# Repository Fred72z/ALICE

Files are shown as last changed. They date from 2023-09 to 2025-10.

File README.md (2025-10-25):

# EXTENSION MULTIPORTS ALICE #

Cette extension permet d'étendre les possibilités des ordinateurs MATRA ALICE (4K, 32 et 90).
Elle ajoute :
 - 2 Ports joystick DB9
 - 16K de RAM
 - 2 ports d'extension à l'arrière identiques à celui de l'ALICE
 - un port cartouche sur le dessus.

Elle est aussi compatible avec le MATRA MC10 (identique à l'ALICE 4K).

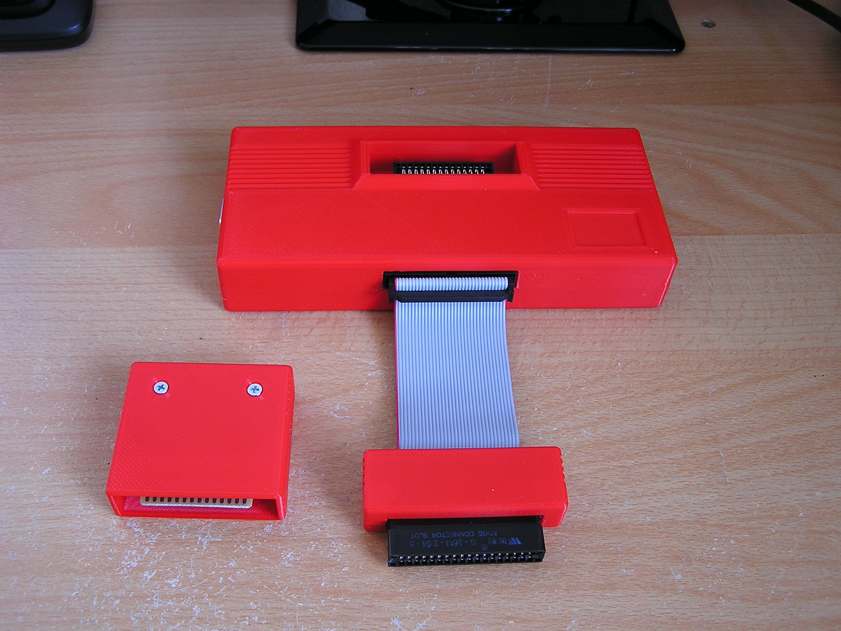
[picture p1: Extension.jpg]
Extension multiports Optional Title


Ce projet a été réalisé conjointement avec 6502man pour la partie software.

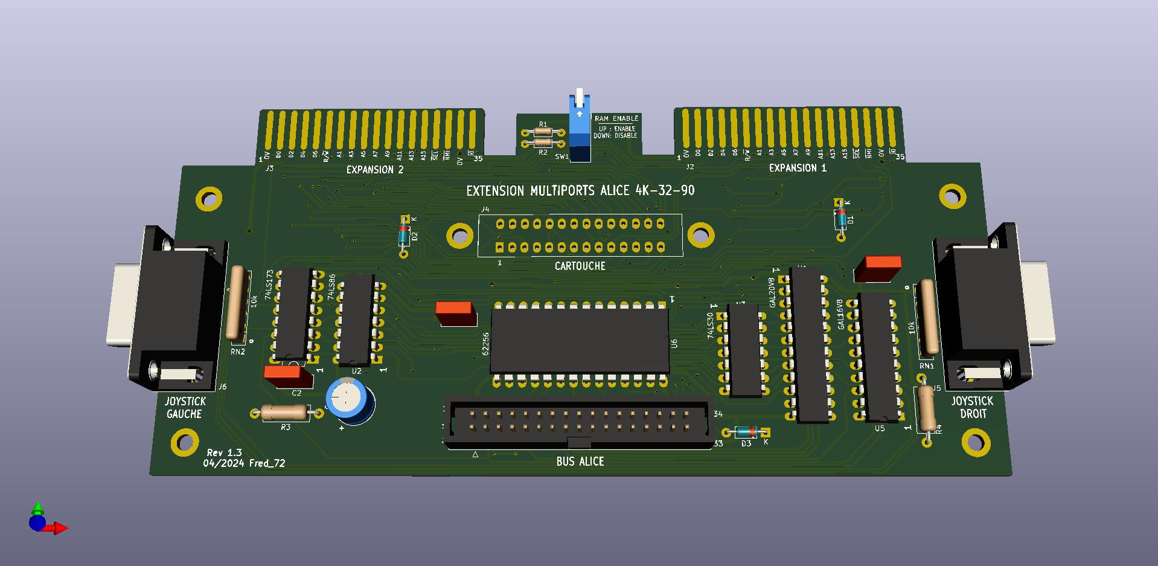
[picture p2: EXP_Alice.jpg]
Platine principale Optional Title


 Ports joystick :\
 Les ports joystick sont compatibles avec l'extension joystick commercialisée à l'époque.
 Ils occupent les adresses $BF30 (48944) pour le joystick droit et $BF34 (48948) pour le joystick gauche.
 
 RAM :\
 La RAM de 16Ko occupe les adresses [$5000-8FFF]. Elle peut être désactivée par un micro interrupteur accessible à l'arriére du boîtier. Une version modifiée du programme du PLD permet d'étendre cette RAM à 24K [$5000-AFFF] permettant de transformer un ALICE 32 en ALICE 90. Toutefois cette modification rend l'extension incompatible avec le 4K.
 
 Ports d'extension :\
 Le boîtier dispose de 2 ports d'extension à l'arrière permettant de régler le gros problème de l'ALICE qui ne permet de connecteur qu'une seule extension à la fois.
 Les 2 ports sont identiques à celui de l'ALICE. Les signaux SEL sont connectés via des diodes afin de permettre l'utilisation de plusieurs extensions simultanément.
 
 Port cartouche :\
 Un port cartouche est placé sur le dessus du boîtier. Il permet d'ajouter des cartouches de jeux ou de langage.
 Ces cartouches disposent d'une mémoire de 64Ko répartie en 8x8Ko ou 4x16Ko selon l'utilisation.

 Mode cartouche :\
 Dans ce mode, la cartouche est vue dans la zone [$1000-2FFF] soit 8Ko. Il est possible de choisir la mémoire parmi 8 blocs (8x8Ko). Le choix du bloc se fait par une écriture dans la zone [$1000-1FFF].
 Le bloc '0' est automatiquement sélectionné à la mise sous tension.
 
 Mode ROM :\
 Dans ce mode, la cartouche est vue dans la zone [$C000-FFFF] soit 16Ko. Il est possible de choisir la mémoire parmi 4 blocs (4x16Ko). Le choix du bloc se fait par une écriture dans la zone [$C000-CFFF].
 Le bloc '0' est automatiquement sélectionné à la mise sous tension.

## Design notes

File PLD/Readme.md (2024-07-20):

Le GAL 16V8 se charge des joysticks. Le programme est identique sur toutes les versions.

Le GAL 20V8 se charge du décodage des adresses. Il est disponible en 3 version:

- 20V8_16K : Limite la mémoire RAM additionelle à 16K pour l'Alice 4K et le Tandy MC10.

- 20V8_24K : Autorise le maximum de RAM additionelle (24K) pour l'Alice 32.

- 20V8_20K : Version spéciale pour l'Alice 4K et le Tandy MC10 ayant une extension RAM interne de 8K. Dans ce cas la RAM additionnelle commence à $6000.

 Remarque: En pratique, il est possible d'utiliser la version 24K sur l'Alice 4K sans problème.

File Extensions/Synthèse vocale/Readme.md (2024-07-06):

# EXTENSION SYNTHESE VOCALE ALICE

Cette extension permet de donner la parole aux ordinateurs MATRA ALICE (32 et 90).
L'extension est compatible 4K, mais pas son logiciel.
L'extension est accompagnée d'une cartouche qui contient un programme de démonstration et du vocabulaire.
La sortie son se fait uniquement sur un jack 3.5mm.

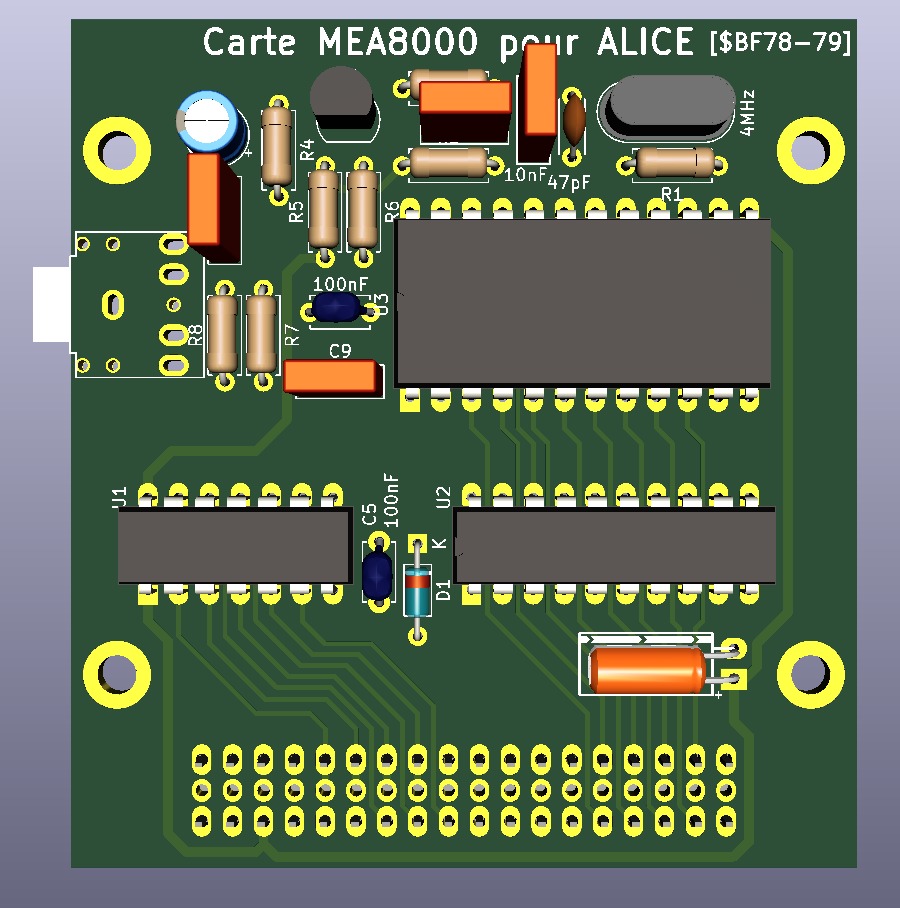
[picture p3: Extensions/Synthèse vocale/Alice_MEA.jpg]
Platine Vocale Optional Title


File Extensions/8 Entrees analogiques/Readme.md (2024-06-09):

# EXTENSION 8 ENTREES ANALOGIQUES

Cette extension permet d'ajouter 8 entrées analogiques [0-5V] aux ordinateurs MATRA ALICE (4K, 32 et 90).

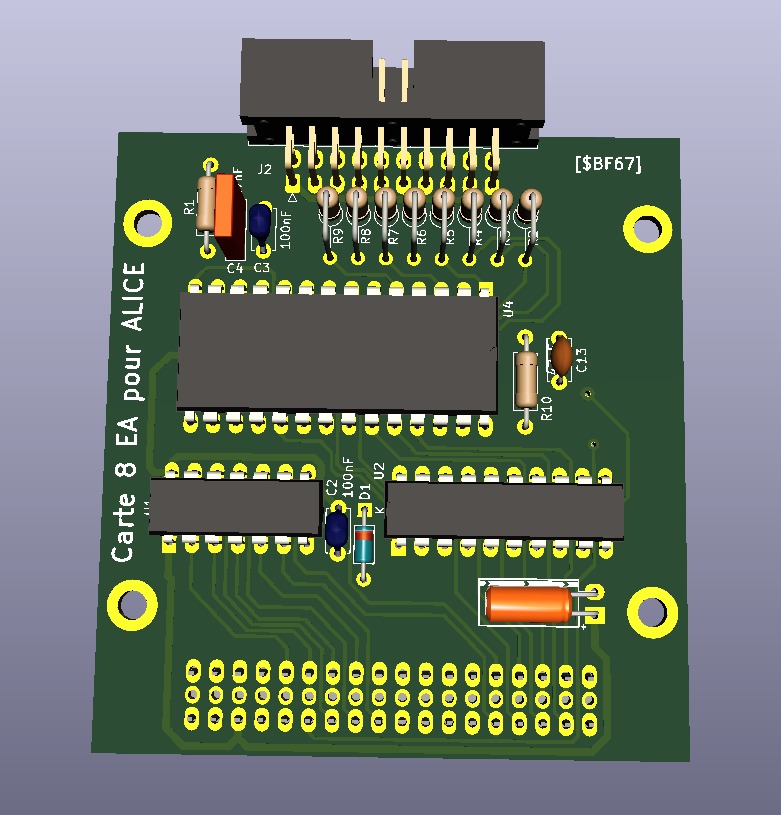
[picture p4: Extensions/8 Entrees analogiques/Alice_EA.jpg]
Platine d'EA Optional Title


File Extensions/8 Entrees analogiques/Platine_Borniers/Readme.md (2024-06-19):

# PLATINE BORNIERS

Cette platine permet de raccorder facilement la carte 8 Entrées analogiques au monde extérieur.
Le bornier d'alimentation permet de récupérer la masse à raccorder à la masse du ou des générateurs.
La sortie +5V est en série avec une résistance de 47 ohms afin d'éviter d'endommager l'ordinateur hôte en cas de court-circuit.
Un cavalier (JP1) permet de shunter cete résistance mais attention à ne pas faire de court-circuit.
La sortie peut fournir au maximum 100mA.

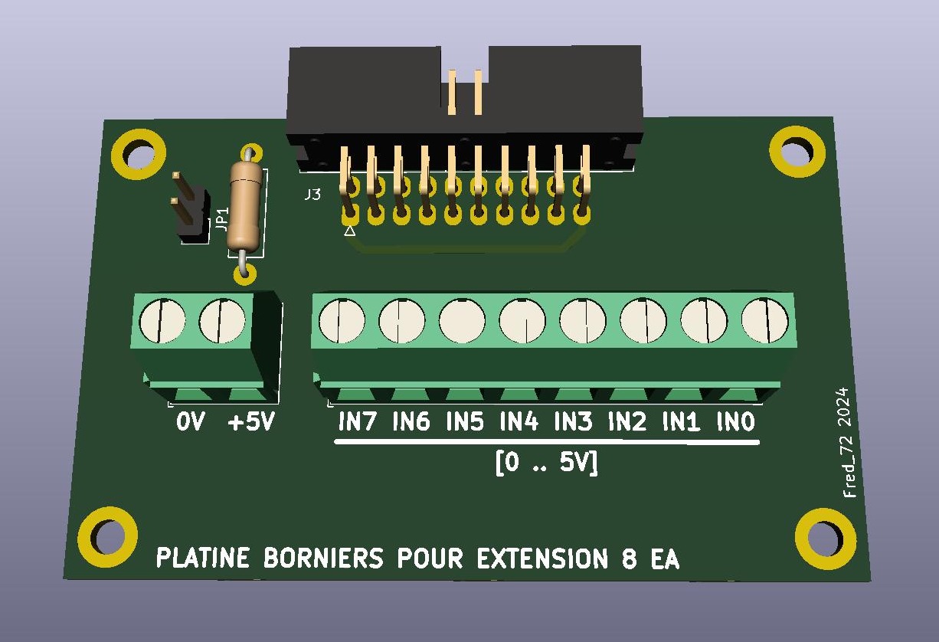
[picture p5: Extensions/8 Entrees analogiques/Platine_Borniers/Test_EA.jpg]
Platine borniers Optional Title


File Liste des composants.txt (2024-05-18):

Liste des composants pour l'extension multiports Alice

* Platine principale *

R1,R2	: Résistance 4.7k 1/8W
R3,R4	: Résistance 47R 1/2W
C1	: Condensateur 470µF/16V
RN1,RN2	: Réseau RR5 10k (5 résistances avec un point commun)
C2,C3,C4	: Condensateur 100nF
D1,D2,D3	: BAT85 (diode schottky)
U1	: GAL 16V8
U2	: 74LS02
U3	: 74LS30
U4	: 74LS173
U5	: GAL 20V8
U6	: 62256 ou équivalent (SRAM 32Kx8)
Supports de CI (2x14br, 1x16br, 1x20br, 1x24br étroit, 1x28br large

J1	: Connecteur IDC 2x17 mâle 90°
J4	: Connecteur bord de carte 2x14br droit (ex:https://fr.aliexpress.com/item/4000490392119.html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)
J5,J6	: Connecteur DR9 mâle 90° (ex: https://fr.aliexpress.com/item/32972036701.html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) Attention à la longeur!
SW1	: Dip switch "piano" 1 contact
4 vis M3x6mm pour les DR9
4 vis tôle 2.9x6mm à tête bombée
4 vis agglo 3x20mm

* Adaptateur *

J1	: Connecteur IDC mâle 34 broche pour câble (ex:https://fr.aliexpress.com/item/4001213959287.html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 )
J2	: Connecteur bord de carte 2x18 br droit (ex: https://fr.aliexpress.com/item/4000490392119.html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)
10cm câble nappe 34 conducteurs
2 vis Agglo 3x13mm

* Cartouche *

U1	: EPROM 27C512 ou EEPROM W27C512
C1	: Condensateur 220nF pas 5mm
Support de CI 28br large
2 vis Agglo 3x13mm

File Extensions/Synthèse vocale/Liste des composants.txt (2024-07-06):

Reference, Quantity, Value, Footprint, Datasheet
C1 : 1x 10nF pas 5mm
C2 : 1x 47pF, pas 5mm
C3,C9 : 2x 22nF pas 5mm
C4,C7 : 2x 47µF/16V radial
C5,C6,C8 : 3x 100nF pas 5mm
D1 : 1x BAT85

J1 : 1x connecteur bord de carte 2x18 broches pas 2.54mm ou barette 2x18 broches mâle 90° pcb
J2 : 1x Connecteur jack 3.5mm PJ-307
Q1 : 1x P2N2907 (TO92)
R1 : 1x 1 Mohms 1/4W
R2 : 1x 22 kohms
R3,R6 : 2x 470 ohms
R4 : 1x 1.5 kohms
R5 : 1x 47 ohms
R7,R8 : 2x 10 kohms
U1 : 1x 74LS30
U2 : 1x,GAL16V8
U3 : 1x,MEA8000
Y1 : 1x Quartz 4MHz

1x Support CI 14 boches
1x Support CI 20 boches
1x Support CI 24 boches large

1x Boîtier 3D
4x vis tôle 2.9x6.5mm

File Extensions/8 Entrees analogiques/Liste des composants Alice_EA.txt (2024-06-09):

C1 : 1 x 47µF/16V Radial pas 2.54mm
C2 C3 : 2x 100nF pas 5mm
C4 : 1x 47pF  pas 5mm
C5 : 1x 47nF  pas 5mm 
C6 à C13 : 8x 1nF CMS 0805
C13 : 1x47pF
D1 : 1x BAT85
J1 : 1x Connecteur bord de carte 2x18 broches pas 2.54mm pour PCB ou barette double rangée 2x18 broches pas 2.54mm 90°
J2 : 1x Connecteur IDC 2x10 broches pas 2.54mm Horizontal
R1 : 5.6kohms 1/4W
R2 : 10 ohms 1/4W
R3 à R10 : 8x 1kohms 1/4W
U1 : 1x 74LS30
U2 : 1x GAL16V8B
U3 : 1x ADC0808 ou ADC0809 (le ADC0808 est un peu plus précis que le ADC0809)
1x Support CI 14 broches
1x Support CI 20 broches
1x Support CI 28 broches
4 vis agglo 3x20mm

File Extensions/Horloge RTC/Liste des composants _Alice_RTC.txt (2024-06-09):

C1 : 1 x 47µF/16V Radial pas 2.54mm
C2 C3 : 2x 100nF pas 5mm
D1 : 1x BAT85
J1 : 1x Connecteur bord de carte 2x18 broches pas 2.54mm pour PCB ou barette double rangée 2x18 broches pas 2.54mm 90°
U1 : 1x 74LS30
U2 : 1x GAL16V8B
U3 : 1x DS12C887(+)
1x Support CI 14 broches
1x Support CI 20 broches
1x Support CI 24 broches
4 vis agglo 3x19mm

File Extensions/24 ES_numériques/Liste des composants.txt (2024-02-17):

Liste des composants Carte E/S pour Alice

U1 : 74LS30
U2 : GAL 16V8
U3 : 82C55 ou 8255
C1 : 47µF /16V radial
C2,C3 : 100nF pas 5mm
J1 : Connecteur bord de carte 2x18 broches pas 2.54mm
J2 : Connecteur IDC mâle 30 broches 90°

1x Support CI 40 broches/15.24mm
1x Support CI 20 broches/7.62mm
1x Support CI 14 broches/7.62mm

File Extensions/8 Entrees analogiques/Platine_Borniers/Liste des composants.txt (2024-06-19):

J1 : 1x Bornier 2 broches pas 5mm
J2 : 1x Bornier 8 broches (ou 4x2 broches) pas 5mm
J3 : 1x Connecteur IDC 2x10 broches pcb à 90°
R1 : 47 ohms 1/2W
4 vis tôle 2.9x6.5mm

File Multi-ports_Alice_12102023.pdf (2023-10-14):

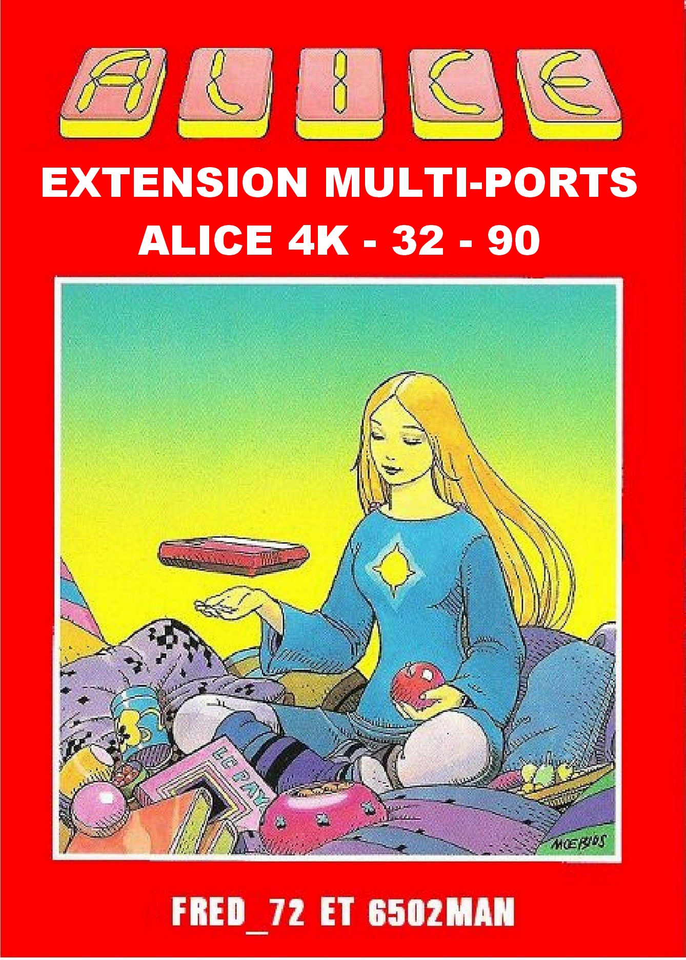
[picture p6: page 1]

Fred_72 | Version du 12/10/2023

# Extension Multi-Ports Alice

L’extension multi-ports permet d’étendre les capacités de votre ordinateur ALICE et de découvrir un nouveau monde de possibilités en ajoutant tous les périphériques indispensables à votre ordinateur à l’aide d’un seul boîtier. Le raccordement à votre ordinateur est assuré par un petit câble en nappe muni d’un connecteur spécifique à chaque extrémité.

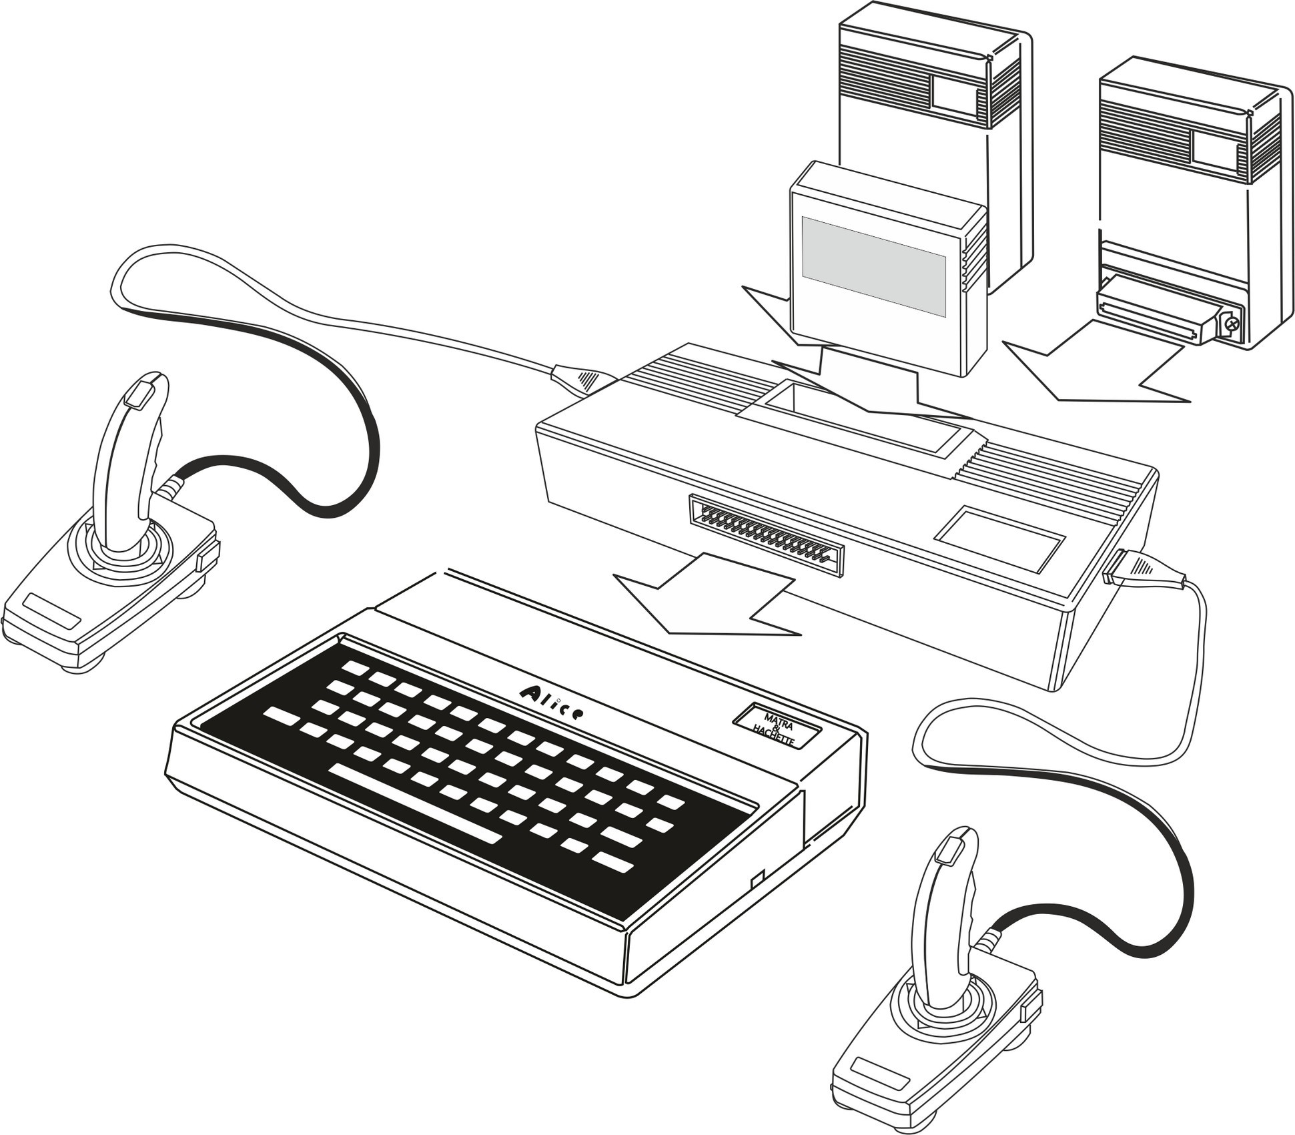
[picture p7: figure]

Vous disposez ainsi de :
- 2 ports joystick
- 2 ports d’extension additionnels
- 1 port cartouche
- 16Ko de RAM supplémentaires

Tous ces éléments sont automatiquement détectés à la mise sous tension, Il suffit de brancher le boîtier d’extension multi-ports derrière votre ordinateur ALICE et c’est tout.

Attention : Pour éviter tout dommage à votre ordinateur ALICE, il faut impérativement débrancher l’alimentation avant de brancher l’extension.

### Vue arrière

L’arrière du boîtier présente 2 ports d’extension et un petit interrupteur de configuration.

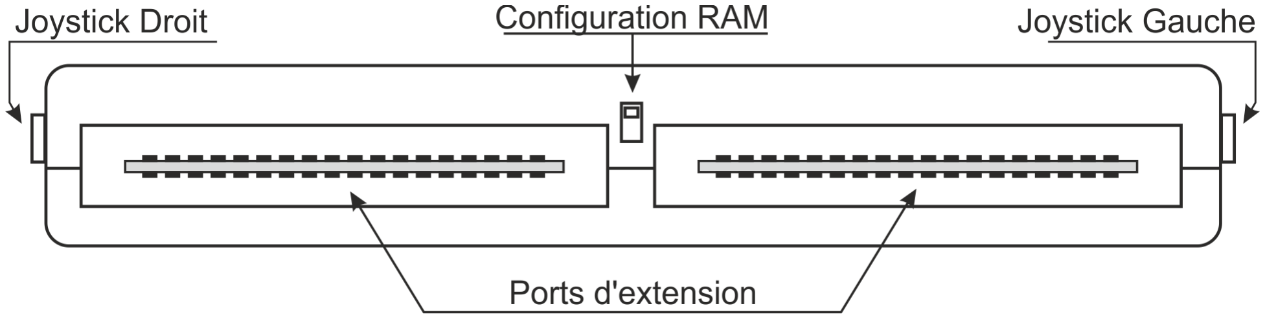
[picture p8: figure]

### Ports d’extension

Le boîtier dispose de 2 ports d’extension identiques à celui de votre ordinateur ALICE, Cela permet de connecter 2 périphériques supplémentaires comme par exemple une carte son, une carte d’E/S ou tout autre périphérique à venir.
Le brochage est identique à celui de votre ordinateur sauf la broche 35 qui reçoit un signal de sélection IO (sortie) actif à l’état bas lorsque les adresses sont dans la plage [$BF50-BFEF]. Il permet de simplifier le décodage d’adresse des futurs périphériques.
1 | GND
3 | D0
5 | D2
7 | D4
9 | D6
11 | R/W
13 | A1
15 | A3
17 | A5
19 | A7
21 | A9
23 | A11
25 | A13
27 | A15
29 | SEL
31 | NMI
33 | GND
35 | IO
2 | GND
4 | D1
6 | D3
8 | D5
10 | D7
12 | A0
14 | A2
16 | A4
18 | A6
20 | A8
22 | A10
24 | A12
26 | A14
28 | E
30 | RST
32 | +5V (300mA)
34 | GND
36 | SON

### Port Joystick

Le boîtier possède 2 ports joystick compatibles ATARI identiques à ceux proposés par l’extension joystick. Ils sont disposés de chaque côté du boîtier d’extension. Leur brochage est rappelé ci-dessous :

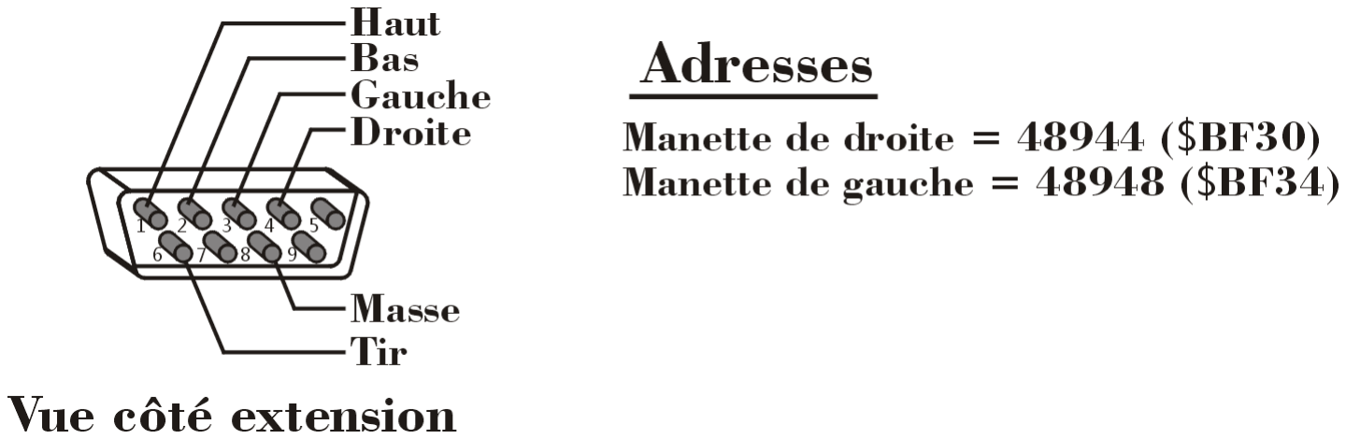
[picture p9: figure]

### Configuration RAM

L’extension permet d’ajouter 16Ko de mémoire RAM à votre ordinateur ALICE. Cette mémoire se place dans la plage [$5000-8FFF]. Toutefois, elle n’est pas utile pour les ordinateurs ALICE 90. Elle peut donc être désactivée en baissant le petit levier de l’interrupteur de configuration à l’aide d’une pointe de crayon ou d’un petit tournevis.

Mémoire RAM activée

mémoire RAM désactivée

Remarque : Il est possible, moyennant la reprogrammation du PLD 20V8, d’augmenter la mémoire additionnelle à 24Ko. Cela permet de transformer votre ALICE 32 en ALICE 90. Mais avec cette modification, l’extension multi-ports n’est plus compatible avec l’ALICE 4K.

### Cartouches

Les cartouches permettent de stocker des logiciels accessibles instantanément sans avoir à les charger au préalable depuis le magnétophone. Elles se présentent comme un petit boîtier renfermant un circuit imprimé à 28 contacts. La cartouche ne peut être insérée que dans un seul sens (étiquette vers soi) ce qui évite toute erreur de branchement.
Les cartouches peuvent être ouvertes pour accéder au circuit imprimé. Il suffit de dévisser 2 vis situées derrière l’étiquette.

ATTENTION : Vous devez couper l’alimentation de l’ordinateur avant de mettre ou d’enlever une cartouche.

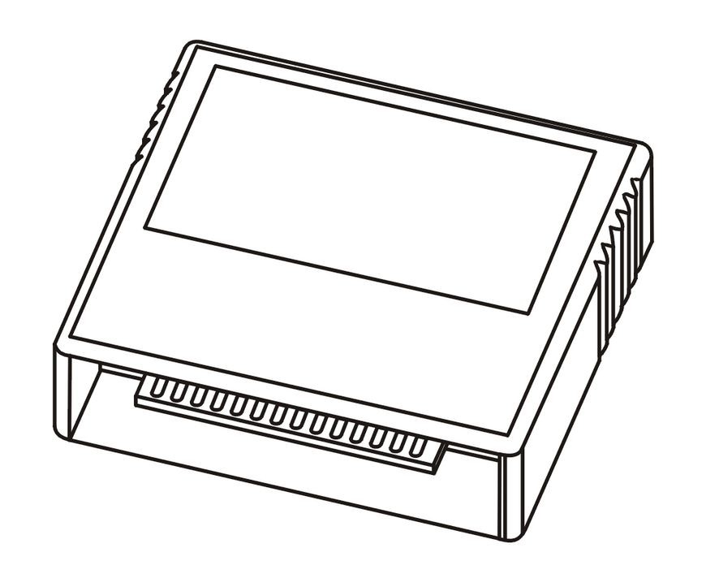
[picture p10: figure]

Elles sont utilisables selon 2 modes :

* Mode CARTOUCHE *
Ce mode permet de disposer de programmes directement dans la mémoire de l’ordinateur tout en gardant un fonctionnement normal de l’ordinateur.
La cartouche est placée dans la zone [$1000-2FFF] soit 8Ko. Il est possible de définir jusqu’à 8 blocs mémoire différents (un seul accessible à la fois) pour un total de 8x8Ko=64Ko.
La sélection du bloc mémoire se fait par l’écriture dans la zone [$1000-1FFF] (4096 à 8191) du numéro du bloc (de 0 à 7).
Exemple : POKE 4096,3 | Sélectionne le bloc N°3
Valeur | N° Bloc | Plage mémoire EEPROM
0 | 0 | 0000-1FFF
1 | 1 | 2000-3FFF
2 | 2 | 4000-5FFF
3 | 3 | 6000-7FFF
4 | 4 | 8000-9FFF
5 | 5 | A000-BFFF
6 | 6 | C000-DFFF
7 | 7 | E000-FFFF

* Mode ROM *
Ce mode permet de remplacer la ROM de l’ALICE par une version différente, un nouveau langage, etc.
La cartouche est placée dans la zone [$C000-FFFF] soit 16Ko à la place de la ROM interne de l’ALICE. Il est possible de définir jusqu’à 4 blocs mémoire différents (un seul accessible à la fois) pour un total de 4x16Ko=64Ko.
La sélection du bloc mémoire se fait par l’écriture dans la zone [$C000-CFFF] (49152 à 53247) du numéro du bloc (de 0 à 7).
Valeur | N° Bloc | Plage mémoire EEPROM
0 | 0 | 0000-3FFF
1
2
1 | 4000-7FFF
3
4
2 | 8000-BFFF
5
6
3 | C000-FFFF
7

La ROM avec le système BASIC (bloc 0) faisant fonctionner l’ordinateur, le changement de bloc ne peut se faire qu’avec un programme écrit en langage machine en ayant pris soin d’interdire les interruptions. Toute autre méthode entraîne un plantage immédiat de l’ordinateur.

Remarque : A la mise sous tension, le bloc 0 est automatiquement sélectionné quelque soit le mode.

Le mode de fonctionnement de la cartouche est déterminé par le cavalier JP1. Un circuit ouvert (par défaut) correspond au mode CARTOUCHE tandis qu’un circuit fermé (pont de soudure) correspond au mode ROM.

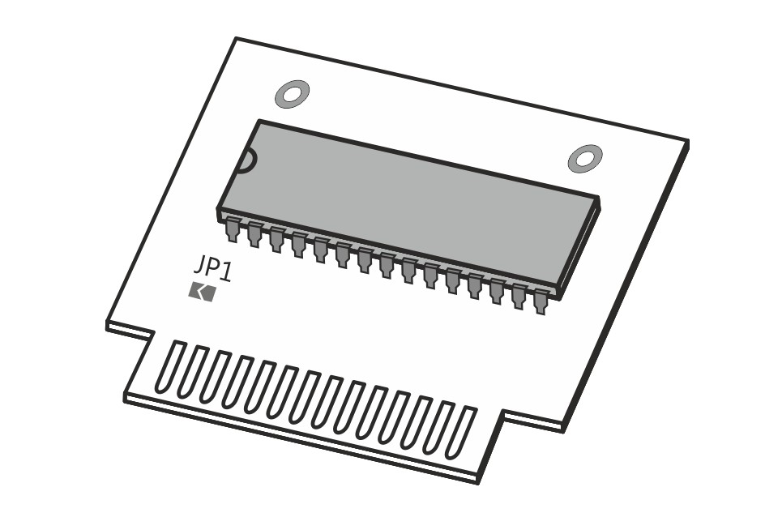
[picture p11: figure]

Le circuit imprimé de la cartouche peut être inséré seul dans le connecteur cartouche de l’extension multi-ports. Cette disposition est notamment plus pratique lors de la mise au point d’un programme. Il doit être inséré avec le côté pistes vers vous.

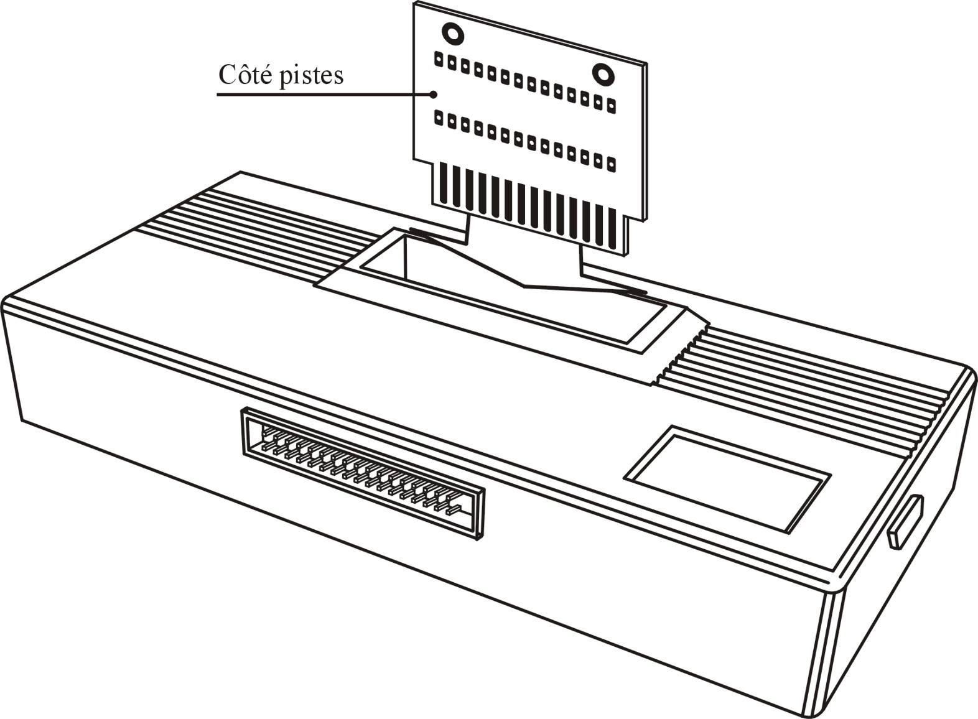
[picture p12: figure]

Remarque : L’insertion du circuit imprimé dans le mauvais sens dans le port cartouche peut endommager gravement votre ordinateur ALICE. Il faut alors couper l’alimentation très rapidement avant de retirer le circuit imprimé du port cartouche.

### Cartouches de jeux

Les cartouches de jeux sont disponibles auprès de 6502man via le réseau de distribution habituel. Les titres disponibles actuellement sont :
Alice 4K
FlagonBird
Lost World Pinball
Pac-Man

Alice 32 et 90
Al’Berthe
Chenille
Crocky
Dessine-moi
Fringale (*)
Galaxion
Kangourou
Pillage cosmique
Tank
(*) Alice 90 uniquement

### Schéma du matériel

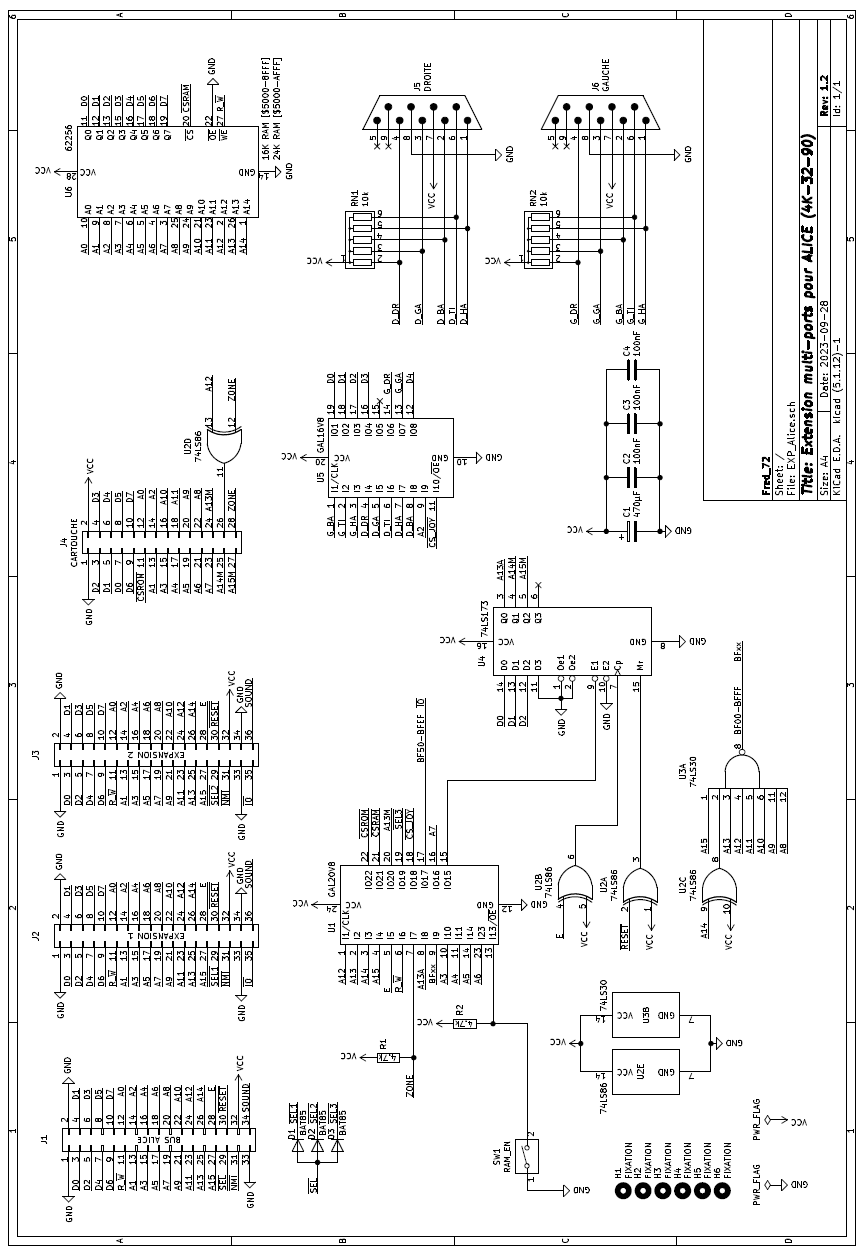
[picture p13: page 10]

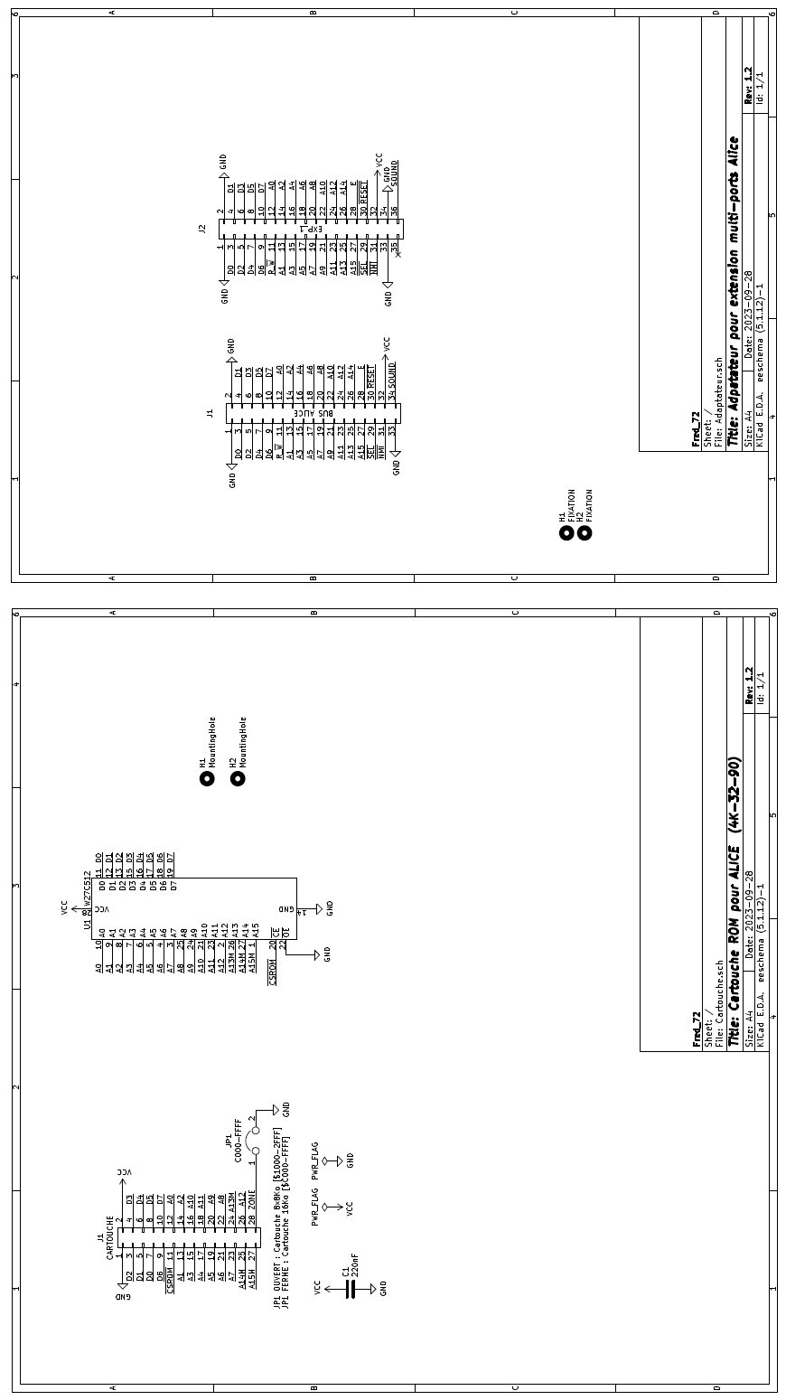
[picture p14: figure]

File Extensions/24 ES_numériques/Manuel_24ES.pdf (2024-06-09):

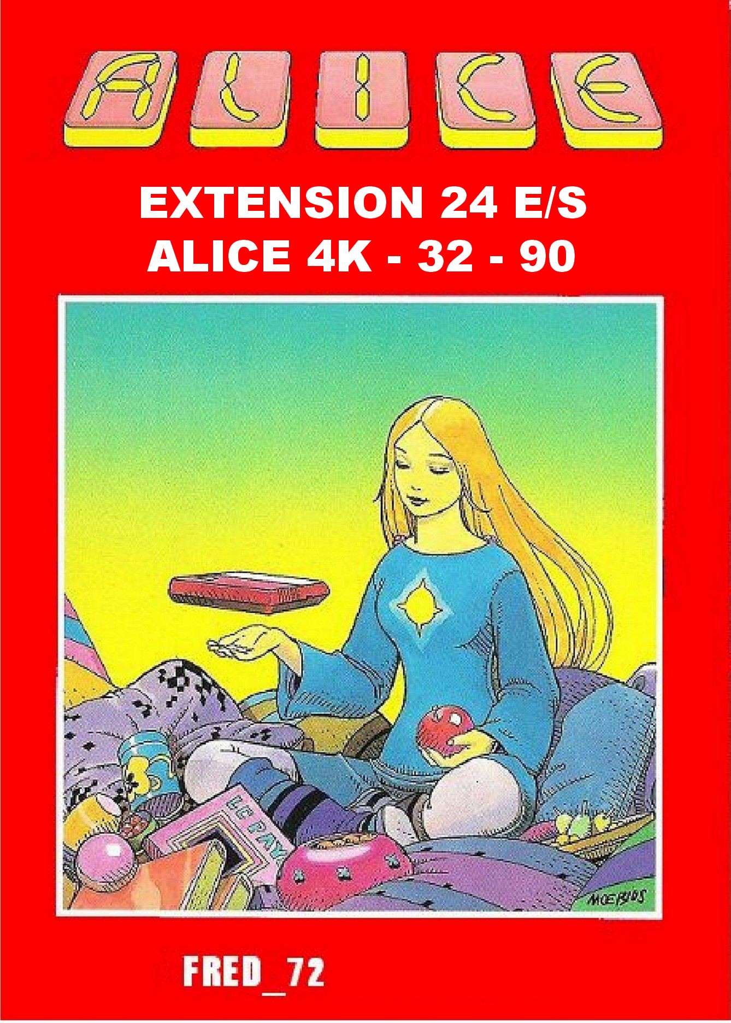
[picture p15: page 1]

Fred_72 | Version du 09/06/2024

# Extension 24 Entrées/Sorties pour Alice

L’extension 24 Entrées/Sorties permet d’ajouter 24 entrées ou sorties numériques [0V ou 5V] à votre ordinateur ALICE. L’extension est enfermée dans un boîtier qu’il suffit de brancher directement sur le bus d’extension situé à l’arrière de votre ordinateur.

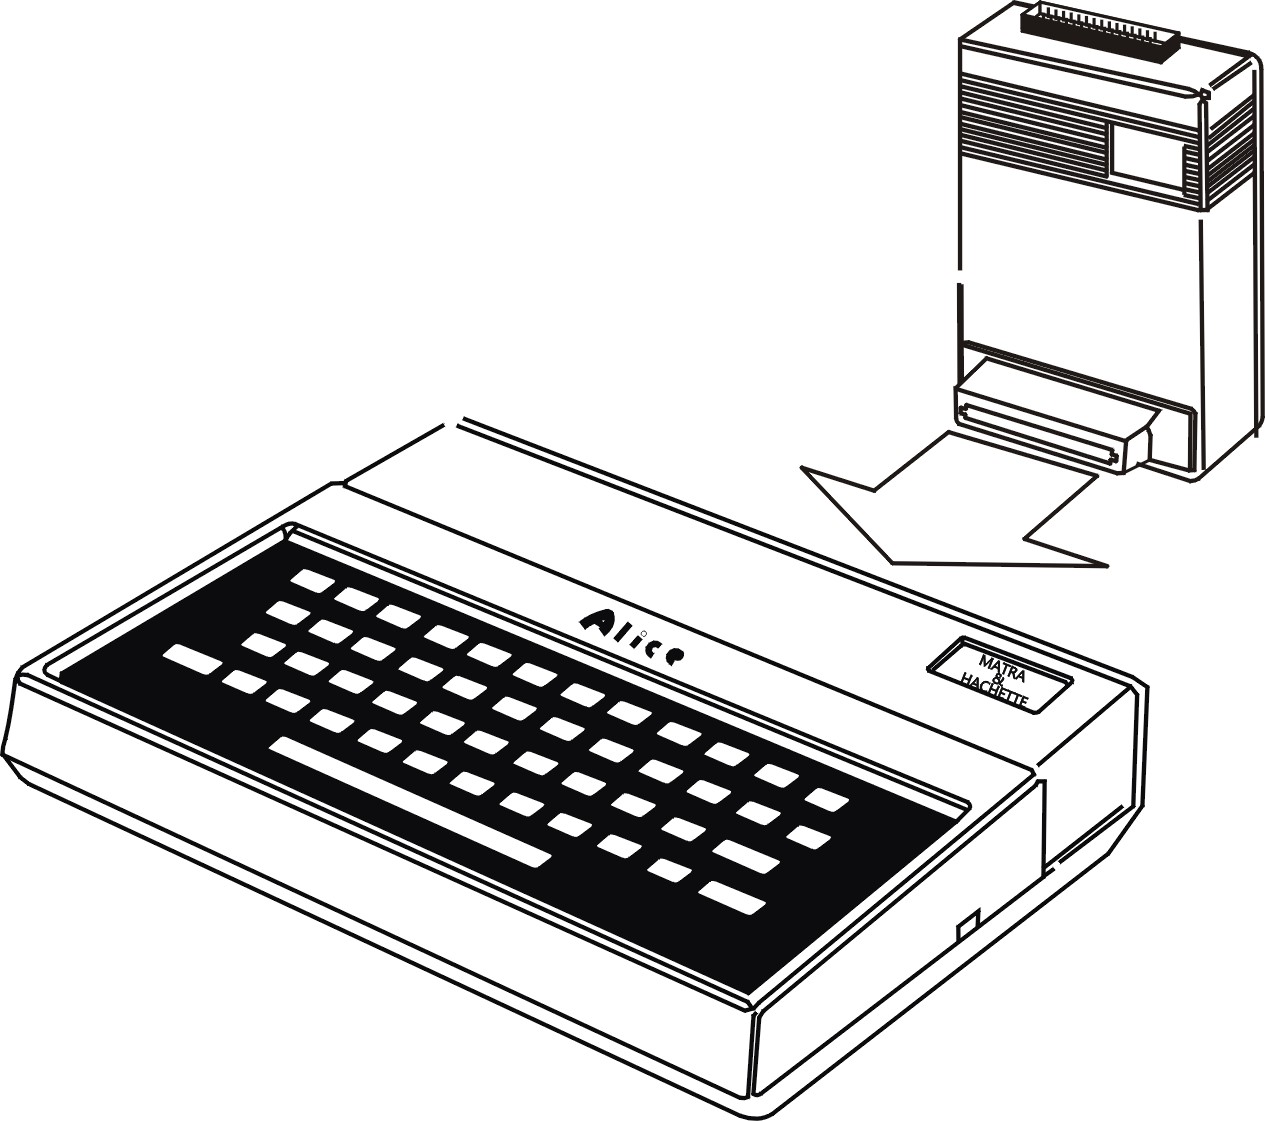
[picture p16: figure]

Les entrées sorties sont regroupées sur un petit connecteur IDC à 30 contacts situé sur le dessus du boîtier. Vous disposez de 24 entrées ou sorties découpées en 3 ports de 8 bits. Chaque port peut être configuré en entrée ou en sortie.
L’extension est accessible aux adresses 48992 à 48995 ($BF60 à $BF63).

Attention : Pour éviter tout dommage à votre ordinateur ALICE, il faut impérativement débrancher l’alimentation avant de brancher l’extension.

### Brochage du connecteur E/S

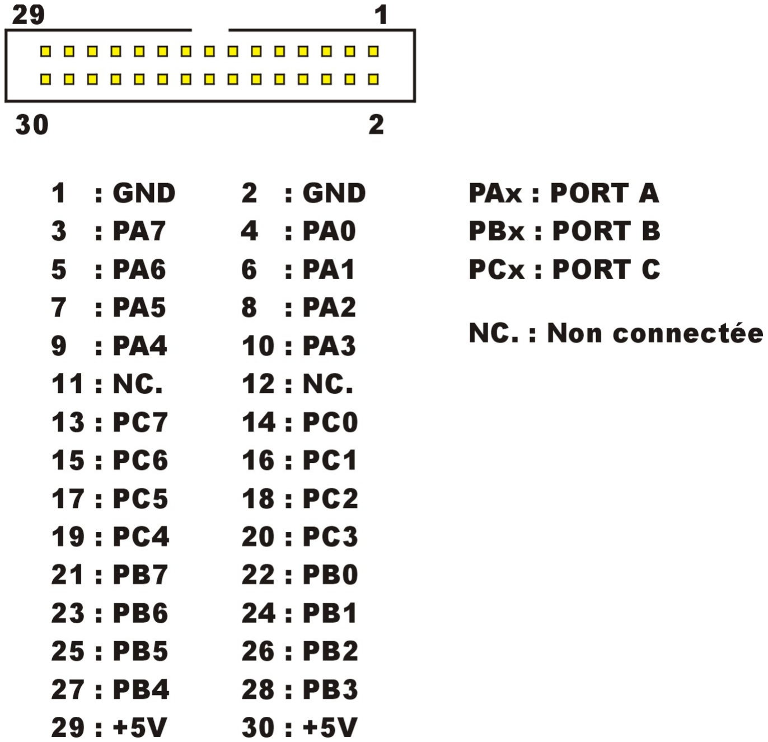
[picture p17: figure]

### Programmation

La programmation se fait à l’aide des commandes POKE et PEEK du BASIC ou bien en langage machine. Le 8255 dispose de 4 registres accessibles aux adresses suivantes :

Adresse (décimal) | Adresse (Hexadécimal) | Registre
48992 | BF60 | PORT A
48993 | BF61 | PORT B
48994 | BF62 | PORT C
48995 | BF63 | CONTROL

### Registre de contrôle [48995 -$BF63]

Le registre de contrôle permet de définir le sens de fonctionnement des ports (entrée ou sortie). Il doit être défini avant toute action sur les registres des ports.
Remarque : Le 8255 peut fonctionner selon 3 modes. Toutefois,seul le mode 0 (E/S indépendantes) sera abordé dans ce document.

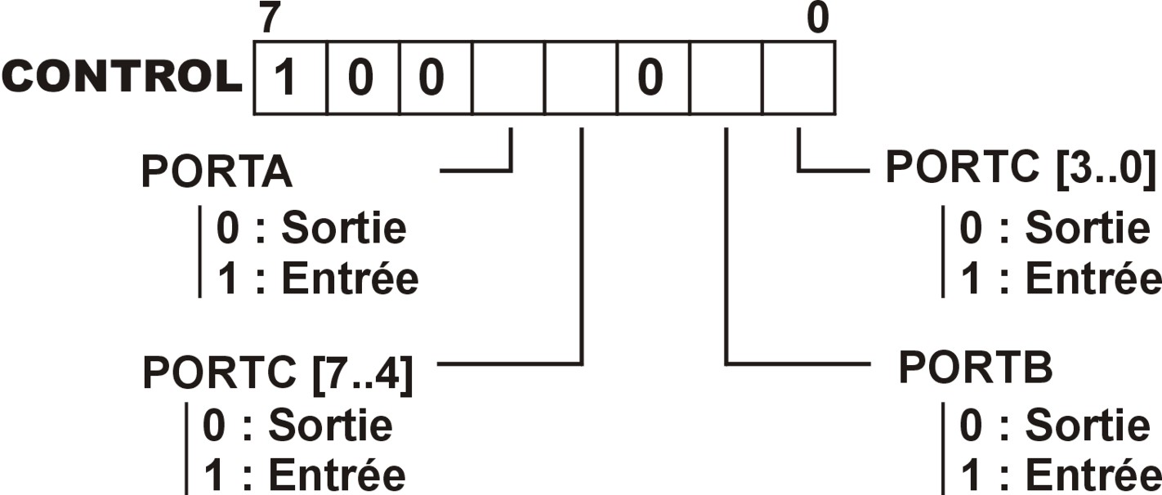
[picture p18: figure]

Le port C est coupé en deux, le sens de fonctionnement des 4 bits de poids faibles et des bits de poids forts peut être défini indépendamment, Les autres ports peuvent seulement être intégralement en entrée ou intégralement en sortie.

Exemple : POKE 48995,130 place les PORTA et PORTC en sortie et le PORTB en entrée.

### Registre des ports [48992 à 48994-$BF60 à $BF62] Port en sortie

Pour piloter les bits d’un port en sortie, il suffit d’utiliser l’instruction POKE. La valeur binaire sur 8 bits doit être traduite en décimal avant d’être utilisable par l’instruction POKE. Un bit à 0 signifie une tension de 0V tandis qu’un bit à 1 signifie une tension de 5V sur les différentes E/S du connecteur.

Exemple : POKE 48992,1 permet de mettre à ‘1’ (5V) la broche PA0 du PORTA, les autres broches sont à 0V.

### Port en entrée

Pour lire l’état d’un port en entrée, il suffit d’utiliser l’instruction PEEK, La valeur décimale lue donne l’état des 8 bis du port. Un bit à ‘0’ traduit une tension de 0V tandis qu’un bit à ‘1’ traduit une tension de 5V sur les différentes E/S du connecteur.
Pour lire un seul bit, il convient de filtrer la valeur lue à l’aide de l’opérateur AND.

Exemple : A=PEEK(48992) place dans A la valeur correspondant à l’état des 8 bits du PORT A.

Exemple : BP=PEEK(48992) AND 1 place dans BP une valeur traduisant l’état du seul bit 0 du PORT A. Si PA0=’1’, alors BP=1 sinon BP=0.

Exemple : BP=PEEK(48992) AND 16 place dans BP une valeur traduisant l’état du bit 4 du PORT A. Si PA4=’1’, alors BP=16 sinon BP=0.

### Schéma du matériel

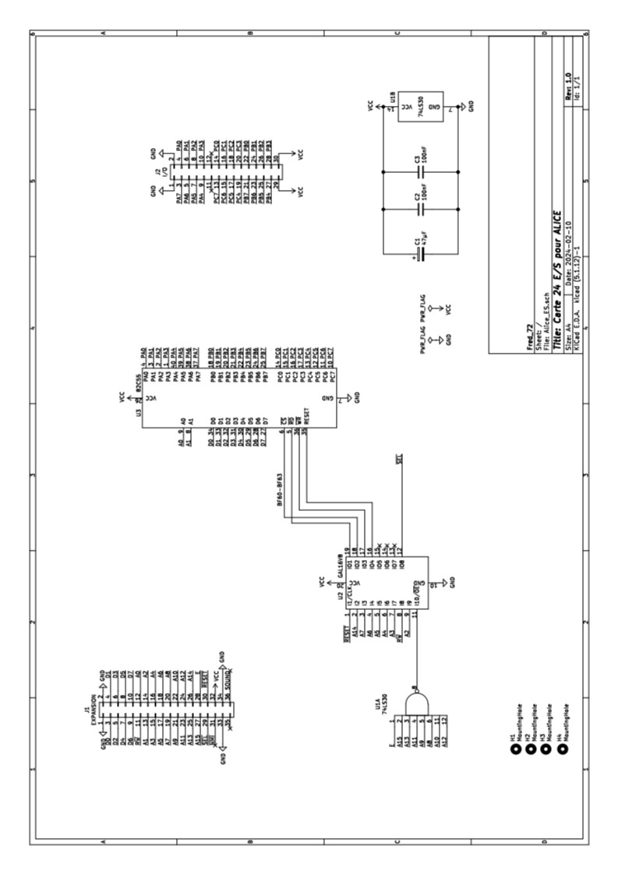
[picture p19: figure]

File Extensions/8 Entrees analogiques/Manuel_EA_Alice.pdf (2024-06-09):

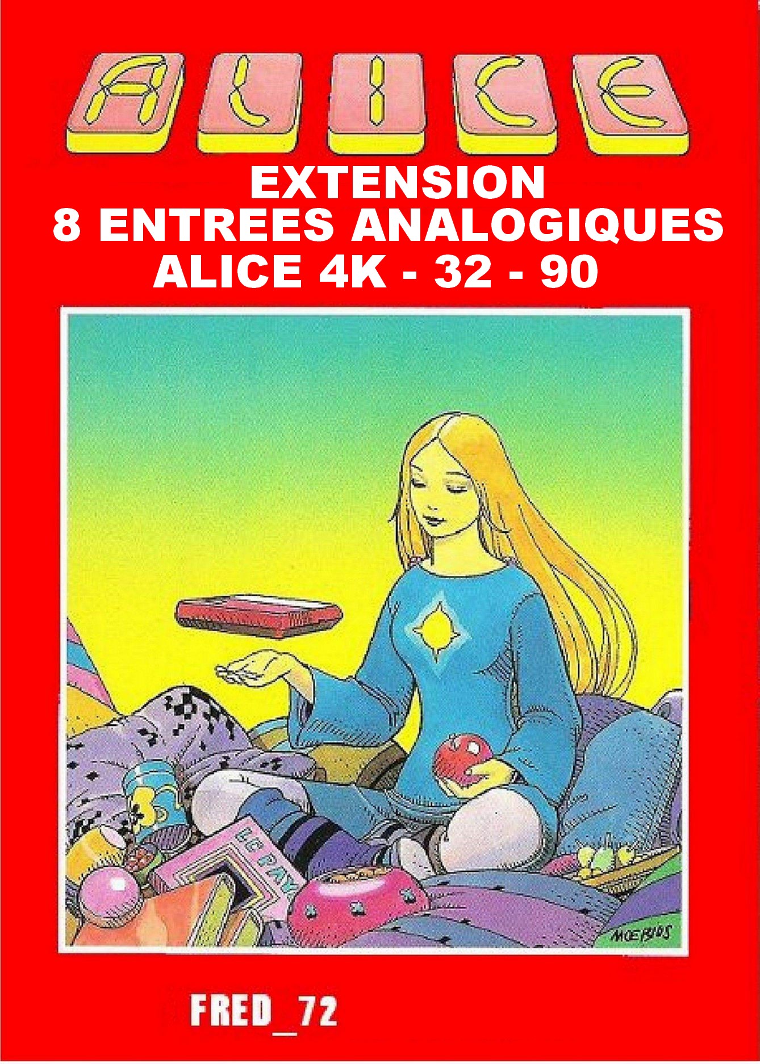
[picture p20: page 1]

Fred_72 | Version du 05/06/2024

# Extension 8 Entrées analogiques pour Alice

L’extension 8 entrées analogiques permet d’ajouter 8 entrées tension entre 0V et 5V à votre ordinateur ALICE. L’extension est enfermée dans un boîtier qu’il suffit de brancher directement sur le bus d’extension situé à l’arrière de votre ordinateur. Avec cette extension, vous pourrez utiliser des éléments comme des capteurs de lumière, température ou encore mesurer la position d’un potentiomètre.

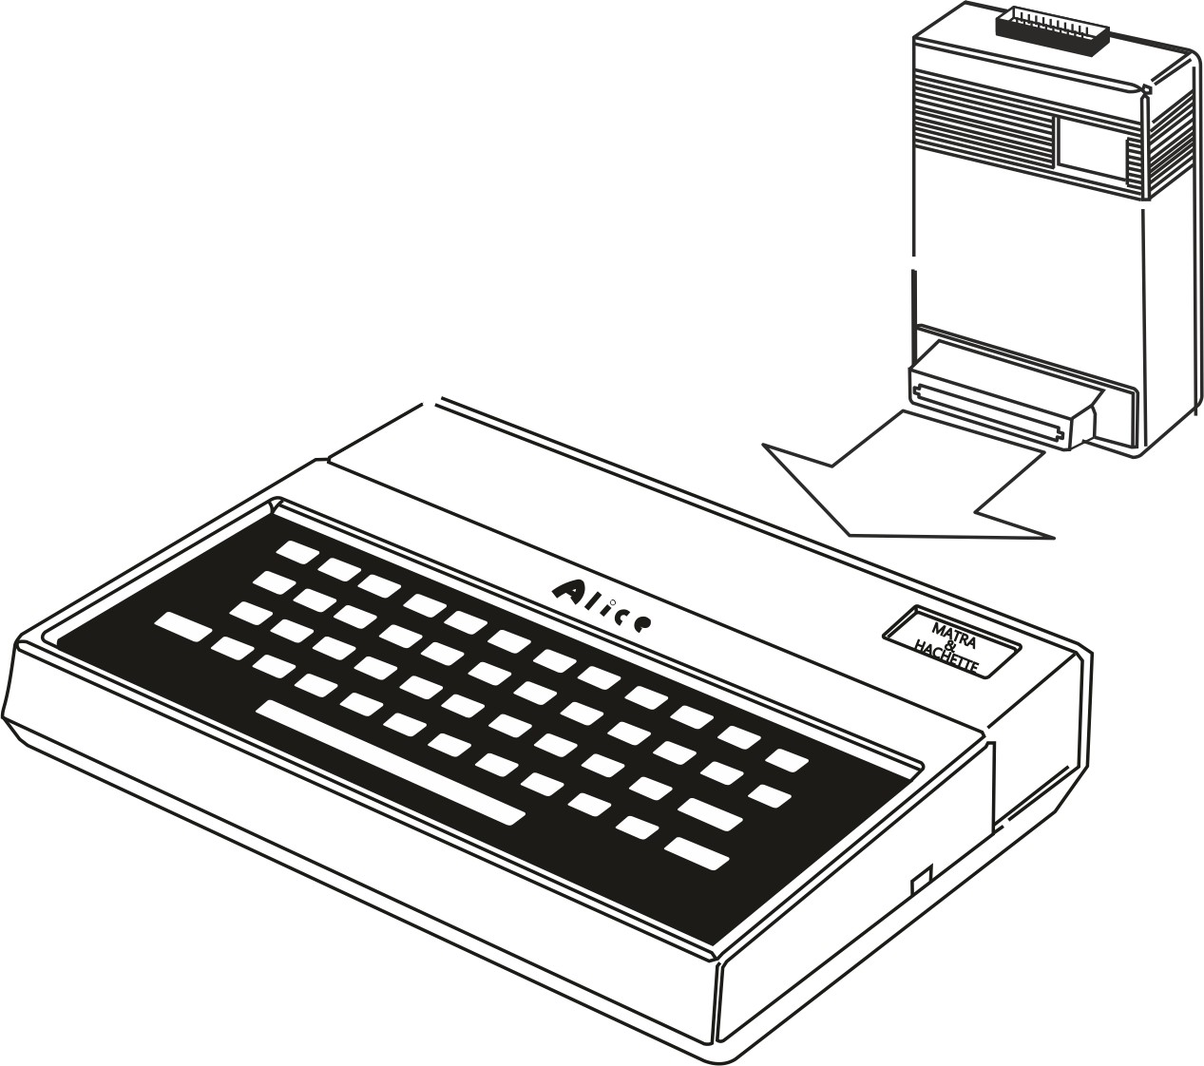
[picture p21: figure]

Les entrées sont regroupées sur un petit connecteur IDC à 20 contacts situé sur le dessus du boîtier. Chaque entrée peut recevoir une tension comprise entre 0 et 5V. La résolution du convertisseur utilisé est de 8 bits autorisant la mesure de 256 niveaux différents pour une gamme de 5V. L’extension est accessible à l’adresse 48999 ($BF67).

Attention : Pour éviter tout dommage à votre ordinateur ALICE, il faut impérativement débrancher l’alimentation avant de brancher l’extension.

### Brochage du connecteur E/S

Le connecteur comporte 20 broches réparties en 2 rangées de 10 broches. Une rangée permet de brancher les 8 signaux tandis que la 2ème est connectée à la masse (potentiel de référence). Enfin 2 broches (+5V) permettent d’alimenter un montage peu gourmand en énergie. Il faut toujours raccorder une des broches de masse (broches paires [2..20]) à la masse du montage fournissant la tension.

### Programmation

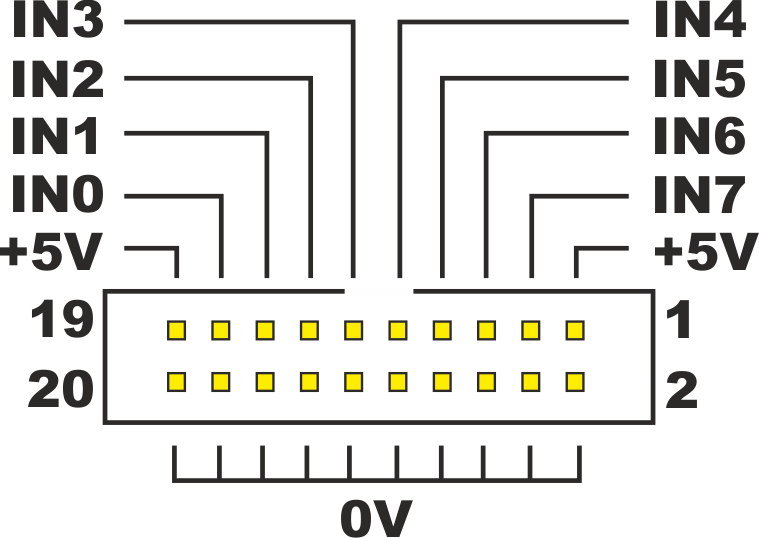
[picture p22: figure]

La programmation se fait à l’aide des commandes POKE et PEEK du BASIC ou bien en langage machine. En BASIC, les instructions peuvent se succéder tandis qu’en langage machine, une temporisation de 100µs minimum est nécessaire entre le lancement de la mesure et la lecture du résultat. Le convertisseur occupe une seule adresse ($BF67 soit 48999). Une écriture à cette adresse permet de choisir la voie (0 à 7) et lance la mesure. Une lecture à cette adresse retourne le résultat de la dernière mesure.
Le programme suivant permet de lancer une conversion sur la voie N°2 puis affiche la mesure sur l’écran de l’Alice.

### 10 POKE 48999, 2 20 PRINT PEEK (48999) 30 GOTO 10

Ce programme affiche une valeur entre 0 et 255. Pour obtenir la tension mesurée en volts à partir de la valeur numérique retournée par le convertisseur, il faut faire l’opération suivante :
Tension (V)=(5/256)*N (valeur lue)
le programme devient donc :

### 10 POKE 48999, 2 20 PRINT (5/256)*PEEK (48999) 30 GOTO 10

### Exemples d’application Lecture de la luminosité

En branchant une photorésistance (LDR diamètre 5mm) et une résistance conformément au schéma suivant (R=33kΩ), il est possible de mesurer la luminosité ambiante.

### 10 CLS

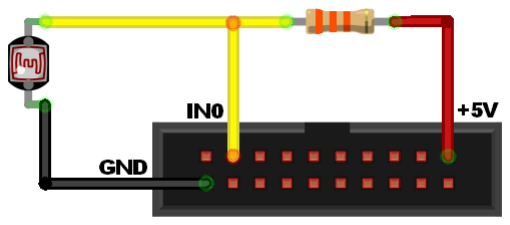
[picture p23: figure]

### 15 PRINT "MESURE DE LA LUMINOSITE" 20 POKE 48999, 0 30 LU=PEEK (48999) 40 PRINT @65 ,"LUMINOSITE =" ;LU ;" " 50 IF LU<103 THEN PRINT @129,"LUMINEUX" 60 IF LU>102 THEN PRINT @129,"SOMBRE " 70 GOTO 20

Le programme lance une mesure sur la voie 0 puis compare le résultat à la valeur 103 (valeur arbitraire). Si la mesure est supérieure à 103, c’est que la photorésistance est exposée à une lumière suffisante sinon c’est qu’elle est dans l’obscurité.

### Lecture d’un potentiomètre

En branchant un potentiomètre conformément au schéma suivant, il est possible de mesurer sa tension de sortie et donc de connaître la position de son axe. Cela permet par exemple d’entrer une valeur de commande pour votre programme afin d’ajuster sa vitesse d’exécution.

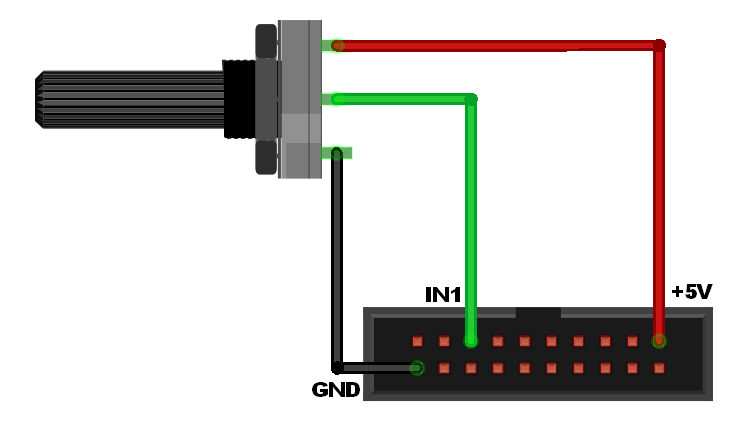
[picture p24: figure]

### 10 CLS 15 PRINT "MESURE DE TENSION" 20 POKE 48999, 1 30 LU=PEEK (48999) 40 PRINT @65 ,"TENSION =" ;(5/256)*LU ;" " 50 GOTO 20

Le programme lance une mesure sur la voie 1 puis calcule la tension délivrée par le potentiomètre et l’affiche sur l’écran.

### Schéma du matériel

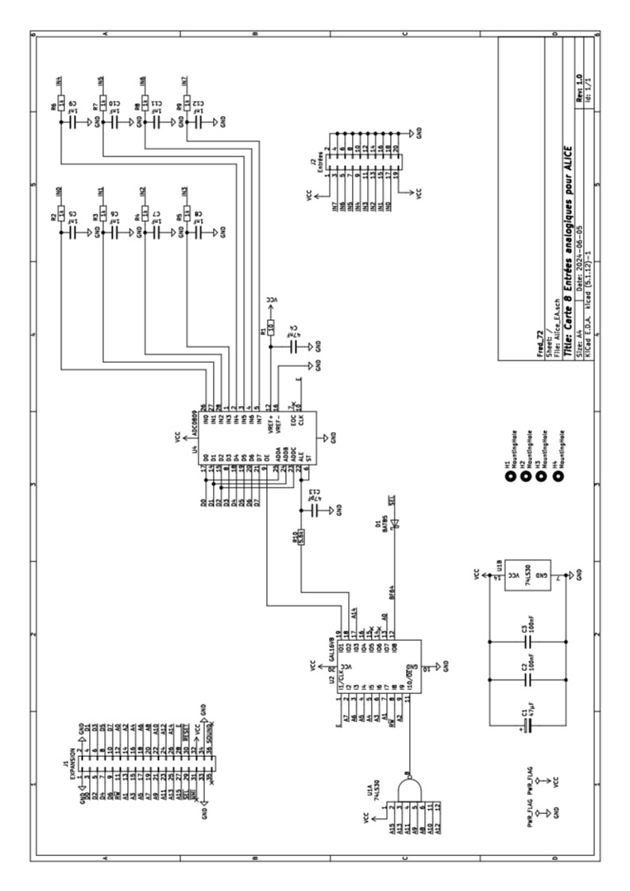
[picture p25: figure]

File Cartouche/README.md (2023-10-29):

# CARTOUCHE ALICE #

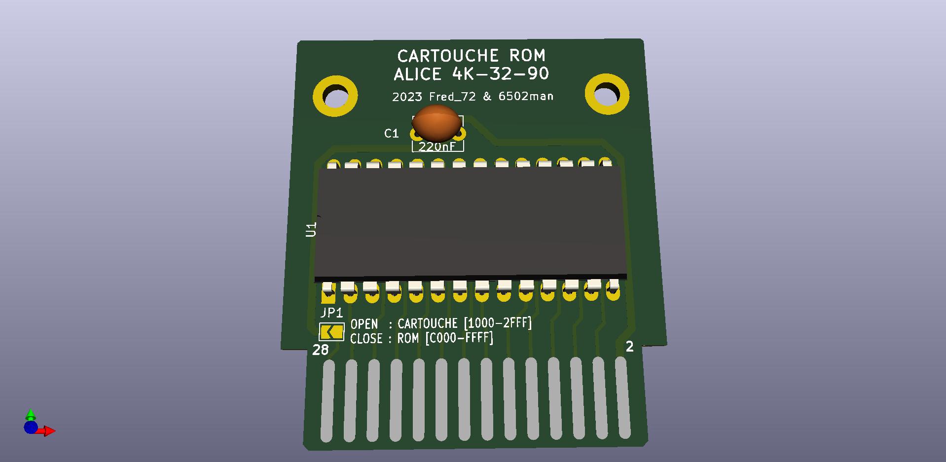
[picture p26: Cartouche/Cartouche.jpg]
Cartouche Alice Optional Title


Chaque cartouche contient une mémoire EPROM de 64Ko.

Le jumper JP1 permet de sélectionner le mode de fonctionnement:
ouvert : Mode cartouche. La cartouche est vue dans la zone [$1000-2FFF].
fermé  : Mode ROM. La cartouche est vue dans la zone [$C000-FFFF].

La conversion des programmes et la réalisation des jaquettes et des étiquettes ont été effectuées par 6502man.
Les programmes pour l'Alice 32 et 90 sont disponibles en mode cartouche (JP1 ouvert) et en mode ROM (AGS avec JP1 fermé).
Les programmes du répertoire AGS se distinguent des cartouches par un logo distinct et un démarrage automatique à l'allumage de l'ordinateur.

Liste des programmes disponibles au format cartouche :

# Alice 4K #
FlagonBird

LostWorld

Pacman

# Alice 32/90 #
Al Berthe

Chenille

Crocky

Dessine moi

Fringale

Galaxion

Kangourou

Pillage cosmique

Tank

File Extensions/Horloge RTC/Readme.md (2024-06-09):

# EXTENSION HORLOGE RTC

Cette extension permet d'ajouter une horloge/calendrier aux ordinateurs MATRA ALICE (4K, 32 et 90).

Platine RTC Optional Title

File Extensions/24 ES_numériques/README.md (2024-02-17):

# EXTENSION 24 ENTREES SORTIES ALICE

Cette extension permet d'ajouter 24 entrées-sorties aux ordinateurs MATRA ALICE (4K, 32 et 90).
Les 24 E/S sont réparties en 3 ports de 8 bits.

Platine d'ES Optional Title

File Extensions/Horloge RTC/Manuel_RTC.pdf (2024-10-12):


Fred_72 | Version du 12/10/2024

# Extension RTC pour Alice

L’extension RTC (Real Time Clock) permet d’ajouter une horloge et un calendrier à votre ordinateur ALICE. L’extension est enfermée dans un boîtier qu’il suffit de brancher directement sur le bus d’extension situé à l’arrière de votre ordinateur.


L’extension n’occupe que 2 adresses 49000 et 49001 ($BF68-BF69). L’horloge est alimentée par une pile longue durée qui permet de maintenir l’horloge à l’heure pendant plus de 10 ans. Le changement de date est automatique ainsi que le passage de l’heure d’été à l’heure d’hiver et inversement. Cette extension ajoute aussi 113 octets de mémoire RAM indirecte sauvegardée.

Attention : Pour éviter tout dommage à votre ordinateur ALICE, il faut impérativement débrancher l’alimentation avant de brancher l’extension.

### Structure mémoire de l’horloge

La mémoire de l’horloge (au total 128 octets) est accessibles via 2 adresses. L’adresse 49000 ($BF68) permet de sélectionner l’adresse mémoire de la RAM (0 à 127) de l’horloge tandis que l’adresse 49001 ($BF69) permet de lire ou d’écrire dans cette mémoire. La structure mémoire est représentée sur la Figure 1.


Les 14 premiers octets sont réservés à l’horloge ainsi que l’octet 50. Le reste de la mémoire peut être utilisé pour stocker des informations qui resteront mémorisées même si l’alimentation est coupée. La durée de vie de la batterie intégré au circuit horloge est d’environ 10 ans.

### Registres de l’horloge

L’horloge comporte 4 registres de configuration permettant de définir l’environnement matériel du circuit intégré. Une fois initialisés, il ne faut plus y toucher sous peine de voir l’horloge s’arrêter de fonctionner. Seuls les registres A et B peuvent être modifiés. Les valeurs par défaut sont :
Registre A = 43
Registre B = 15

Remarque : Les registres (Alarme) ne sont pas utilisés.

Figure 1: Structure de la mémoire de l'horloge RTC

### Programmation

La programmation se fait à l’aide des commandes POKE et PEEK du BASIC ou bien en langage machine.
L’utilisation est simple, Il suffit de lire les registres de l’horloge conformément à la Figure 1 pour obtenir les informations d’heure, de minutes, et de secondes.
Pour cela, il faut d’abord écrire le N° du registre à l’adresse 49000 puis ensuite lire l’adresse 49001 pour obtenir la valeur du registre.
Les heures, minutes, secondes, la date et le mois sont stockés au format binaire. Les valeurs ne nécessitent aucun post-traitement. Les années sont séparées en 2, le siècle stocké dans l’octet 50 (19 ou 20) et les dizaines et unités stockées dans l’octet 9.
Le jour de la semaine est numérique : 1 correspond à dimanche tandis que 7 correspond à samedi.

### Mise à l’heure de l’horloge

Ce programme BASIC permet de mettre l’horloge à l’heure.

### 10 PRINT "MISE A L’HEURE RTC" 20 INPUT "JOUR [1-7] :";J 30 INPUT "DATE [1-31] :";D 40 INPUT "MOIS [1-12] :";MO 50 INPUT "ANNEE [0-99] :";A 60 INPUT "HEURE [0-23] :";H 70 INPUT "MINUTE [0-59] :";M 80 INPUT "SECONDE [0-59] :";S

100 REM TRANSFERT VERS RTC 105 POKE 49000,10:POKE 49001,32 110 POKE 49000,11:POKE 49001,143 120 POKE 49000,50:POKE 49001,20 130 POKE 49000,9:POKE 49001,A 140 POKE 49000,8:POKE 49001,MO 150 POKE 49000,7:POKE 49001,D 160 POKE 49000,6:POKE 49001,J 170 POKE 49000,4:POKE 49001,H 180 POKE 49000,2:POKE 49001,M 190 POKE 49000,0:POKE 49001,S 200 POKE 49000,11 : POKE 49001,15 210 PRINT "MISE A JOUR TERMINEE" 220 PRINT
230 END

Une fois l’horloge réglée, l’ordinateur peut être débranché tout comme l’interface et lors de la prochaine utilisation, il suffira de lire l’heure. Il est inutile de la régler à nouveau.

### Lecture de l’horloge

Ce programme BASIC permet de lire l’heure et la date à partir de l’horloge RTC.

### 10 PRINT "LECTURE DE L’HEURE" 20 POKE 49000,9: A=PEEK(49001) 30 POKE 49000,8: MO=PEEK(49001) 40 POKE 49000,7: D=PEEK(49001) 60 POKE 49000,4: H=PEEK(49001) 70 POKE 49000,2: M=PEEK(49001) 80 POKE 49000,0: S=PEEK(49001)

100 PRINT "NOUS SOMMES LE ";D;"/";MO;"/20";A 110 PRINT "IL EST ";H;":";M;":";S

Remarque : Les composants DS12C887+ disponibles sur Aliexpress ou ebay sont souvent de mauvaise qualité avec notamment un quartz peu précis. Il est alors normal que l’horloge dérive de manière parfois importante. Il est possible de remplacer ce quartz mais c’est une manœuvre très délicate. Il est donc plus sage de s’approvisionner auprès d’un vendeur connu proche de chez nous.

### Schéma du matériel


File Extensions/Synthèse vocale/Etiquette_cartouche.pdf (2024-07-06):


PAROLE | PAROLE

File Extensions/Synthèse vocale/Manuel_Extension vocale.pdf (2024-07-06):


Fred_72 | Version du 06/07/2024

# Extension vocale pour Alice

L’extension synthèse vocale permet d’étendre les possibilités de votre ordinateur ALICE en lui donnant la parole. Le pack se compose d’un boîtier extension contenant le célèbre synthétiseur à formants MEA8000 de Philips et d’une cartouche PAROLE contenant le logiciel nécessaire à son fonctionnement.
Il suffit de brancher l’extension derrière l’extension multi-ports et placer la cartouche dans le port supérieur de l’extension. La cartouche PAROLE contient un programme de démonstration et un vaste dictionnaire de plus de 200 mots mots pré-enregistrés.

La sortie son est disponible sur un connecteur jack 3.5mm. De fait, il faut utiliser une petite enceinte amplifiée pour profiter de cette extension.


Attention : Pour éviter tout dommage à votre ordinateur ALICE, il faut impérativement débrancher l’alimentation avant de brancher l’extension.

### Programmes de la cartouche

L’extension synthèse vocale est accompagnée d’une cartouche contenant un programme de démonstration et un vocabulaire d’environ 260 mots.
La cartouche d’une taille de 64Ko est découpée en 8 pages de 8Ko implantées aux adresses 4096 à 8191 [$1000 à $1FFF]. Les pages mémoires sont réparties ainsi :


La sélection d’une page se fait par un POKE 4096,n (n= 0 à 7 : numéro de la page mémoire). La page 0 contient un programme de démonstration tandis que les pages 1 à 7 contiennent le vocabulaire additionnel.

### Programme de démonstration

Juste après l’allumage de votre ordinateur vous pouvez lancer le programme de démonstration en tapant : EXEC 4096 puis ENTER
Si le vocabulaire a été utilisé au préalable, il faut d’abord faire un POKE 4096,0 pour revenir à la page 0 avant de lancer le programme de démonstration.

### Vocabulaire

Le vocabulaire est enregistré dans 7 banques de la cartouche. Le programme vocal est dupliqué dans toutes les banques afin de simplifier son utilisation.
Ainsi, pour pouvoir utiliser le vocabulaire il faut d’abord sélectionner la banque mémoire avec une instruction POKE 4096,n (avec n entre 1 et 7). Puis choisir le mot avec un POKE 255,m (avec m défini dans le tableau) et enfin appeler la routine avec l’instruction EXEC 4096.

Le Tableau 1 donne le vocabulaire de la banque N°1 avec le code associé.

N° | Texte | N° | Texte | N° | Texte
0 | A | 1 | ACCOLADE | 2 | AIMER
3 | ALLER | 4 | ALORS | 5 | AMI
6 | ANIMAL | 7 | ANIMAUX | 8 | ANNÉE
9 | ANNIVERSAIRE | 10 | ANTI | 11 | APPRENDRE
12 | APPUI | 13 | APRÈS | 14 | ARRÊT
15 | ASSEZ | 16 | ASSIETTE | 17 | ASTÉRISQUE
18 | AU | 19 | AUSSI | 20 | AVANT
21 | AVOIR | 22 | B | 23 | BARRE
24 | BAS | 25 | BIEN | 26 | BLOCAGE
27 | BOIRE | 28 | BON | 29 | BONJOUR
30 | BONNE | 31 | BRAVO | 32 | C’EST
33 | C’ÉTAIT | 34 | C | 35 | CALCUL
36 | CE | 37 | CECI | 38 | CHIFFRE
39 | CHOISI | 40 | CHOIX | 41 | CLASSE
42 | CLAVIER | 43 | CLÉ | 44 | COMBIEN
45 | COMME | 46 | COMMERCIAL | 47 | VOIR
48 | VOS | 49 | VOTRE | 50 | VOUS
51 | VRAIMENT | 52 | W | 53 | X
54 | Y | 55 | Z

Tableau 1: Vocabulaire de la banque 1
Exemple :
Pour prononcer « BONJOUR », il faut utiliser le programme suivant : 10 POKE 4096,1
15 POKE 255,29 : EXEC 4096

Le Tableau 2 donne le vocabulaire de la banque N°2 avec le code associé.

N° | Texte | N° | Texte | N° | Texte
0 | COMPRENDRE | 1 | COMPTER | 2 | CONNAÎTRE
3 | COPIE | 4 | CORRESPONDANTE | 5 | COTÉE
6 | COULEUR | 7 | CRAYON | 8 | CROCHET
9 | CURSEUR | 10 | D’ | 11 | D
12 | DANS | 13 | DE | 14 | DÉBUT
15 | DÉJÀ | 16 | DELETE | 17 | DEMANDER
18 | DEMI | 19 | DES | 20 | DÉSIRER
21 | DIÈSE | 22 | DIFFICILE | 23 | DIRE
24 | DIRIGE | 25 | DO | 26 | DOLLAR
27 | DONC | 28 | DONNE | 29 | DROITE
30 | DU | 31 | E | 32 | ÉCOUTE
33 | ÉCOUTEUR | 34 | ÉCRAN | 35 | ÉCRIS
36 | EFFACE | 37 | ÉGAL | 38 | ELLE
39 | EN | 40 | ENCORE | 41 | ENFANT
42 | ENTER | 43 | ESCAPE | 44 | ESPACE
45 | ESSAYE | 46 | EST | 47 | EST-CE
48 | ET | 49 | ÊTRE | 50 | EU
51 | EXACTE

Tableau 2: Vocabulaire de la banque 2
Exemple :
Pour prononcer « ÉCOUTEUR », il faut utiliser le programme suivant : 10 POKE 4096,2
15 POKE 255,33 : EXEC 4096

Le Tableau 3 donne le vocabulaire de la banque N°3 avec le code associé.

N° | Texte | N° | Texte | N° | Texte
0 | EXCLAMATION | 1 | EXEMPLE | 2 | EXERCICE
3 | F | 4 | FA | 5 | FACILE
6 | FAIRE | 7 | FAIS | 8 | FEMME
9 | FLÈCHE | 10 | FOIS | 11 | FONCTION
12 | FRANC | 13 | G | 14 | GAUCHE
15 | GRAND | 16 | GUILLEMET | 17 | H
18 | HA NON | 19 | I | 20 | IL
21 | INEXACTE | 22 | INFÉRIEUR | 23 | J
24 | INTERROGATION | 25 | JAMAIS | 26 | JE
27 | JOUR | 28 | JOYSTICK | 29 | JUSTE
30 | K | 31 | L’ | 32 | L’ÉCRAN
33 | L | 34 | LA-BAS | 35 | LA
36 | LE | 37 | LES | 38 | LEUR
39 | LIVRE | 40 | M | 41 | MA
42 | MADAME | 43 | MAIS | 44 | MAINTENANT
45 | MAISON | 46 | MAJUSCULE | 47 | MANETTE
48 | MATIN | 49 | ME | 50 | MERCI

Tableau 3: Vocabulaire de la banque 3
Exemple :
Pour prononcer « EXERCICE », il faut utiliser le programme suivant : 10 POKE 4096,3
15 POKE 255,2 : EXEC 4096

Le Tableau 4 donne le vocabulaire de la banque N°4 avec le code associé.

N° | Texte | N° | Texte | N° | Texte
0 | MES | 1 | MESDAMES | 2 | MESSIEURS
3 | MET | 4 | METTRE | 5 | MI
6 | MIDI | 7 | MIEN | 8 | MIEUX
9 | MOI | 10 | MOINS | 11 | MON
12 | MONSIEUR | 13 | MOYEN | 14 | MOT
15 | N | 16 | NE | 17 | NOMBRE
18 | NOM | 19 | NOS | 20 | NOTE
21 | NOTRE | 22 | NOUS | 23 | NUMÉRO
24 | O | 25 | ON | 26 | OPTIQUE
27 | OR | 28 | OU | 29 | OUI
30 | P | 31 | PARENTHÈSE | 32 | PARFAIT
33 | PARLER | 34 | PASSER | 35 | PENSER
36 | PETIT | 37 | PEUT-ÊTRE | 38 | PLUS
39 | POIGNÉE | 40 | POINT | 41 | POSITIONNE
42 | POUR | 43 | POUR-CENT | 44 | PREMIER
45 | PRENDRE | 46 | | 47 | PROBLÈME
48 | PUIS | 49 | PUISSANCE | 50 | Q
51 | QU’ | 52 | QU’EST-CE | 53 | QUAND
54 | QUE | 55 | QUEL | 56 | QUELQUE
57 | QUESTION

Tableau 4: Vocabulaire de la banque 4
Exemple :
Pour prononcer « EXERCICE », il faut utiliser le programme suivant : 10 POKE 4096,4
15 POKE 255,2 : EXEC 4096

Le Tableau 5 donne le vocabulaire de la banque N°5 avec le code associé.

N° | Texte | N° | Texte | N° | Texte
0 | QUI | 1 | QU’IL | 2 | QUOI
3 | R | 4 | RÉ | 5 | RECOMMENCE
6 | REGARDE | 7 | RÉPONSE | 8 | RÉSULTAT
9 | RIEN | 10 | S | 11 | SA
12 | SANS | 13 | SAVOIR | 14 | SCORE
15 | SE | 16 | SÉLECTIONNÉE | 17 | SES
18 | SI | 19 | SI (NOTE) | 20 | SIEN
21 | SIMPLE | 22 | SLASH | 23 | SOIR
24 | SOL | 25 | SOLUTION | 26 | SON
27 | SUITE | 28 | SUPÉRIEUR | 29 | SUR
30 | T | 31 | TA | 32 | TE
33 | TEMPS | 34 | TES | 35 | TIEN
36 | TIRET | 37 | TOI | 38 | TON
39 | TOUJOURS | 40 | TOUT | 41 | TRÈS
42 | TROUVER | 43 | TU | 44 | T-UN
45 | T-UNE | 46 | U | 47 | UN
48 | UNE | 49 | VENIR | 50 | VALIDATION
51 | V | 52 | VENT | 53 | VIRGULE
54 | VOICI | 55 | VOILA

Tableau 5: Vocabulaire de la banque 5
Exemple :
Pour prononcer « REGARDE », il faut utiliser le programme suivant : 10 POKE 4096,5
15 POKE 255,6: EXEC 4096

Le Tableau 6 donne le vocabulaire de la banque N°6 avec le code associé.

N° | Texte | N° | Texte | N° | Texte
0 | ZÉRO | 1 | UN | 2 | DEUX
3 | TROIS | 4 | QUATRE | 5 | CINQ
6 | CINQ (500) | 7 | SIX | 8 | SIX (600)
9 | SEPT | 10 | HUIT | 11 | HUIT (800)
12 | NEUF | 13 | DIX | 14 | DI(X)
15 | ONZE | 16 | DOUZE | 17 | TREIZE
18 | QUATORZE | 19 | QUINZE | 20 | SEIZE
21 | DIX-SEPT | 22 | DIX-HUIT | 23 | DIX-HUIT (18000)
24 | DIX-NEUF | 25 | VINGT | 26 | VING(T)
27 | TRENTE | 28 | QUARANTE | 29 | CINQUANTE
30 | SOIXANTE | 31 | QUATRE-VINGT | 32 | CENT
33 | MILLE | 34 | MILLION | 35 | ET UN
36 | ET

Tableau 6: Vocabulaire de la banque 6
Exemple :
Pour prononcer « TROIS », il faut utiliser le programme suivant : 10 POKE 4096,6
15 POKE 255,3: EXEC 4096

Le Tableau 7 donne le vocabulaire de la banque N°7 avec le code associé.

N° | Texte | N° | Texte | N° | Texte
0 | AUTO | 1 | AUTOBUS | 2 | AVION
3 | BAS | 4 | BATEAU | 5 | CAMPING CAR
6 | CAR | 7 | CARRE | 8 | CENTIME
9 | CERCLE | 10 | ÉLECTRICITÉ | 11 | FENÊTRE
12 | FRANC | 13 | GARE | 14 | HAUT
15 | HÉLICOPTÈRE | 16 | HEURE | 17 | KILO
18 | L’ | 19 | LA | 20 | LE
21 | LES | 22 | LUMIÈRE | 23 | MÈTRE
24 | MÉTRO | 25 | MINUTE | 26 | MUR
27 | PIÈCE | 28 | PLANCHER | 29 | PORTE
30 | RECTANGLE | 31 | TABLE | 32 | TAXI
33 | TÉLÉPHONE | 34 | TÉLÉVISION | 35 | TONNE
36 | TRAIN | 37 | TRIANGLE | 38 | UN
39 | UNE | 40 | UNE... | 41 | VÊTEMENT
42 | VOITURE

Tableau 7: Vocabulaire de la banque 7
Exemple :
Pour prononcer « ÉLECTRICITÉ », il faut utiliser le programme suivant : 10 POKE 4096,7
15 POKE 255,10: EXEC 4096

### Vocabulaire composé

Il est bien sûr possible de mélanger les mots des différentes banques en sélectionnant les banques au fur et à mesure.
Exemple 1 :
Pour dire « BONJOUR MESSIEURS », il faut utiliser le programme suivant :
10 POKE 4096,1 : POKE 255,29: EXEC 4096
15 POKE 4096,4 : POKE 255,2: EXEC 4096

Exemple 2 :
Pour donner l’heure « IL EST TROIS HEURES ET VINGT MINUTES », il est possible d’utiliser le programme suivant :
10 FOR I=1 TO 7
20 READ B,M
30 POKE 4096,B : POKE 255,M 40 EXEC 4096
50 NEXT I
100 DATA 3,20,2,46,6,3,7,16,2,48,6,25,7,25

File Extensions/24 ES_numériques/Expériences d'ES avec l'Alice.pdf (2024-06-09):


Fred_72 - 6502man | Version du 09/06/2024

## Sommaire

### Introduction

Ce document propose de vous initier à l’utilisation des entrées-sorties numériques avec votre ordinateur Alice 32 ou 90.
Vous serez guidé au fil des exemples d’application tout d’abord en BASIC puis progressivement en ASSEMBLEUR en commençant par des programmes simples puis de plus en plus compliqués vous permettant d’envisager des applications domotiques pilotées par votre ordinateur Alice.
Ce document utilise l’extension 24 Entrées/Sorties pour Alice présentée sur le forum system-cfg. Cette extension ajoute 24 E/S numériques [0V ou 5V] réparties sur 3 ports de 8 bits.

### Brochage du connecteur E/S

La Figure 1 rappelle le brochage du connecteur IDC30 de cette extension.


### Programmation

La programmation se fait à l’aide des commandes POKE et PEEK du BASIC ou bien en langage machine avec les instructions LDAA et STAA. Le circuit 8255 dispose de 4 registres accessibles aux adresses suivantes :

Adresse (décimal) | Adresse (Hexadécimal) | Registre
48992 | BF60 | PORT A
48993 | BF61 | PORT B
48994 | BF62 | PORT C
48995 | BF63 | CONTROL

Tableau 1: Adresses des registres du circuit 8255

Figure 1: Brochage du connecteur d'E/S

### Registre de contrôle

Le registre de contrôle permet de définir le sens de fonctionnement des ports (entrée ou sortie). Il doit être défini au début du programme avant toute action sur les registres des ports.

Le port C est coupé en deux blocs de 4 bits, le sens de fonctionnement des 4 bits de poids faibles et des bits de poids forts peut être défini indépendamment. Les autres ports peuvent seulement être tout en entrée ou tout en sortie.

Le Tableau 2 donne les valeurs du registre de configuration selon la direction des différents ports.

PORT A | PORT B | PORT C [7..4] | PORT C [3..0] | CONFIG (Hexa) | CONFIG (Décimal)
E | E | E | E | 9B | 155
E | E | E | S | 9A | 154
E | E | S | E | 93 | 147
E | E | S | S | 92 | 149
E | S | E | E | 99 | 153
E | S | E | S | 98 | 152
E | S | S | E | 91 | 148
E | S | S | S | 90 | 147
S | E | E | E | 8B | 139
S | E | E | S | 8A | 138
S | E | S | E | 83 | 131
S | E | S | S | 82 | 130
S | S | E | E | 89 | 137
S | S | E | S | 88 | 136
S | S | S | E | 81 | 129
S | S | S | S | 80 | 128

Tableau 2: Les différentes configurations possibles

Figure 2: Registre de contrôle

### Contrôle des ports

Le contrôle des ports d’entrées-sorties se fait à l’aide du code binaire traduisant les états 0 ou 1 de chaque bit de l’octet.

Chaque case (8 pour former un octet) correspond à un bit et le numéro placé au dessus indique sa position dans l’octet, c’est à dire sa pondération (2n
). Ainsi PA0 correspond au bit 0 du PORTA et PA7 au bit 7. Pour former une valeur numérique décimale plus compréhensible, il suffit d’ajouter toutes les valeurs des bits à 1 associées à leur pondération.

Valeur= PA0. 2 +PA1. 2 ⁰
1

+PA2. 2²

+PA3. 2³

+PA4. 2⁴

+PA5. 2⁵

+PA6 2⁶

+PA7. 2⁷
, soit en valeur
numérique : Valeur= PA0. 1 +PA1. 2 +PA2. 4 +PA3. 8 +PA4. 16 +PA5. 32 +PA6 64 +PA7. 128 Ce qui donne une plage de variation de 0 (tous les bits à 0) à 255 (tous les bits à 1).

Ainsi la valeur représentée sur la Figure 3 est : 1.1+1.2+1.16+1.64= 83 en décimal.

Pour écrire sur un port, il suffit de calculer la valeur décimale à partir de l’image binaire que l’on souhaite envoyer puis d’utiliser l’instruction POKE avec l’adresse du PORT cible.
Par exemple POKE 48992,85 envoie la valeur 85 sur le port (en binaire 01010101) . Cette valeur provoque la mise à 1 des bits impairs et à 0 les bits pairs du PORTA

Figure 3: Octet en binaire

### Exercice 1 (Led)

But : Faire clignoter deux leds
Les 2 leds sont connectées sur les broches PA0 et PA1 du PORTA selon les branchements de la Figure 4 (la patte la plus longue de la led est le +). Une résistance de limitation de 220 ohms est câblée en série avec chaque led. Elle est indispensable pour ne pas endommager les leds.


Ce Programme BASIC permet de faire clignoter les 2 leds simultanément.

### 5 CLS 10 PRINT "COMMANDE DES LEDS DU PORT A" 30 POKE 48995,139 40 POKE 48992,3 50 GOSUB 100 60 POKE 48992,0 70 GOSUB 100 80 GOTO 40

100 REM TEMPORISATION
110 FOR I=1 TO 400
120 NEXT I
130 RETURN

L’instruction POKE 48995,139 de la ligne 30 place le PORTA en sortie. Les PORTB et PORTC sont laissés en entrée. La valeur 139 est obtenue à l’aide du Tableau 2.

Figure 4: Leds clignotantes

L’instruction POKE 48992,3 de la ligne 40 met les bits PA0 et PA1 à 1, les autres (PA2 à PA7) sont à 0. Cela allume les 2 leds.
L’instruction POKE 48992,0 de la ligne 60 met tous les bits du PORTA à 0. Cela éteint les 2 leds.

La temporisation appelée par les lignes 50 et 70 permet de ralentir le rythme du clignotement.

### Modification

Le programme précédent fait clignoter les leds simultanément. En modifiant les valeurs écrites sur le PORTA (lignes 40 et 60), il est possible de faire clignoter les leds alternativement.

Les nouvelles lignes sont :

### 40 POKE 48992,1 60 POKE 48992,2

Cela correspond aux nouvelles valeurs binaires suivantes :

Question

Comment faut-il modifier le programme pour accélérer ou ralentir le rythme du clignotement ?

Figure 5: Allumage/Extinction des leds

Figure 6: Clignotement alterné des LEDs

### Exercice 2 (Led)

But : Commander l’allumage des leds avec un bouton poussoir
Comme l’exercice précédent, les 2 leds sont connectées sur les broches PA0 et PA1 du PORTA selon les branchements de la Figure 7. Elles sont accompagnées d’un bouton poussoir et d’une résistance de 4.7 kilo-ohms connectés sur la broche PB0.


La résistance de 4.7 kilo-ohms permet de maintenir un état ‘0’ lorsque le bouton poussoir est relâché. Sans cette résistance, la tension sur la broche PB0 est flottante ce qui se traduit par une lecture aléatoire de 1 et de 0 sur cette entrée.
Ce programme BASIC permet d’allumer la led rouge lorsque le bouton poussoir est appuyé et la led verte lorsqu’il est relâché.

### 5 CLS 10 PRINT "COMMANDE PAR BP DES LEDS DU PORT A" 30 POKE 48995,139 40 IF (PEEK(48993) AND 1)<>0 THEN GOTO 70 50 POKE 48992,2 60 GOTO 40 70 POKE 48992,1 80 GOTO 40

L’écriture des valeurs vers le PORTA se fait de la même façon que précédemment avec les valeurs 1 et 2 permettant d’allumer la seule led rouge ou la seule led verte.
La lecture fait appel à l’instruction PEEK 48993 qui permet de lire l’état des 8 bits du PORTB. Cependant, le bouton poussoir n’est raccordé qu’à la broche PB0, il convient donc de filtrer la valeur lue pour n’avoir que l’information relative à l’état logique du bouton poussoir (bit 0).

Figure 7: Commande par BP

Pour cela le programme utilise l’opérateur AND (ET logique). Cet opérateur binaire agit de la façon suivante (A et B sont les valeurs d’entrées, S est la sortie) :

A | B | S
0 | 0 | 0
0 | 1 | 0
1 | 0 | 0
1 | 1 | 1

Tableau 3: Opérateur AND
Pour obtenir un 1 logique, il faut que les 2 entrées A et B soient à 1.
Dans le programme, la même opération est effectuée pour chaque bit de l’octet. Cela conduit à :


Sur cette figure, les bits 5 et 6 sont à 1, ce qui correspond à des états indésirables ou bien issus d’autres boutons poussoirs. Le masque associé à l’opérateur AND vaut 1 ce qui permet de ne sélectionner que le bit PB0 du PORTB. Il en ressort une valeur numérique qui vaut soit 0 (BP appuyé) soit 1 (BP relâché).
Le programme fait cette opération puis oriente le programme vers la ligne 50 ou 70 en fonction de l’état logique du bouton poussoir.

Figure 8: Filtrage avec un AND

S=A AND B

### Modification 1

On ajoute un 2ème bouton poussoir connecté à PB1.


Ce nouveau programme BASIC permet d’allumer la led rouge lorsque le bouton poussoir BP1 est appuyé et la led verte lorsque le bouton poussoir BP2 est appuyé. Enfin, les 2 leds sont allumées si les 2 boutons poussoirs sont appuyés simultanément.

### 5 CLS 10 PRINT "COMMANDE PAR 2 BOUTONS DES LEDS DU PORT A" 30 POKE 48995,139 40 A=1 50 IF (PEEK(48993) AND 1)<>0 THEN A=0 60 B=2 70 IF (PEEK(48993) AND 2)<>0 THEN B=0 80 POKE 48992, A OR B 90 GOTO 40

La lecture fait toujours appel à l’instruction PEEK associée à l’opérateur AND, mais cette fois les valeurs 1 et 2 sont utilisées.


Pour BP2, le résultat de l’opération vaut 0 ou 2. C’est la raison pour laquelle, le programme utilise le test <> 0 plutôt qu’un test d’égalité.

Figure 9: Commande par 2 BPs

Figure 10: Filtrage du 2ème bouton poussoir

Le programme utilise 2 variables A et B pour avoir 2 valeurs de commande du PORTA. La modification du port se fait par une écriture unique qui va combiner les 2 variables pour former une seule valeur finale à l’aide de l’opérateur OR (OU logique).

Cet opérateur binaire agit de la façon suivante (A et B sont les valeurs d’entrées, S est la sortie) :

A | B | S
0 | 0 | 0
0 | 1 | 1
1 | 0 | 1
1 | 1 | 1

Tableau 4: Opérateur OR
Pour obtenir un 1 logique, il suffit qu’une des 2 entrées (A ou B) soit à 1.
Dans le programme, cette opération est utilisée avec les variables A et B. Cela conduit à :

Remarque : Il est possible d’utiliser l’opérateur addition (+) pour arriver au même résultat dans le cas de variables distinctes (c’est à dire qui n’utilise pas les mêmes bits). C’est le cas ici car A utilise le bit 0 tandis que B utilise le bit 1 (c’est pour cela que dans le programme il est écrit B=2).

Question
Comment faut-il modifier le programme si BP2 est connecté sur la broche PB4 ?

S=A OR B

Figure 11: Association des variables A et B du programme

### Modification 2

On retire les boutons poussoirs et on met à la place une photorésistance (LDR) associée à une résistance de 15 kilo-ohms. La photorésistance est un composant dont la résistance varie selon la lumière. Si le composant est exposé à une lumière vive, sa résistance est faible. Si le composant est maintenue dans l’obscurité, sa résistance est grande.

Question


Le but est ici de créer un interrupteur crépusculaire. Le jour (lorsque le capteur est éclairé), la led est éteinte et la nuit (lorsque le capteur est dans l’obscurité), la led est allumée. Comment faut-il modifier le programme pour obtenir le fonctionnement désiré ?

Figure 12: Photorésistance et Led

### Modification 3

On ajoute à présent un détecteur de mouvement (PIR) sur l’entrée PB0.

Question

Le but est maintenant de créer un interrupteur crépusculaire à détection de mouvement. Le jour (lorsque le capteur est éclairé), la led est éteinte et la nuit (lorsque le capteur est dans l’obscurité) et qu’un mouvement est détecté, la led s’allume pendant 10s. Comment faut-il modifier le programme pour obtenir le fonctionnement désiré ?

Figure 13: Interrupteur crépusculaire 2

### Exercice 3 (7 segments)

But : Commander un afficheur 7 segments
Cet exercice fait appel à un afficheur 7 segments pour afficher les chiffres de 0 à 9. Dans cet exercice, l’afficheur utilisé est un HS-5161A à cathodes communes. Il est bien sûr possible d’utiliser n’importe quel afficheur à cathodes communes mais il faudra adapter le câblage selon son brochage.
Le terme cathodes communes signifie que la cathode (le -) des leds constituant les 7 segments de l’afficheur sont raccordées ensemble à l’intérieur de l’afficheur. Cela permet de réduire le nombre de broches nécessaires à seulement 9 pour 7 segments + le point décimal.
Pour allumer un segment, il faut mettre à 1 (+5V) la broche concernée. Comme pour les exercices précédents, le courant dans les leds doit être limité par une résistance de 470 ohms en série avec chaque led.


Figure 14: Commande d'un afficheur 7 segments

### Codage des chiffres

L’afficheur est constitué de 7 segments (le point décimal n’est pas utilisé ici) placés judicieusement pour former un chiffre. Les segments sont nommés ‘A’ à ‘G’ selon la disposition de la figure. L’envoi d’une valeur numérique de 0 à 9 sur le PORTA ne suffit pas à afficher un chiffre. Il faut utiliser un codeur 7 segments qui peut prendre la forme d’un composant (CD4511 par exemple) ou un morceau de programme qui convertit la valeur numérique en une série de ‘1’ et de ‘0’ conduisant à l’affichage des segments pour former le chiffre souhaité.
C’est cette 2ème solution qui est utilisée ici. Le Tableau 5 donne le codage des chiffres de 0 à 9.


Chiffre | G | F | E | D | C | B | A | Valeur décimale
0 | 0 | 1 | 1 | 1 | 1 | 1 | 1 | 63
1 | 0 | 0 | 0 | 0 | 1 | 1 | 0 | 6
2 | 1 | 0 | 1 | 1 | 0 | 1 | 1 | 91
3 | 1 | 0 | 0 | 1 | 1 | 1 | 1 | 79
4 | 1 | 1 | 0 | 0 | 1 | 1 | 0 | 102
5 | 1 | 1 | 0 | 1 | 1 | 0 | 1 | 109
6 | 1 | 1 | 1 | 1 | 1 | 0 | 1 | 125
7 | 0 | 0 | 0 | 0 | 1 | 1 | 1 | 7
8 | 1 | 1 | 1 | 1 | 1 | 1 | 1 | 127
9 | 1 | 1 | 0 | 1 | 1 | 1 | 1 | 111

Tableau 5: Codage des chiffres sur un afficheur 7 segments

Ce Programme BASIC permet de compter de 0 à 9 sur l’afficheur.

### 5 CLS 10 PRINT "COMPTAGE SUR UN AFFICHEUR" 20 DIM A(10) 30 FOR V=0 TO 9 40 READ A(V) 50 NEXT V 55 DATA 63,6,91,79,102,109,125,7,127,111

### 60 POKE 48995,139 70 FOR N=0 TO 9

### 80 POKE 48992, A(N) 90 GOSUB 200

100 NEXT N
110 GOTO 70

200 REM TEMPORISATION
210 FOR I=1 TO 200
220 NEXT I
230 RETURN

La 1ère partie du programme permet de remplir les cases du tableau A avec les 10 valeurs permettant de visualiser des chiffres compréhensibles sur l’afficheur 7 segments.
La ligne 60 permet de mettre le PORTA en sortie. Les PORTB et PORTC sont laissés en entrée. Les lignes 70 et 100 mettent en place une boucle de comptage FOR-NEXT durant laquelle N parcourt les valeurs 0 à 9.
Enfin la ligne 80 envoie sur le PORTA la valeur correspondant au chiffre N en utilisant le tableau pour transformer cette valeur numérique en code ‘7 segments’.

### Modification 1

Un 2ème afficheur 7 segments est ajouté. Il est branché sur le PORTB. Cela va permettre maintenant de compter de 0 à 99.


Figure 15: Commande de 2 afficheurs 7 segments

Le programme BASIC est modifié ainsi :

### 60 POKE 48995,137 70 FOR N=0 TO 99 75 D=INT(N/10) 80 U=N-10*D 85 POKE 48992, A(U) 90 POKE 48993, A(D)

100 GOSUB 200
110 NEXT N
120 GOTO 70

La ligne 60 est modifiée afin de mettre les PORTA et PORTB en sortie, le PORTC inutilisé reste en entrée.
A partir de la ligne 75, la variable D contient le chiffre des dizaines tandis que la variable U contient le chiffre des unités. Ces 2 valeurs sont envoyées, après codage 7 segments, sur les ports A et B.

### Modification 2

On ajoute un bouton poussoir et une résistance de 4.7 kilo-ohms connectés sur PC0.


On souhaite pouvoir changer le sens de comptage en appuyant sur le bouton poussoir. Lorsque le bouton poussoir est relâché, le programme fonctionne comme précédemment (comptage) mais lorsque le bouton poussoir est appuyé, les afficheurs décomptent.

### Question

Comment faut-il modifier le programme pour changer le sens de comptage selon l’état du bouton poussoir ?

Figure 16: Commande de 2 afficheurs pilotés par un bouton poussoir

### Exercice 4 (7 segments-ASM)

But : Commander 2 afficheurs 7 segments
Le but de cet exercice entièrement en assembleur est d’afficher sur un des 2 afficheurs, le caractère frappé au clavier. Le choix de l’afficheur se fait en appuyant au clavier la combinaison SHIFT+1 ou SHIFT+2.


La 1ère opération consiste à définir les codes des différents caractères sur un afficheur 7 segments. Pour cet exercice, les codes seront traduits en hexadécimal plus approprié pour un codage en assembleur. Tous les caractères alphanumériques ne peuvent pas être visualisés sur un afficheur 7 segments. Pour les caractères qui ne sont pas dans le tableau, l’afficheur reste éteint (soit la valeur 0).

Figure 17: Commande de 2 afficheurs 7 segments

### Codage des caractères

Caractère | G | F | E | D | C | B | A | Valeur hexadécimale
0 | 0 | 1 | 1 | 1 | 1 | 1 | 1 | 3F
1 | 0 | 0 | 0 | 0 | 1 | 1 | 0 | 06
2 | 1 | 0 | 1 | 1 | 0 | 1 | 1 | 5B
3 | 1 | 0 | 0 | 1 | 1 | 1 | 1 | 4F
4 | 1 | 1 | 0 | 0 | 1 | 1 | 0 | 66
5 | 1 | 1 | 0 | 1 | 1 | 0 | 1 | 6D
6 | 1 | 1 | 1 | 1 | 1 | 0 | 1 | 7D
7 | 0 | 0 | 0 | 0 | 1 | 1 | 1 | 07
8 | 1 | 1 | 1 | 1 | 1 | 1 | 1 | 7F
9 | 1 | 1 | 0 | 1 | 1 | 1 | 1 | 6F
A | 1 | 1 | 1 | 0 | 1 | 1 | 1 | 77
B | 1 | 1 | 1 | 1 | 1 | 0 | 0 | 7C
C | 0 | 1 | 1 | 1 | 0 | 0 | 1 | 39
D | 1 | 0 | 1 | 1 | 1 | 1 | 0 | 5E
E | 1 | 1 | 1 | 1 | 0 | 0 | 1 | 79
F | 1 | 1 | 1 | 0 | 0 | 0 | 1 | 71
H | 1 | 1 | 1 | 0 | 1 | 1 | 0 | 76
I | 0 | 1 | 1 | 0 | 0 | 0 | 0 | 30
J | 0 | 0 | 0 | 1 | 1 | 1 | 0 | 0E
L | 0 | 1 | 1 | 1 | 0 | 0 | 0 | 38
N | 1 | 0 | 1 | 0 | 1 | 0 | 0 | 54
O | 1 | 0 | 1 | 1 | 1 | 0 | 0 | 5C
P | 1 | 1 | 1 | 0 | 0 | 1 | 1 | 73
S | 1 | 1 | 0 | 1 | 1 | 0 | 1 | 6D
T | 1 | 1 | 1 | 0 | 0 | 0 | 0 | 70
U | 0 | 0 | 1 | 1 | 1 | 0 | 0 | 1C
Y | 1 | 1 | 0 | 1 | 1 | 1 | 0 | 6E
° | 1 | 1 | 0 | 0 | 0 | 1 | 1 | 63

Tableau 6: Codes pour afficher les caractères sur un afficheur 7 segments

Le programme est à éditer en mémoire à partir de l’adresse $5000

.ORG $5000

JSR $FBD6 | ; efface l’écran
LDD #$0000
STD $3280 | ; LDD = x,y du curseur
LDX #Text7segs-1
JSR $E7A8 | ; Affiche du texte

LDAA #$89
STAA $BF63 | ; PORTA et PORTB en sortie, PORT C en entrée
LDAA #$3F | ; AFFICHE ‘0’ sur l’afficheur droit
STAA $BF60
LDAA #$06 | ; AFFICHE ‘1’ sur l’afficheur gauche
STAA $BF61

LDX #$BF20
STX WorkingArea

; attente touche
WaitKey
JSR $F883 | ; A = code ascii de la touche enfoncée
| ; Z = 0 aucun touche
BEQ WaitKey
CMPA #$21 | ; afficheur 1
BNE Continue2
LDX #$BF60
STX WorkingArea
JMP WaitKey
Continue2
CMPA #$22 | ; afficheur 2
BNE Continue3
LDX #$BF61
STX WorkingArea
JMP WaitKey
Continue3
PSHA
JSR $F9C6 | ; Affiche le caractère contenu dans A
PULB
LDX #CodageSegments
SUBB #$30
ABX
LDAA 0,X

LDX WorkingArea
STAA ,X
JMP WaitKey

Text7segs
.DB "CONTROLE D'AFFICHEURS 7 SEGMENTS" .DB 13
.DB "AVEC LA CARTE 24 ENTREES SORTIES" .DB 13,13
.DB "TAPEZ UN CHIFFRE OU UNE LETTRE :"
.DB 13
.DB "SHIFT ET 1 OU 2 POUR CHOISIR L'AFFICHEUR"

.DB 13
.DB 0

CodageSegments
.DB $3F,$06,$5B,$4F,$66,$6D,$7D,$07,$7F,$6F .DB $00,$00,$00,$00,$00,$00,$00,$77,$7C,$39 .DB $3E,$79,$71,$00,$76,$06,$1E,$00,$38,$00 .DB $00,$5C,$73,$00,$00,$5D,$70,$3E,$5E,$00 .DB $00,$00,$00,$63
WorkingArea
.DB 0,0

.END

La 1ère partie du programme permet d’afficher du texte sur l’écran puis place les chiffre 0 et 1 sur les afficheurs.
Le programme attend ensuite l’appui sur une touche. Si l’utilisateur appuie sur la combinaison "SHIFT+1" ou "SHIFT+2", cela change l’adresse stockée dans "Working Area" afin de changer la destination (PORTA ou PORTB). Si c’est une autre touche qui est appuyée, le caractère correspondant s’affiche sur le dernier afficheur sélectionné.
La table de codage est placée à la fin du programme, elle reprend les valeurs définies dans le Tableau 6. Elle est suivie par une zone de 2 octets permettant de stocker l’adresse du port en cours d’utilisation.

### Question

Comment faut-il modifier le système pour ajouter un 3ème afficheur sur le PORTC et le commander par la combinaison "SHIFT+3" ?

### Exercice 5 (7 segments + Clavier)


But : Lire un clavier à matrice
Cet exercice fait appel à un afficheur 7 segments et un clavier à 16 touches. Le but de l’exercice est de visualiser la touche appuyée sur l’afficheur 7 segments.

### Clavier

Le clavier est constitué de 16 touches réparties en 4 colonnes de 4 rangées (soit 4x4 touches). Cette façon de faire économise des fils mais nécessite une lecture active du clavier.

Figure 18: Clavier et afficheur 7 segments

Figure 19: Matrice du clavier 16 touches

Pour lire ce clavier, il faut disposer de 4 entrées et 4 sorties. Le principe consiste à alimenter une seule rangée à la fois puis à lire les 4 colonnes. La lecture du clavier nécessite donc 4 cycles. Il ne reste plus ensuite qu’à identifier la touche pressée.
Sur le schéma, il y a des résistances de tirage à ‘0’ et des diodes. Les résistance permettent de maintenir un état ‘0’ en l’absence d’action sur les touches du clavier (même principe que pour un bouton poussoir). Les diodes permettent de séparer les sorties. Si 2 touches sont appuyées simultanément, 2 sorties peuvent être en court-circuit (l’une est à ‘1’ et l’autre à ‘0’). Les diodes ne laissant passer le courant que dans un seul sens interdisent ce cas de figure. Elles ne sont pas nécessaires si l’utilisateur appuie sur une seule touche à la fois.
Sur le clavier, les caractères # et * sont remplacés par les lettres ‘E’ et ‘F’.

### Codage des lettres

Les chiffres ont déjà été codés lors de l’exercice 3 mais il reste les lettres ‘A’ à ‘F’. Le Tableau 7 donne les nouvelles valeurs associées à ces caractères.

Caractère | G | F | E | D | C | B | A | Valeur décimale
A | 1 | 1 | 1 | 0 | 1 | 1 | 1 | 119
B | 1 | 1 | 1 | 1 | 1 | 0 | 0 | 124
C | 0 | 1 | 1 | 1 | 0 | 0 | 1 | 57
D | 1 | 0 | 1 | 1 | 1 | 1 | 0 | 94
E | 1 | 1 | 1 | 1 | 0 | 0 | 1 | 121
F | 1 | 1 | 1 | 0 | 0 | 0 | 1 | 113

Tableau 7: Codage des caractères supplémentaires

Ce Programme BASIC permet de lire le clavier et d’afficher le caractère sur l’afficheur. Il est supposé que l’utilisateur n’appuie que sur une seule touche à la fois.

### 5 CLS 10 PRINT "LECTURE CLAVIER 16 TOUCHES" 20 DIM A(16),C1(5),C2(5),C3(5),C4(5) 30 FOR V=0 TO 15 40 READ A(V) 50 NEXT V 55 DATA 63,6,91,79,102,109,125,7,127,111,119,124,57,94,121,113 60 FOR V=1 TO 4 70 READ C1(V),C2(V),C3(V),C4(V) 80 NEXT V 85 DATA 1,4,7,14,2,5,8,0,3,6,9,15,10,11,12,13

100 POKE 48995,131
110 GOSUB 200
120 IF KB<>255 THEN POKE 48992,A(KB) 125 IF KB=255 THEN POKE 48992,0
130 GOTO 110

200 REM LECTURE CLAVIER
210 POKE 48994,16
220 R1=PEEK(48992) AND 15
230 POKE 48994,32
240 R2=PEEK(48992) AND 15
250 POKE 48994,64
260 R3=PEEK(48992) AND 15
270 POKE 48994,128
280 R4=PEEK(48992) AND 15
290 B=0
300 IF R1+R2+R3+R4=0 THEN KB=255:GOTO 350 310 IF R1>0 THEN B=R1:GOSUB 400: KB=C1(B) 320 IF R2>0 THEN B=R2:GOSUB 400: KB=C2(B) 330 IF R3>0 THEN B=R3:GOSUB 400: KB=C3(B) 340 IF R4>0 THEN B=R4:GOSUB 400: KB=C4(B) 350 RETURN

400 REM CONVERSION
410 IF B=4 THEN B=3
420 IF B=8 THEN B=4
430 RETURN

La 1ère partie du programme initialise le tableau A avec les codes ‘7 segments’ des caractères et les tableaux C1 à C4 avec les valeurs correspondant aux 4 colonnes du clavier.
Le sous-programme placé à partie de la ligne 200 permet de lire le clavier. Pour cela, chaque rangée est mise à ‘1’ à tour de rôle puis les 4 bits correspondants aux 4 rangées sont lus et stockés dans les variables R1 à R4. Les valeurs lues sont filtrées par un opérateur AND afin de ne garder que les 4 bits de poids faible.
Si aucune touche n’est appuyée, les variables R1 à R4 contiennent toutes la valeur 0.

Selon la touche appuyée, les valeurs dans les variables R1 à R4 peuvent prendre les valeurs 1, 2, 4 ou 8. Cette valeur est ensuite ramenée à 1, 2, 3 ou 4 par le petit sous-programme commençant à la ligne 400 afin d’aligner cette valeur sur les cases des tableaux C1 à C4.

### Question

Comment faut-il modifier le programme pour s’assurer que l’utilisateur n’appuie que sur une seule touche à la fois ?

### Exercice 6 (SR04)

But : Mesurer la distance avec un radar à ultrasons SR04
Cet exercice permet de mesurer la distance d’un objet à l’aide d’un module SR04.

Principe de la mesure

A la réception de l’impulsion de commande TRIG, le module émet une salve d’impulsions sonores (ultrasons à 40kHz). L’onde sonore va se réfléchir sur l’obstacle puis revenir vers le module. La mesure du temps entre l’émission et la réception permet de déduire la distance séparant le module de l’obstacle. Le module ne retourne pas directement la distance mais donne une impulsion dont la durée correspond au temps de vol (c’est à dire le temps nécessaire pour faire l’aller-retour).

Figure 20: Mesure de distance


Figure 21: SR04 - Principe de la mesure

La mesure commence lorsque le module SR04 reçoit une impulsion de 10µs. La commande et la mesure nécessitent des temps très brefs, aussi cette partie sera assurée par un programme en assembleur. Le programme est donc constitué d’une partie en BASIC et d’une partie en assembleur.

5 CLS 10 FOR A=0 TO 91 20 READ V 30 POKE 17670+A,V 40 NEXT A 50 DATA 206,0,0,255,69,0,255,69,2,255,69,4,134,1,183,191 60 DATA 96,134,1,134,1,134,0,134,0,183,191,96,182,191 70 DATA 98,132,1,39,249,12,182,69,5,137,1,183,69,5,182,69,4 75 DATA 137,0,183,69,4,182,69,3,137,0,183,69,3,182,69,2,137 80 DATA 0,183,69,2,182,69,1,137,0,183,69,1,182,69,0,137,0,183 85 DATA 69,0,182,191,98,132,1,38,200,57

100 PRINT "CONTROLE D'UN SONAR SR04"
110 PRINT "AVEC LA CARTE 24 ENTREES SORTIES"
115 PRINT
120 PRINT "PLACEZ VOTRE MAIN AU DESSUS DU RADAR" 130 POKE 48995,139
140 EXEC 17670
150 D=PEEK(17668)*256+PEEK(17669)
160 PRINT "DISTANCE : ",D
170 GOTO 140

Le code assembleur contenu dans les lignes DATA est le suivant :

.ORG $4500
WorkingArea
.DB 0,0,0,0,0,0

Start
LDX #$0000
STX WorkingArea
STX WorkingArea+2
STX WorkingArea+4

LDAA #$01
STAA $BF60 | ; envoie une impulsion sur le trigger

; il faut une durée minimal de 10µs LDAA #$01
LDAA #$01
LDAA #$00 | ; vérifié à l'oscillo | => env. 12us

LDAA #$00
STAA $BF60 | ; met à zéro le trigger
Attendhaut | ; attente du signal à l’état haut
LDAA $BF62 | ; lecture PORTC
ANDA #$01
BEQ Attendhaut

Distance | ; compte le temps
CLC
LDAA WorkingArea+5
ADCA #$01
STAA WorkingArea+5
LDAA WorkingArea+4
ADCA #$00
STAA WorkingArea+4
LDAA WorkingArea+3
ADCA #$00
STAA WorkingArea+3
LDAA WorkingArea+2
ADCA #$00
STAA WorkingArea+2
LDAA WorkingArea+1
ADCA #$00
STAA WorkingArea+1
LDAA WorkingArea+0
ADCA #$00
STAA WorkingArea+0
LDAA $BF62 | ; attente du signal à l'état bas
ANDA #$01
BNE Distance
RTS

.END

### Exercice 7 (SPEAKER)

But : Commander un haut parleur pour produire des sons
Cet exercice permet d’émettre un son dans un haut parleur à partir d’une sortie numérique. Il utilise un amplificateur audio afin d’amplifier le signal pour l’envoyer vers un petit haut-parleur. En effet, le signal issu de la carte d’entrées-sorties n’est pas assez puissant pour alimenter directement un haut-parleur.


La période du signal de sortie étant très faible (quelques millisecondes), le programme est entièrement écrit en assembleur.

Figure 22: Génération d'un son

Le programme est à éditer en mémoire à partir de l’adresse $5000

.ORG $5000

JSR $FBD6 | ; efface l’écran
LDD #$0000
STD $3280 | ; LDD = x,y du curseur
LDX #TextSPEAKER-1
JSR $E7A8

LDAA #$8B
STAA $BF63 | ; PORTA en sortie, PORTB et PORTC en entrée
LDAA #$00
STAA $BF60 | ; PORTA=0

; attente touche
WaitKey
JSR $F883 | ; A = code ascii de la touche enfoncée
| ; Z = 0 aucun touche
BEQ WaitKey

STAA WorkingArea+2
RORA
STAA WorkingArea+3
LDX #$10
STX WorkingArea

; TEMPO DIFFÉRENTE SELON LA TOUCHE
; A CONTIENT LE CODE ASCII DE LA TOUCHE (SERT A FAIRE VARIER LE SON)

BoucleSon
LDAB #$01 | ; émet un son sur le SPEAKER
STAB $BF60
JSR TEMPO
LDAB #$00 | ; coupe le son sur le SPEAKER
STAB $BF60
JSR TEMPOB

LDX WorkingArea
DEX
STX WorkingArea
BNE BoucleSon

JMP WaitKey

TEMPO
LDAA WorkingArea+2
TimingZ
LDX #$0010
Timing
DEX
BNE Timing
DECA
BNE TimingZ
RTS

TEMPOB
LDAA WorkingArea+3
TimingZB
LDX #$0010
TimingB
DEX
BNE TimingB
DECA
BNE TimingZB
RTS

TextSPEAKER
.DB "UTILISATION D'UN SPEAKER"
.DB 13
.DB "AVEC LA CARTE 24 ENTREES SORTIES"
.DB 13,13
.DB "APPUYEZ UNE TOUCHE POUR EMETTRE UN SON :" .DB 13
.DB "DIFFERENT SELON LA TOUCHE."
.DB 13,13
.DB 0

WorkingArea
.DB 00,00,00,00

.END

### Exercice 8 (SR04 + SPEAKER)

But : Réaliser un détecteur de proximité


En combinant les programmes des 2 exercices précédents, il est possible de réaliser un radar de proximité. La hauteur du son dans le haut-parleur va dépendre de la distance de l’obstacle.
Le programme est à éditer en mémoire à partir de l’adresse $5000
OUTTX.EQU $E7A8 | ; LDX = adresse chaîne (terminé par null)
OUTCA.EQU $F9C6 | ; LDAA = code ascii
SCANK.EQU $F883 | ; <= LDAA = code ascii de la touche
; enfoncée Z = 0 aucun touche
CLS | .EQU $FBD6 | ; efface l’écran
CURSOR | .EQU $3280 | ; LDD = y,x du curseur

.ORG $5000

LDAA #$89 | ; PORTA, PORTB en sortie, PORTC en entrée
STAA $BF63
LDAA #$00 | ; AUCUN SON DU BUZZER
STAA $BF61

JSR CLS
Start
LDD #$0000
STD CURSOR
LDX #TextRadar-1
JSR OUTTX

Figure 23: Détecteur de proximité

ReStart
LDX #$0000
STX WorkingArea
STX WorkingArea+2
STX WorkingArea+4

LDAA #$FF
STAA $BF60 | ; envoie une impulsion sur le trigger
LDAA #$FF | ; il faut une durée minimal de 10µs
LDAA #$FF | ; vérifie à l'oscillo | => env. 12us
LDAA #$00
LDAA #$00
STAA $BF60 | ; met à zéro le trigger
Attendhaut | ; attente du signal à l’état haut
LDAA $BF62
ANDA #$01
BEQ Attendhaut

Distance
CLC
LDAA WorkingArea+5
ADCA #$01
STAA WorkingArea+5
LDAA WorkingArea+4
ADCA #$00
STAA WorkingArea+4
LDAA WorkingArea+3
ADCA #$00
STAA WorkingArea+3
LDAA WorkingArea+2
ADCA #$00
STAA WorkingArea+2
LDAA WorkingArea+1
ADCA #$00
STAA WorkingArea+1
LDAA WorkingArea+0
ADCA #$00
STAA WorkingArea+0
LDAA $BF62 | ; attente du signal à l'état bas
ANDA #$01
BNE Distance

LDD #$0A00
STD CURSOR
LDX #TextDistance-1
JSR OUTTX

LDAA WorkingArea+3
JSR HPRINT
LDAA WorkingArea+4
JSR HPRINT
LDAA WorkingArea+5
JSR HPRINT

LDAB #$10
Son
LDAA #$FF | ; EMET UN SON BUZZER
STAA $BF61 | ; connecté au PORT B

LDAA WorkingArea+5

Tempo
DECA
BNE Tempo
LDAA #$00 | ; AUCUN SON DU BUZZER
STAA $BF61 | ; connecté au PORT B

LDAA WorkingArea+5
Tempo2
DECA
BNE Tempo2

DECB
BNE Son

FIN
JMP ReStart

HPRINT:
PSHA | ; print HEXA number
LSRA
LSRA
LSRA
LSRA
JSR Hex2Asc
JSR OUTCA
PULA
JSR Hex2Asc
JSR OUTCA
RTS

Hex2Asc:
ANDA #$0F | ; converti hexa en ascii
CMPA #$0A
BPL LetAsc
ADDA #$30
RTS
LetAsc
ADDA #$30+07
RTS

TextRadar
.DB "CONTROLE D'UN SONAR TYPE ARDUINO" .DB 13
.DB "AVEC LA CARTE 24 ENTREES SORTIES" .DB 13,13
.DB "POINTEZ LE SONAR VERS LE PLAFOND" .DB 13

.DB "PLACEZ VOTRE MAIN AU DESSUS" .DB 13
.DB "DU RADAR POUR FAIRE VARIER LE" .DB 13
.DB "SON EN FONCTION DE LA DISTANCE" .DB 13
.DB 0

TextDistance
.DB "DISTANCE EN CM (HEXA) :" .DB 0

WorkingArea
.DB 00,00,00,00,00,00

.END

### Exercice 9 (LCD)

But : Piloter un afficheur LCD
Cet exercice présente la méthode pour contrôler un afficheur LCD (2 lignes de 16 caractères) à partir de votre ordinateur Alice. L’afficheur est connecté au PORTA. Le PORTC permet de piloter les signaux de contrôle de l’afficheur. Une résistance de 100 ohms est placée en série avec l’alimentation du rétroéclairage (broches 15 et 16) et une résistance ajustable de 5 kilo-ohms assure le réglage du contraste.


### Réglage du contraste

A la mise sous tension, la ligne supérieure de l’afficheur doit être intégralement allumée tandis que la ligne inférieure doit être éteinte. Si rien n’est visible, il faut ajuster le contraste pour la faire apparaître en tournant la vis de réglage de la résistance variable. Après la séquence d’initialisation, la luminosité sera homogène sur tout l’afficheur.

Figure 24: Contrôle d'un afficheur LCD

Les signaux de contrôle permettant de piloter l’afficheur sont : RS, R/W et E
Dans cette application, R/W est maintenu à 0 (écriture uniquement).
RS (PC0) permet de sélectionner le registre d’instructions (RS=0) ou le transfert des données vers l’affichage (RS=1).
E (PC1) est le signal d’activation. Les données envoyées sont validées par une impulsion sur cette entrée.
Le programme sera composé d’une partie en BASIC et d’une partie en assembleur. Le code machine sera entré en mémoire par le programme BASIC. L’appel aux 2 routines assembleurs se fait à l’aide de l’instruction EXEC.

### 5 CLS 10 PRINT "CONTROLE D'UN AFFICHEUR LCD" 20 PRINT 30 POKE 48995,138 40 FOR I=0 TO 35 50 READ N 60 POKE 17664+I,N 65 NEXT I 70 DATA 134,00,183,191,96,134,0,183,191,98,138,2,183,191,98 75 DATA 134,0,183,191,98,206,1,44,9,38,253,57,134,0,183,191 80 DATA 96,134,1,32,227

100 GOSUB 300
110 A$="BONJOUR LE MONDE"
120 B$="MATRA ALICE"
125 REM AFFICHAGE LIGNE1
130 POKE 17665,1
135 EXEC 17664
140 T$=A$
150 GOSUB 200
155 REM AFFICHAGE LIGNE2
160 POKE 17665,192
165 EXEC 17664
170 T$=B$
180 GOSUB 200
190 END

200 REM ENVOI UNE CHAINE DE CARACTERES 205 FOR I=1 TO LEN (T$)
210 POKE 17692,ASC(MID$(T$,I,1))
220 EXEC 17691
230 NEXT I
240 RETURN

300 REM INIT AFFICHEUR
310 POKE 17665,56
320 EXEC 17664
330 POKE 17665,12
340 EXEC 17664
350 RETURN

Le code assembleur contenu dans les lignes DATA est le suivant :

.ORG $4500

Send_Com | ; Envoi d’une commande (@17664)
LDAA #0 | ; la valeur est modifiée par POKE 17665
STAA $BF60
LDAA #0

Continue
STAA $BF62
ORAA #2
STAA $BF62
LDAA #0
STAA $BF62

LDX #$012C
Tempo
DEX
BNE Tempo
RTS
Send_DATA | ; Envoi d’un caractère (@17691)
LDAA #0 | ; la valeur est modifiée par POKE 17692
STAA $BF60
LDAA #1
BRA Continue

.END

La 1ère partie du programme (lignes 5 à 80) place le code machine en mémoire et met les PORTA et PORTC en sortie. Le PORTB inutilisé reste en entrée.
Le sous-programme placé à partir de la ligne 200 assure l’envoi caractère par caractère de la chaîne de caractère T$ par le biais de la routine Send_DATA située à l’adresse mémoire 17691.
Le sous-programme placé à partir de la ligne 300 assure l’initialisation de l’afficheur en le plaçant en mode 8 bits, 2 lignes, affichage ON.
Les lignes 130-135 permettent d’effacer l’écran tandis que les lignes 160-165 placent le curseur sur la 2ème ligne.

### Exercice 10 (MOTEUR)

But : Piloter un moteur à courant continu
Cet exercice présente la méthode pour piloter un moteur à courant continu en faisant varier sa vitesse. Les sorties de la carte 24 E/S ne sont pas capables de commander directement un moteur. Il est donc nécessaire d’utiliser un transistor de puissance, ici un MOSFET IRF530 (ou équivalent). Le moteur est un petit moteur à courant continu de 3V à 24V. Il faudra bien entendu adapter la tension d’alimentation externe à la tension de fonctionnement du moteur. Enfin une diode et un condensateur assurent la protection du transistor et la réduction des parasites.


Le contrôle du moteur nécessite de piloter rapidement la sortie PA0. Le programme est donc écrit intégralement en assembleur. Le moteur est contrôlé à l’aide des touches fléchées du clavier et la barre d’espace.
Le programme doit être implanté en mémoire à partie de l’adresse $5000.
OUTTX | .EQU $E7A8 | ; LDX = adresse chaîne (terminée par null)
OUTCA | .EQU $F9C6 | ; LDAA = code ascii
SCANK | .EQU $F883 | ; <= LDAA = code ascii de la touche
| | ; enfoncée Z = 0 aucun touche
CURSOR | .EQU $3280 | ; LDD = y,x du curseur
MOTOR_OFF_PIN | .EQU $00
MOTOR_ON_PIN | .EQU $01
PORTA | .EQU $BF60

Figure 25: Contrôle d'un moteur à courant continu

.ORG $5000

LDAA #$8B | ; PORTA en sortie, PORTB et PORTC en entrée
STAA $BF63

LDAA #MOTOR_OFF_PIN
STAA PORTA

LDAA #$08
STAA TimOn
LDAA #$08
STAA TimOff
JSR $FBD6 | ; efface écran
Start
LDD #$0000
STD CURSOR
LDX #TextMotor-1
JSR OUTTX

MoteurMove
LDD #$0B09 | ; mouvement du moteur
STD CURSOR
LDAA Marche
CMPA #01
BEQ MarcheOn
LDX #TextOFF-1
JSR OUTTX
JMP FinCycle

MarcheOn
LDX #TextON-1
JSR OUTTX
LDAA #MOTOR_ON_PIN
STAA PORTA

LDD #$0709
STD CURSOR
LDAA TimOn
JSR HPRINT

LDD #$0717
STD CURSOR
LDAA TimOff
JSR HPRINT

LDAB TimOn
JSR Timing
LDAA #MOTOR_OFF_PIN
STAA PORTA
LDAB TimOff
FinCycle
JSR Timing
JMP MoteurMove

Timing
PSHB
JSR SCANK
BEQ PasDroite
CMPA #$20
BNE PASon
LDAA Marche
EORA #$01
STAA Marche
PASon
CMPA #$08
BNE PasGauche
DEC TimOn
PasGauche
CMPA #$09
BNE PasDroite
INC TimOn
PasDroite
CMPA #$0A
BNE Pasbas
DEC TimOff
Pasbas
CMPA #$0B
BNE PasHaut
INC TimOff
PasHaut
;LDAB Tim
PULB
Tempo
LDX #$00FF
Tmpz
DEX
BNE Tmpz
DECB
BNE Tempo
RTS

TextMotor
.DB "CONTROLE D'UN MOTEUR BASSE TENSION" .DB 13
.DB "AVEC LA CARTE 24 ENTREES SORTIES" .DB 13,13
.DB "UTILISEZ LES FLECHES POUR MODIFIER" .DB 13
.DB "LE CYCLE DU MOTEUR ON/OFF"
.DB 13
.DB "ESPACE= ARRETER OU DEMARRER LE MOTEUR" .DB 13,13
.Db "DUREE ON: DUREE OFF:"
.DB 0

TextON
.DB "MOTEUR ON "
.DB 0

TextOFF
.DB "MOTEUR OFF"
.DB 0

HPRINT:
PSHA | ; print HEXA number
LSRA
LSRA
LSRA
LSRA
JSR Hex2Asc
JSR OUTCA
PULA
JSR Hex2Asc
JSR OUTCA
RTS

Hex2Asc:
ANDA #$0F | ; converti hexa en ascii
CMPA #$0A
BPL LetAsc
ADDA #$30
RTS
LetAsc
ADDA #$30+07
RTS

WorkingArea
.DB 0,0,0,0,0,0

TimOn
.DB 00
TimOff
.DB 00

Marche
.DB 01

.END

### Exercice 11 (MOTEUR PAS A PAS)

But : Piloter un moteur pas à pas (28BYJ-48)
Cet exercice présente la méthode pour piloter un moteur pas à pas avec la carte 24 E/S . La commande du moteur nécessite un driver et une alimentation externe (chargeur USB par exemple). En général ces moteurs pour Arduino sont vendus avec une carte driver équipée d’un ULN2003 (inverseurs de puissance à collecteurs ouverts).

### Fonctionnement du moteur

Le moteur 28BYJ-48 est un moteur unipolaire, il comporte donc 5 fils de connexions (4 demi-bobines et un fil commun). Ce moteur est équipé d’un réducteur si bien que l’axe de sortie nécessite 4096 pas pour faire un tour. Sa commande consiste à commander les 4 demi-bobines en respectant une séquence bien précise.
Le gros avantage d’un moteur pas à pas par rapport à un moteur à courant continu c’est qu’il est très facile de faire varier sa vitesse tout en connaissant précisément sa position angulaire. De même, lorsque le moteur est arrêté, il peut maintenir sa position en exerçant un couple résistant important. Mais en contrepartie, un moteur pas à pas ne tourne pas aussi vite qu’un moteur à courant continu et avance par petits sauts ce qui se traduit par des vibrations transmises à la structure porteuse.
Il existe 2 modes de commande des moteurs pas à pas : la commande en pas entiers et la commande en demi-pas. C’est cette dernière qui est mise en œuvre ici. Elle permet notamment d’augmenter la précision angulaire en doublant le nombre de pas du moteur.

Figure 26: Moteur pas à pas et son driver


La carte de commande utilise un ULN2003, donc l’alimentation d’une bobine se fait en appliquant un ‘1’ à l’entrée concernée.
Le Tableau 8 donne la séquence de commande des bobines du moteur pour obtenir une rotation de son axe dans le sens antihoraire.

Rotation sens antihoraire (un ‘1’ alimente la bobine)
Commande | Bobine alimentée | Pas 1 | Pas 2 | Pas 3 | Pas 4 | Pas 5 | Pas 6 | Pas 7 | Pas 8
IN1 | B1- (orange) | 1 | 0 | 0 | 0 | 0 | 0 | 1 | 1
IN2 | B2+ (jaune) | 0 | 0 | 0 | 0 | 1 | 1 | 1 | 0
IN3 | B1+ (rose) | 0 | 0 | 1 | 1 | 1 | 0 | 0 | 0
IN4 | B2- (bleu) | 1 | 1 | 1 | 0 | 0 | 0 | 0 | 0
Valeur PORTA | | 9 | 1 | 3 | 2 | 6 | 4 | 12 | 8

Tableau 8: Commande du moteur en sens antihoraire
La dernière ligne du tableau donne les valeurs à écrire sur le PORTA pour commander la rotation du moteur.

Figure 27: Branchement du moteur pas à pas

De la même façon, le Tableau 9 donne la séquence de commande des bobines du moteur pour obtenir une rotation de son axe dans le sens horaire.

Rotation sens horaire (un ‘1’ alimente la bobine)
Commande | Bobine alimentée | Pas 1 | Pas 2 | Pas 3 | Pas 4 | Pas 5 | Pas 6 | Pas 7 | Pas 8
IN1 | B1- (orange) | 1 | 1 | 0 | 0 | 0 | 0 | 0 | 1
IN2 | B2+ (jaune) | 0 | 1 | 1 | 1 | 0 | 0 | 0 | 0
IN3 | B1+ (rose) | 0 | 0 | 0 | 1 | 1 | 1 | 0 | 0
IN4 | B2- (bleu) | 0 | 0 | 0 | 0 | 0 | 1 | 1 | 1
Valeur PORTA | | 8 | 12 | 4 | 6 | 2 | 3 | 1 | 9

Tableau 9: Commande du moteur en sens horaire
La dernière ligne du tableau donne les valeurs à écrire sur le PORTA pour commander la rotation du moteur.
Pour faire tourner le moteur, il suffit d’envoyer la succession des valeurs sur le PORTA. Cette commande peut se faire en BASIC ou en assembleur. L’envoi des valeurs ne doit pas se faire trop vite sinon le moteur n’aura pas le temps de réagir et perdra des pas. Cela se traduit par une rotation désordonnée du moteur. En BASIC ce n’est pas un problème car le langage est assez lent, mais en assembleur il faudra impérativement ajouter une boucle de temporisation pour éviter ce problème. Le moteur est contrôlé à l’aide des touches fléchées du clavier et la barre d’espace.
Le programme doit être implanté en mémoire à partie de l’adresse $5000.

PORTA .EQU $BF60
PORTB.EQU $BF61
PORTC.EQU $BF62
CTRL | .EQU $BF63
OUTTX.EQU $E7A8 | ; LDX = adresse chaine (terminé par null)
OUTCA.EQU $F9C6 | ; LDAA = code ascii
SCANK.EQU $F883 | ; <= LDAA = code ascii de la touche enfoncée Z = 0 aucun
touche
CLS | .EQU $FBD6 | ; efface l’écran
CURSOR | .EQU $3280 | ; LDD = y,x du curseur

.ORG $5000

LDAA #$80 | ; place les ports A, B et C en sorties
STAA CTRL
LDAA #$00 | ; met le moteur a l’arrêt
STAA PORTA
LDAA #00 | ; Sens initiale horaire =0
STAA Sens

JSR CLS
Start
LDD #$0000
STD CURSOR
LDX #TextStepper-1
JSR OUTTX

Move
JSR SCANK
CMPA #8
BNE PasGauche
LDAA Sens
EORA #01
STAA Sens
PasGauche
CMPA #9
BNE PasDroite
LDAA Sens
EORA #01
STAA Sens
PasDroite
LDAA Sens
CMPA #0
BNE NotHor
JSR Horaire
JMP Move
NotHor
JSR AntiHoraire
JMP Move

; faire tourner le moteur dans le sens antihoraire Horaire
LDX #Datas
LDAB #08
TourneH
LDAA 0,X
STAA PORTA
INX
PSHX
JSR Tempo
PULX
DECB
BNE TourneH
RTS

; faire tourner le moteur dans le sens horaire AntiHoraire
LDX #Datas+7
LDAB #08
TourneA
LDAA 0,X
STAA PORTA
DEX
PSHX
JSR Tempo
PULX
DECB
BNE TourneA
RTS
Tempo | ; ATTENTION ne pas reduire cette valeur
LDX #$008F | ; valeur critique !!!!
Timing | ; sous peine d'endommager votre moteur, ULN ....
DEX
BNE Timing
RTS

TextStepper
.DB "CONTROLE D'UN MOTEUR PAS A PAS" .DB 13
.DB "AVEC LA CARTE 24 ENTREES SORTIES" .DB 13,13
.DB "UTILISEZ LES TOUCHES GAUCHE ET" .DB 13
.DB "DROITE POUR CHANGER LE SENS DE" .DB 13
.DB "ROTATION DU MOTEUR."
.DB 0

Datas
.DB 8,12,4,5,2,3,1,9

Sens
.DB 00
Step
.DB 10

WorkingArea
.DB 00,00,00,00,00,00

.END

Ce 2ème programme permet de régler plus finement le mouvement du moteur en ajoutant la possibilité de régler ‘la vitesse’

PORTA .EQU $BF60
PORTB.EQU $BF61
PORTC.EQU $BF62
CTRL .EQU $BF63
OUTTX.EQU $E7A8 | ; LDX = adresse chaine (terminé par null)
OUTCA.EQU $F9C6 | ; LDAA = code ascii
SCANK.EQU $F883 | ; <= LDAA = code ascii de la touche enfoncée Z = 0 aucun
touche
CLS | .EQU $FBD6 | ; efface ecran
CURSOR | .EQU $3280 | ; LDD = y,x du curseur

.ORG $4FF9
.DB $01,$50,$00,$50,$00,$00,$00

.ORG $5000

LDAA #$80 | ; place les ports A, B et C en sorties
STAA CTRL
LDAA #$00 | ; met le moteur a l'arret
STAA PORTA
LDAA #00 | ; Sens initiale horaire =0
STAA Sens
LDAA #10 | ; pas initiale du moteur
STAA Step

JSR CLS
Start
LDD #$0000
STD CURSOR
LDX #TextStepper-1
JSR OUTTX

Move
LDD #$0806
STD CURSOR
LDAA Step
JSR HPRINT
LDAA #$00 | ; met le moteur a l'arret
STAA PORTA
WaitKey
JSR SCANK
BEQ WaitKey

PORT2 | .EQU $03
LDAB PORT2 | ; on lit l'état de shift
ANDB #$02
CMPB #$02
BEQ Keying
LDAB #$80
ABA
Keying
CMPA #8
BNE PasGauche
LDAA #$01
STAA Sens
PasGauche
CMPA #9
BNE PasDroite
LDAA #$00
STAA Sens
PasDroite
CMPA #$0B
BNE PasHaut
INC Step
JMP Move

PasHaut
CMPA #$0A
BNE PasBas
DEC Step
JMP Move
PasBas
CMPA #$8B
BNE PasShaut
LDAA Step
ADDA #$10
STAA Step
JMP Move
PasShaut
CMPA #$8A
BNE PasSbas
LDAA Step
SUBA #$10
STAA Step
JMP Move
PasSbas

LDAA Sens
CMPA #00
BNE NotHor
JSR Horaire
JMP Move
NotHor
JSR AntiHoraire
JMP Move

; faire tourner le moteur dans le sens antihoraire Horaire
LDAA Step

STAA WorkingArea
PasPasHoraire
LDX #Datas
LDAB #08
TourneH
LDAA 0,X
STAA PORTA
INX
PSHX
JSR Tempo
PULX
DECB
BNE TourneH
LDAA WorkingArea
DECA
STAA WorkingArea
BNE PasPasHoraire
RTS

; faire tourner le moteur dans le sens horaire AntiHoraire
LDAA Step
STAA WorkingArea
PasPasAntiHoraire
LDX #Datas+7
LDAB #08
TourneA
LDAA 0,X
STAA PORTA
DEX
PSHX
JSR Tempo
PULX
DECB
BNE TourneA
LDAA WorkingArea
DECA
STAA WorkingArea
BNE PasPasAntiHoraire
RTS
Tempo | ; ATTENTION ne pas reduire cette valeur
LDX #$008F | ; valeur critique !!!!
Timing
DEX
BNE Timing
RTS

TextStepper
.DB "CONTROL D'UN MOTEUR PAS A PAS" .DB 13
.DB "AVEC LA CARTE 24 ENTREES SORTIES" .DB 13,13

.DB "UTILISEZ LES FLECHES GAUCHE ET" .DB 13
.DB "DROITE POUR CHANGER LE SENS DE" .DB 13
.DB "ROTATION DU MOTEUR."
.DB 13
.DB "HAUT ET BAS POUR CHANGER LE PAS." .DB 13
.DB "SHIFT +HAUT ET BAS = PAS+10"
.DB 13
.DB "PAS :"
.DB 0

Datas
.DB 8,12,4,5,2,3,1,9

Sens
.DB 00

Step
.DB 10

WorkingArea
.DB 00,00,00,00,00,00

;---------------------------------------; print HEXA number
HPRINT:
| PSHA LSRA LSRA LSRA LSRA JSR Hex2Asc JSR OUTCA PULA JSR Hex2Asc JSR OUTCA RTS

;---------------------------------------; converti hexa en ascii
Hex2Asc:
| ANDA #$0F CMPA #$0A BPL LetAsc ADDA #$30 RTS

LetAsc
| ADDA #$30+07 RTS
| .END

### Exercice 12 (SERVOMOTEUR)

But : Piloter un servomoteur
Cet exercice présente la méthode pour piloter un servomoteur en faisant varier sa position. La sortie 5V de la carte 24 E/S ne peut pas fournir assez de courant pour alimenter le servomoteur qui devra être alimenté en 5V par une source externe (chargeur USB par exemple).


Le servomoteur est un dispositif électromécanique dont l’axe de sortie peut prendre n’importe quelle position sur un demi cercle (soit une variation totale de 180°). La commande de la position du servomoteur se fait à l’aide d’une impulsion de durée calibrée répétée au rythme de 50 fois par seconde (20ms). La durée de l’impulsion va de 1ms à 2ms. 1ms correspond à un angle de 0° tandis que 2ms correspond à un angle de 180°. La variation est linéaire sur toute la plage d’utilisation.

Figure 28: Commande d'un servomoteur


Figure 29: Commande d'un servomoteur analogique

Le programme doit être implanté en mémoire à partir de l’adresse $5000.

PORTA .EQU $BF60
PORTB.EQU $BF61
PORTC.EQU $BF62
CTRL | .EQU $BF63
OUTTX.EQU $E7A8 | ; LDX = adresse chaîne (terminé par null)
OUTCA.EQU $F9C6 | ; LDAA = code ascii
SCANK.EQU $F883 | ; <= LDAA = code ascii de la touche
; enfoncée Z = 0 aucun touche
CLS | .EQU $FBD6 ; efface l’écran
CURSOR | .EQU $3280 ; LDD = y,x du curseur

.ORG $5000

LDAA #$80 | ; place les ports A, B et C en sorties
STAA CTRL
LDAA #$00 | ; met le moteur a l'arret
STAA PORTA
LDAA #96 | ; direction initiale
STAA Direction
LDAA #10 | ; pas de déplacement initiale
STAA STEP

JSR CLS
Start
LDD #$0000
STD CURSOR
LDX #TextServo-1
JSR OUTTX

CommandServo
LDD #$090B
STD CURSOR
LDAA Direction
JSR HPRINT
LDD #$0917
STD CURSOR
LDAA STEP
JSR HPRINT

JSR SCANK
CMPA #08
BNE PasGauche
LDAA Direction
ADDA STEP
STAA Direction
JMP FIN

PasGauche
CMPA #09
BNE PasDroite
LDAA Direction
SUBA STEP
STAA Direction

PasDroite

CMPA #'O'
BNE PasO
DEC STEP

PasO
CMPA #'P'
BNE PasP
INC STEP
PasP
FIN
JSR PulseServo
JMP CommandServo
PulseServo | ; 20 ms
LDX #64*10 | ; 3µs
STX WorkingArea | ; 4
LDAA #$01 | ; 2
STAA PORTA | ; 3
LDX Direction-1 | ; 3
MS1
MUL | ; 10
DEX | ; 3
BNE MS1 | ; 3
; total cycles = 16*X+8+
LDAA #$00 | ; 2
STAA PORTA | ; 3
LDX #WorkingArea | ; 3
Timing20ms
;MUL | ; 10
DEX | ; 3
BNE Timing20ms | ; 3
RTS | ; 5
; | print HEXA number
HPRINT:
PSHA
LSRA
LSRA
LSRA
LSRA
JSR Hex2Asc
JSR OUTCA
PULA
JSR Hex2Asc
JSR OUTCA
RTS

; converti hexa en ascii
Hex2Asc:
ANDA #$0F
CMPA #$0A
BPL LetAsc
ADDA #$30
RTS
LetAsc
ADDA #$30+07
RTS

TextServo
.DB "CONTROLE D'UN SERVO MOTEUR" .DB 13
.DB "AVEC LA CARTE 24 ENTREES SORTIES" .DB 13,13
.DB "UTILISEZ LES TOUCHES GAUCHE ET" .DB 13
.DB "DROITE POUR CONTROLER LE SERVO" .DB 13
.DB "MOTEUR."
.DB 13
.DB "O ET P POUR CONTROLER LE PAS." .DB 13,13,13
.DB "POSITION : PAS :"
.DB 0

Padding
.DB 00
Direction
.DB 00
STEP
.DB 00

WorkingArea
.DB 00,00,00,00,00,00
.END

### Exercice 13 (MATRICE DE LEDS)

But : Piloter une matrice de leds
Cet exercice présente la méthode pour pilote une matrice de 8x8 leds équipée du circuit MAX7219. Ce module consomme beaucoup de courant. Il faut donc faire appel à une source d’alimentation externe (un chargeur USB par exemple).


Figure 30: Contrôle d'une matrice de leds


Figure 31: Signaux de contrôle de la matrice

Le contrôle de l’affichage est assuré par un circuit spécialisé (MAX7219) qui communique à l’aide de 3 fils avec la carte d’E/S. Les chronogrammes montrent les signaux à utiliser. La communication se fait en série par blocs de 16 bits.
Le programme est à éditer en mémoire à partir de l‘adresse $5000.
CLK_HIGH_PIN | .EQU $01
CS_HIGH_PIN | .EQU $02
CS_LOW_PIN | .EQU $00
CLK_LOW_PIN | .EQU $00
PORTA | .EQU $BF60
PORTB | .EQU $BF61
PORTC | .EQU $BF62
CTRL | .EQU $BF63

.ORG $5000

LDAA #$89 | ; PORTA et PORTB en sortie, PORTC en entrée
STAA $BF63 ;
LDAA #CS_HIGH_PIN+CLK_HIGH_PIN
STAA PORTA
JSR $FBD6 | ; efface l’écran
Start
LDD #$0000
STD $3280 | ; LDD = y,x du curseur
LDX #TextMatrix-1
JSR $E7A8 | ; LDX = adresse chaîne
LDX #DataInit | ; initialisation du MAX7219
Init7219
LDAA #CS_LOW_PIN+CLK_HIGH_PIN
STAA PORTA
LDAA 0,X
INX
PSHX
JSR Shifting8
PULX
LDAA 0,X
INX
PSHX
JSR Shifting8
LDAA #CS_HIGH_PIN+CLK_HIGH_PIN STAA PORTA
PULX
CPX #FinInit
BNE Init7219

BoucleAff
LDX #Font | ; affichage 6502MAN
STX WorkingArea+2
NextCar
LDAA #01
STAA WorkingArea
Affichage
LDX WorkingArea+2

CPX #FinFont
BEQ BoucleAff
LDAA #CS_LOW_PIN+CLK_HIGH_PIN STAA PORTA
LDAA WorkingArea
JSR Shifting8
LDX WorkingArea+2
LDAA 0,X
INX
STX WorkingArea+2
JSR Shifting8
LDAA #CS_HIGH_PIN+CLK_HIGH_PIN STAA PORTA

LDAA WorkingArea
INCA
STAA WorkingArea
CMPA #$09
BEQ PausingFrame
BNE Affichage
PausingFrame
JSR Wait
JMP NextCar

Wait
LDAB #$02
Tempz
LDX #$FFFF
Tempo
DEX
BNE Tempo
DECB
BNE Tempz
RTS

; envoi l'octet contenu dans A bit par bit
; en commençant par le MSB.
;
Shifting8 | ; A = octets à envoyer
PSHA
LDX #$0008
Shift
LDAA #CS_LOW_PIN+CLK_HIGH_PIN STAA PORTA
PULA
LDAB #$00
ASLA
ADCB #$00
STAB PORTB
PSHA
LDAA #CS_LOW_PIN+CLK_LOW_PIN STAA PORTA
DEX
BNE Shift
LDAA #CS_LOW_PIN+CLK_HIGH_PIN STAA PORTA

PULA
RTS

TextMatrix
.DB "CONTROLE D'UNE MATRICE DE LEDS" .DB 13
.DB "AVEC LA CARTE 24 ENTREES SORTIES" .DB 13,13,0

Font
.DB $00,$FF,$00,$FF,$00,$FF,$00,$FF
.DB $FF,$00,$FF,$00,$FF,$00,$FF,$00

.DB $7E,$80,$80,$FC,$82,$82,$82,$7c ;6 .DB $7E,$80,$80,$FC,$02,$02,$02,$7C ;5 .DB $7E,$C1,$A1,$91,$89,$85,$83,$7E ;0 .DB $3E,$42,$04,$08,$10,$20,$40,$7E ;2 .DB $00,$C3,$A5,$99,$81,$81,$81,$81 ;M .DB $7E,$81,$81,$FF,$81,$81,$81,$81 ;A
.DB $00,$C1,$A1,$A1,$91,$89,$85,$83 ;N
FinFont

DataInit .DB $09, $00, $0A, $01, $0B, $07, $0C, $01, $0F, $00 FinInit

; Decode-Mode Register (Address (Hex) = X9)
; | No decode for all lines | = $00
; | |

; Intensity Register (Address (Hex) = XA)
; | Minimum (01/32) | = $00
; | |
; | Maximum (31/32) | = $0F

; Scan-Limit Register (Address (Hex) = XB)
; | Display line 1 | = $00
; | Displey line 1 to 2 = $01
; | |
; | Display line 1 to 8 = $07

; Shutdown Register (Address (Hex) = XC)
; | Shutdown mode | = $00
; | Normal opération | = $01

; Display-Test Register (Address (Hex) = XF)
; | Normal opération | = $00
; | Display test Mode = $01

WorkingArea
.DB 0,0,0,0,0,0
.END

### Question

Comment faut-il modifier le programme pour piloter 3 matrices simultanément ?

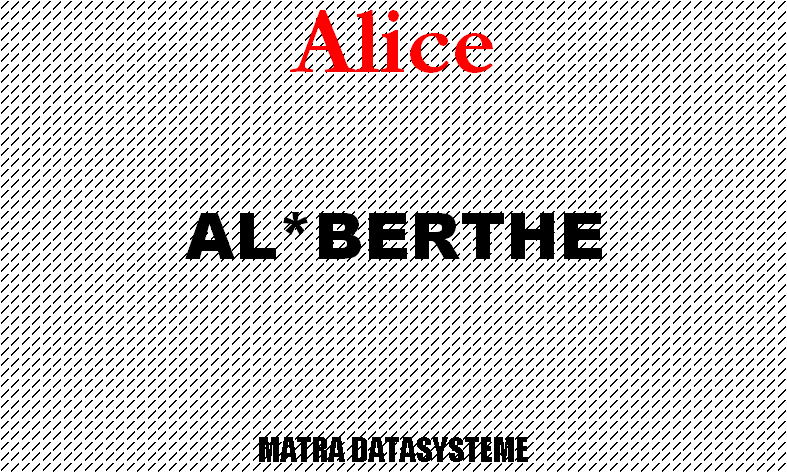
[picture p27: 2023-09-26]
Cartouche/Etiquettes/Alberthe_Etiquette.png

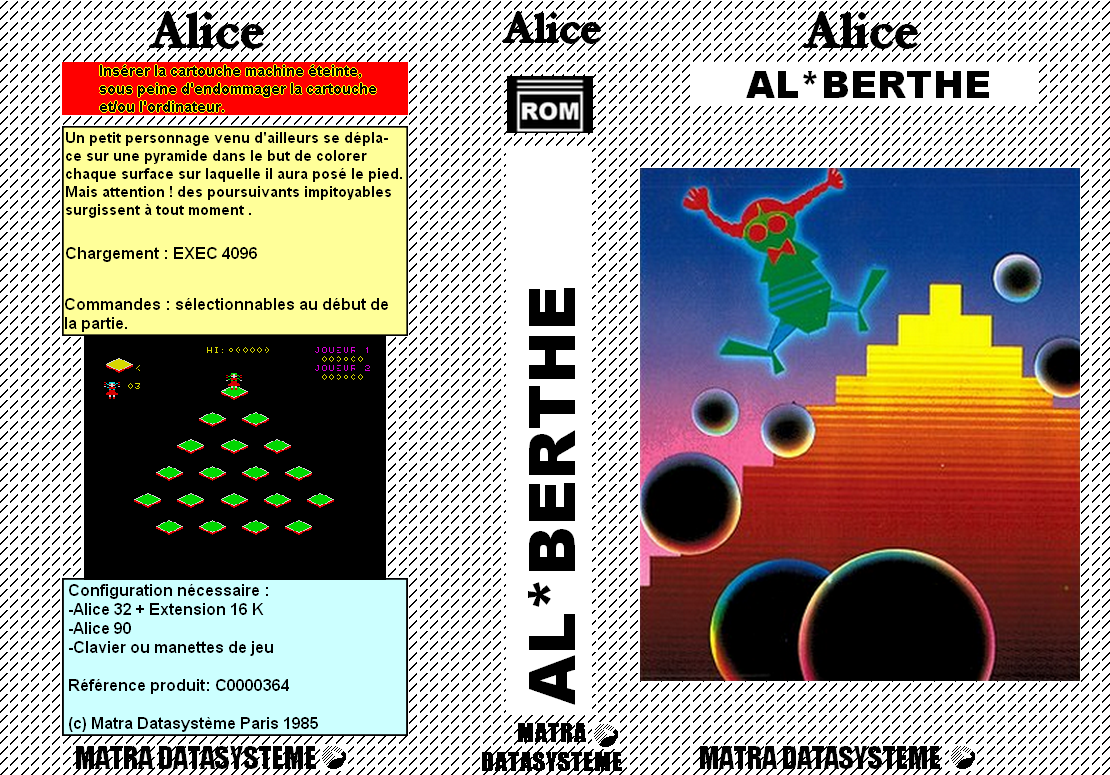
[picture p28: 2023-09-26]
Cartouche/Jaquettes/Alberthe_Jaquette.png

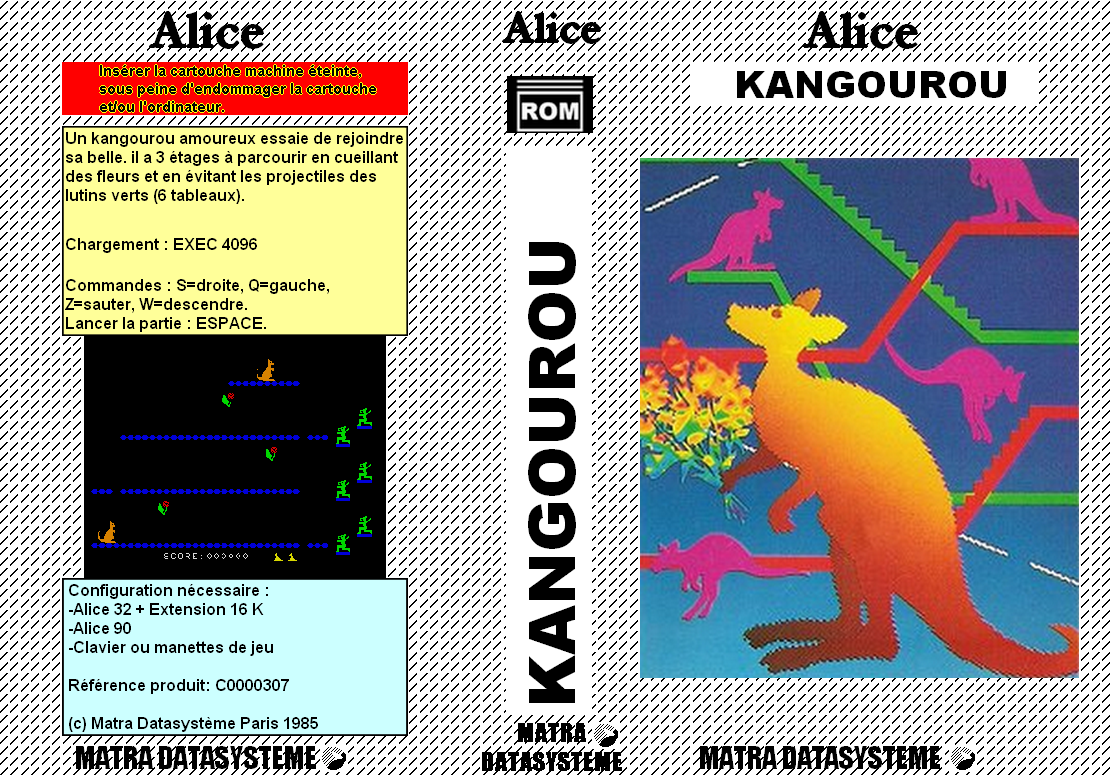
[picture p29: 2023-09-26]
Cartouche/Jaquettes/Kangourou_jaquette.png

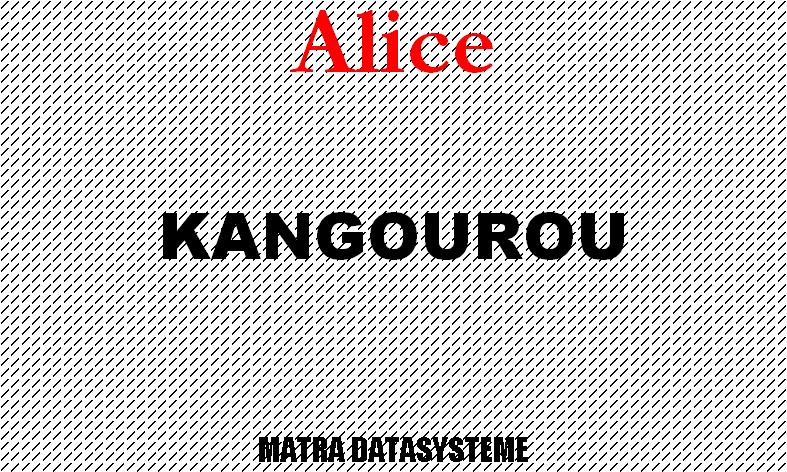
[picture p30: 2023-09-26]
Cartouche/Etiquettes/Kangourou_Etiquette.png

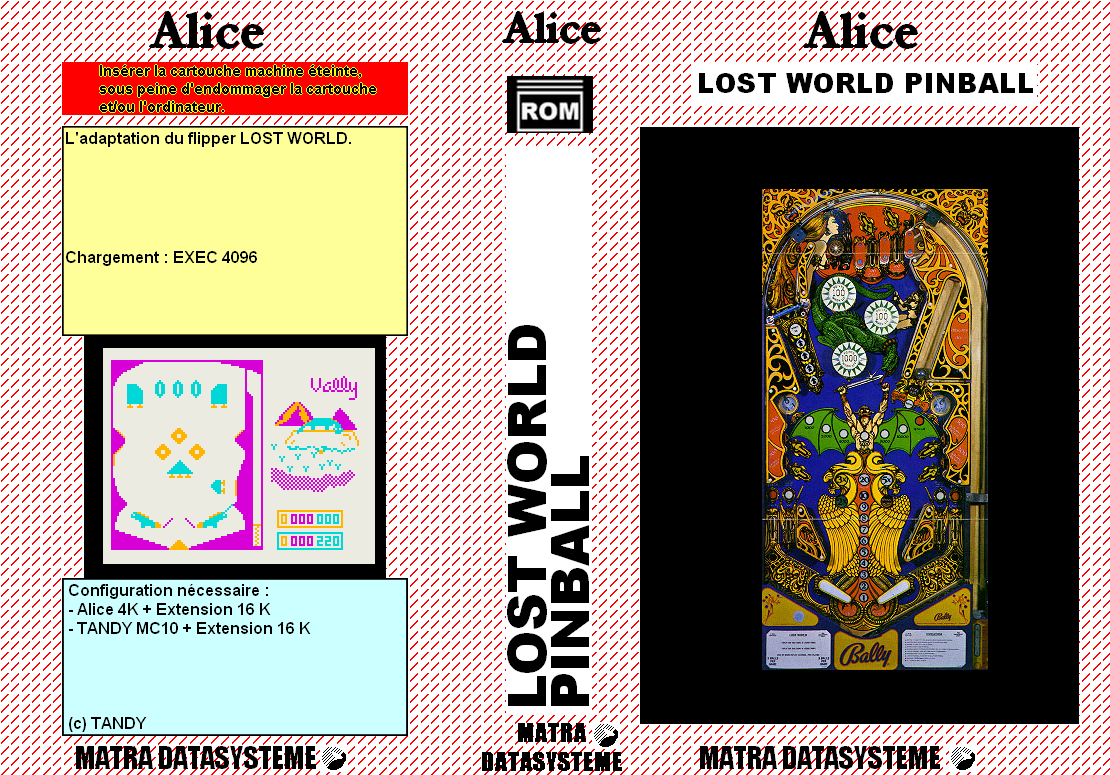
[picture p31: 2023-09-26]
Cartouche/Jaquettes/4K_LostWorld_Jaquette.png

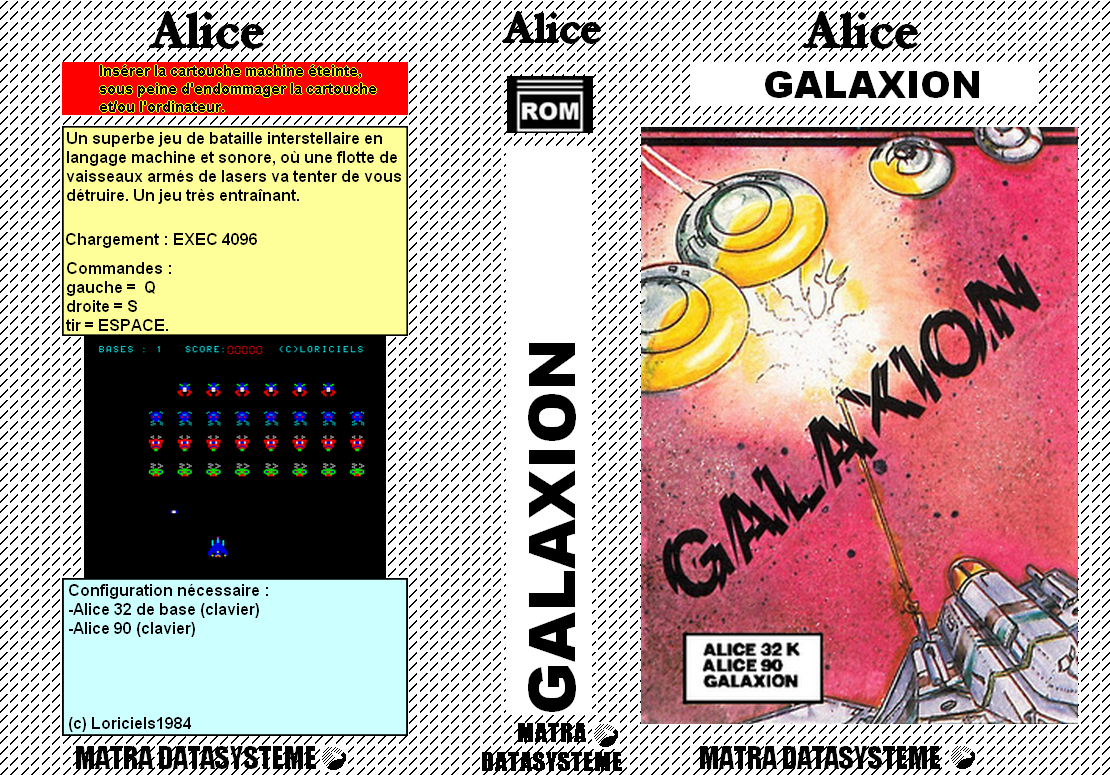
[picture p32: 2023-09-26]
Cartouche/Jaquettes/Galaxion_Jaquette.png

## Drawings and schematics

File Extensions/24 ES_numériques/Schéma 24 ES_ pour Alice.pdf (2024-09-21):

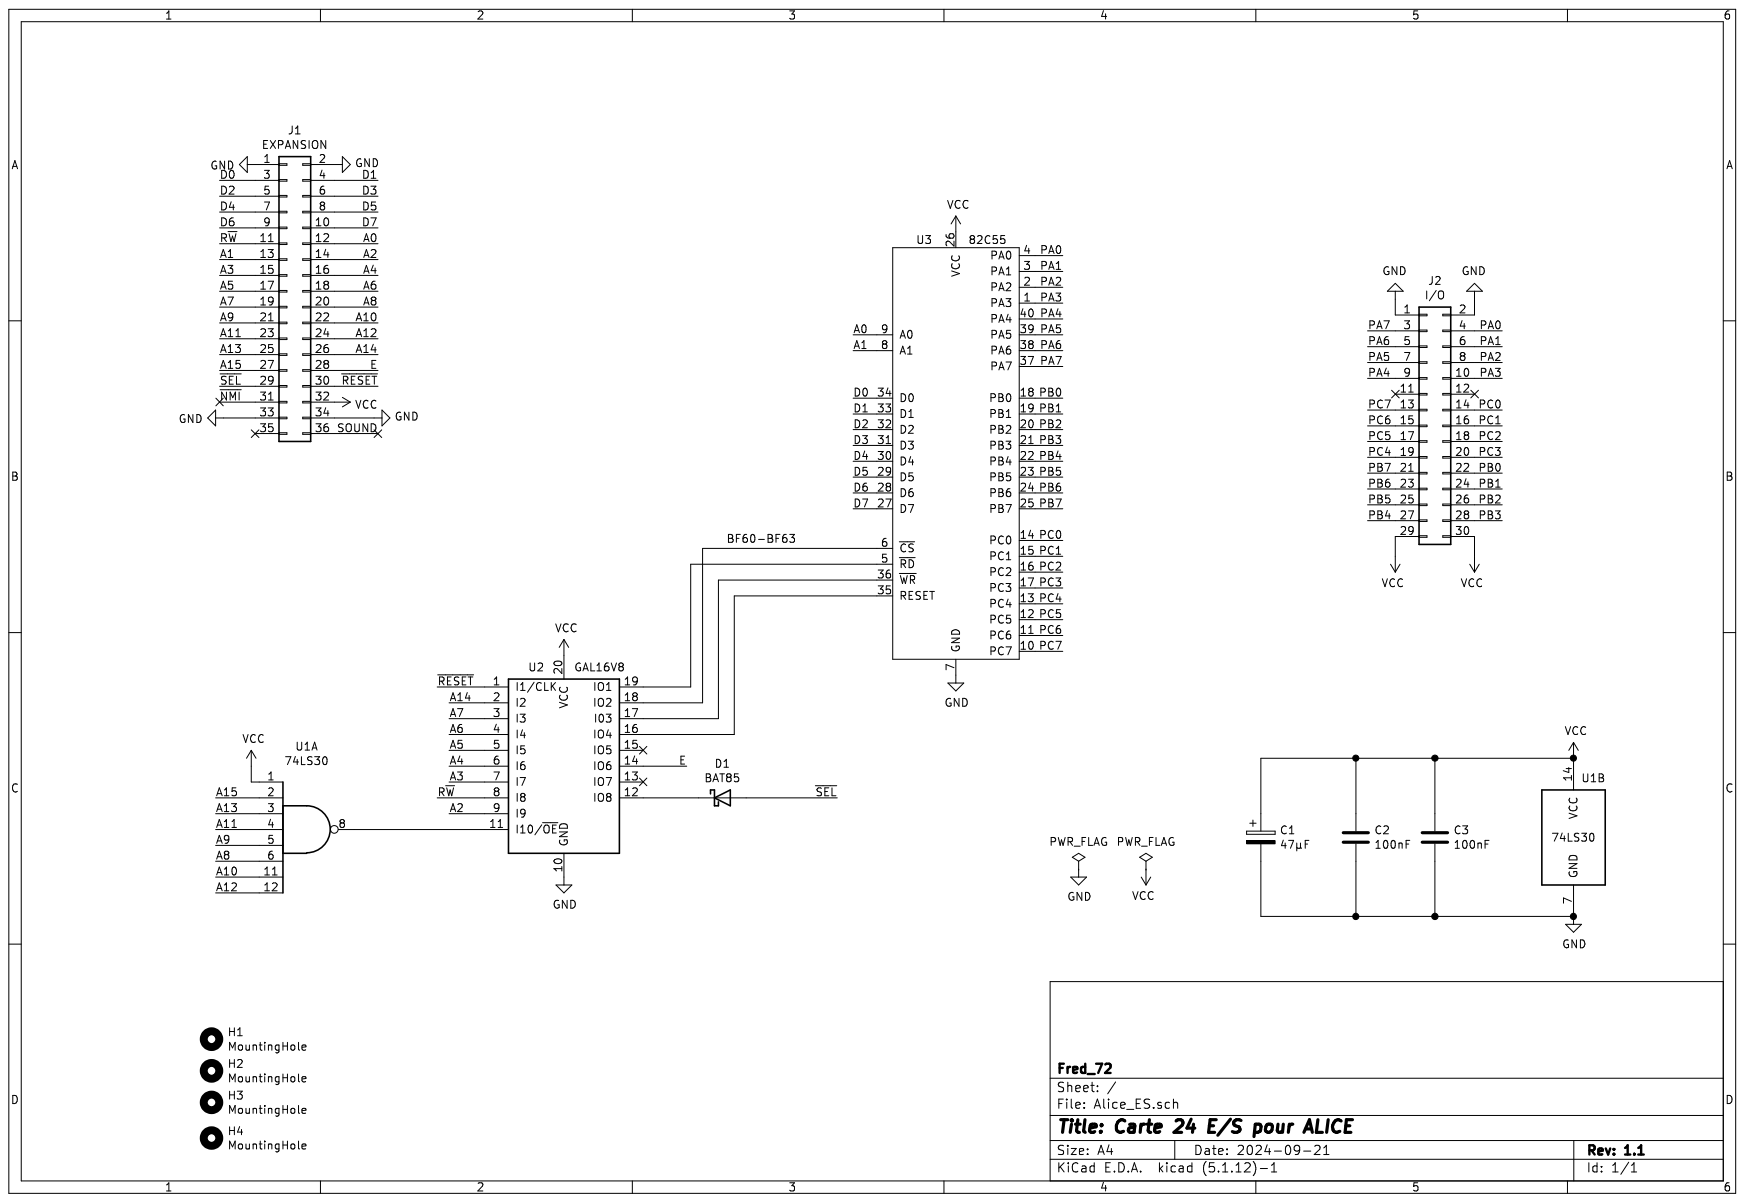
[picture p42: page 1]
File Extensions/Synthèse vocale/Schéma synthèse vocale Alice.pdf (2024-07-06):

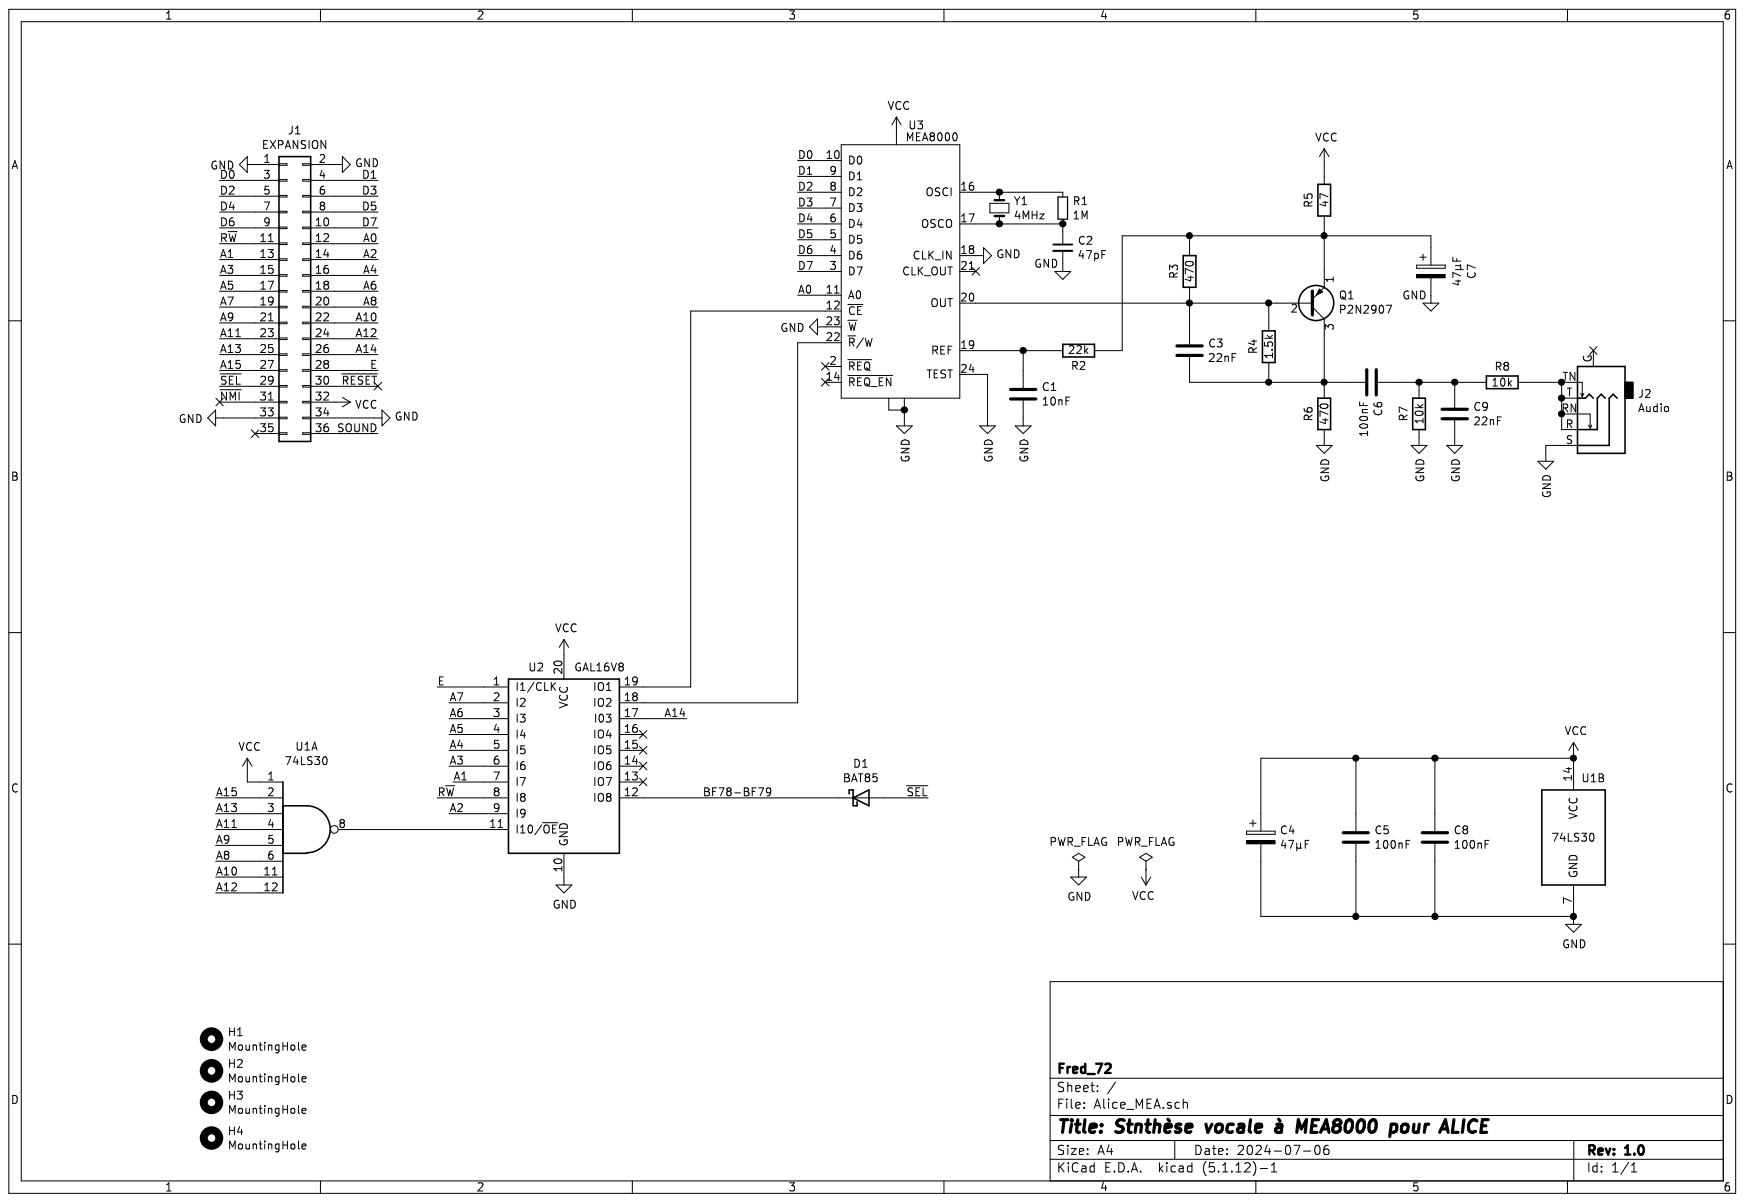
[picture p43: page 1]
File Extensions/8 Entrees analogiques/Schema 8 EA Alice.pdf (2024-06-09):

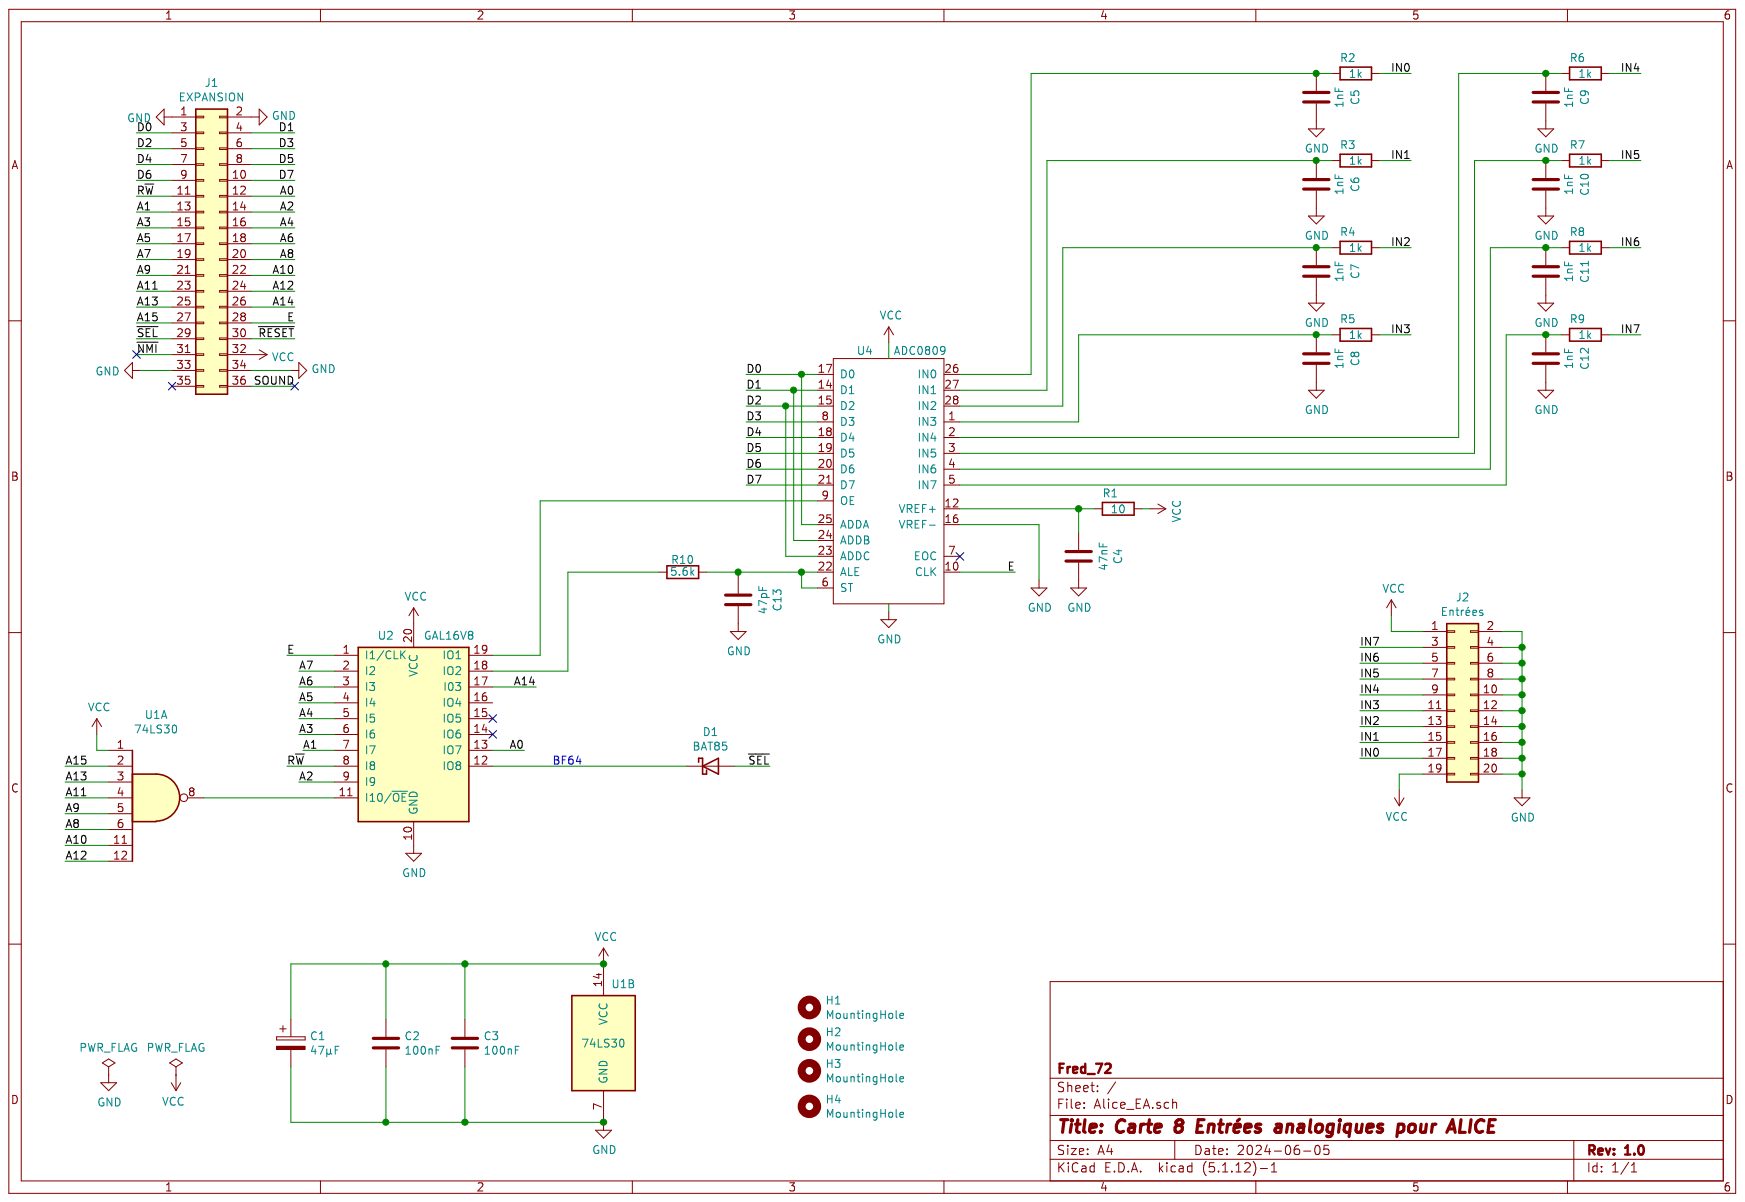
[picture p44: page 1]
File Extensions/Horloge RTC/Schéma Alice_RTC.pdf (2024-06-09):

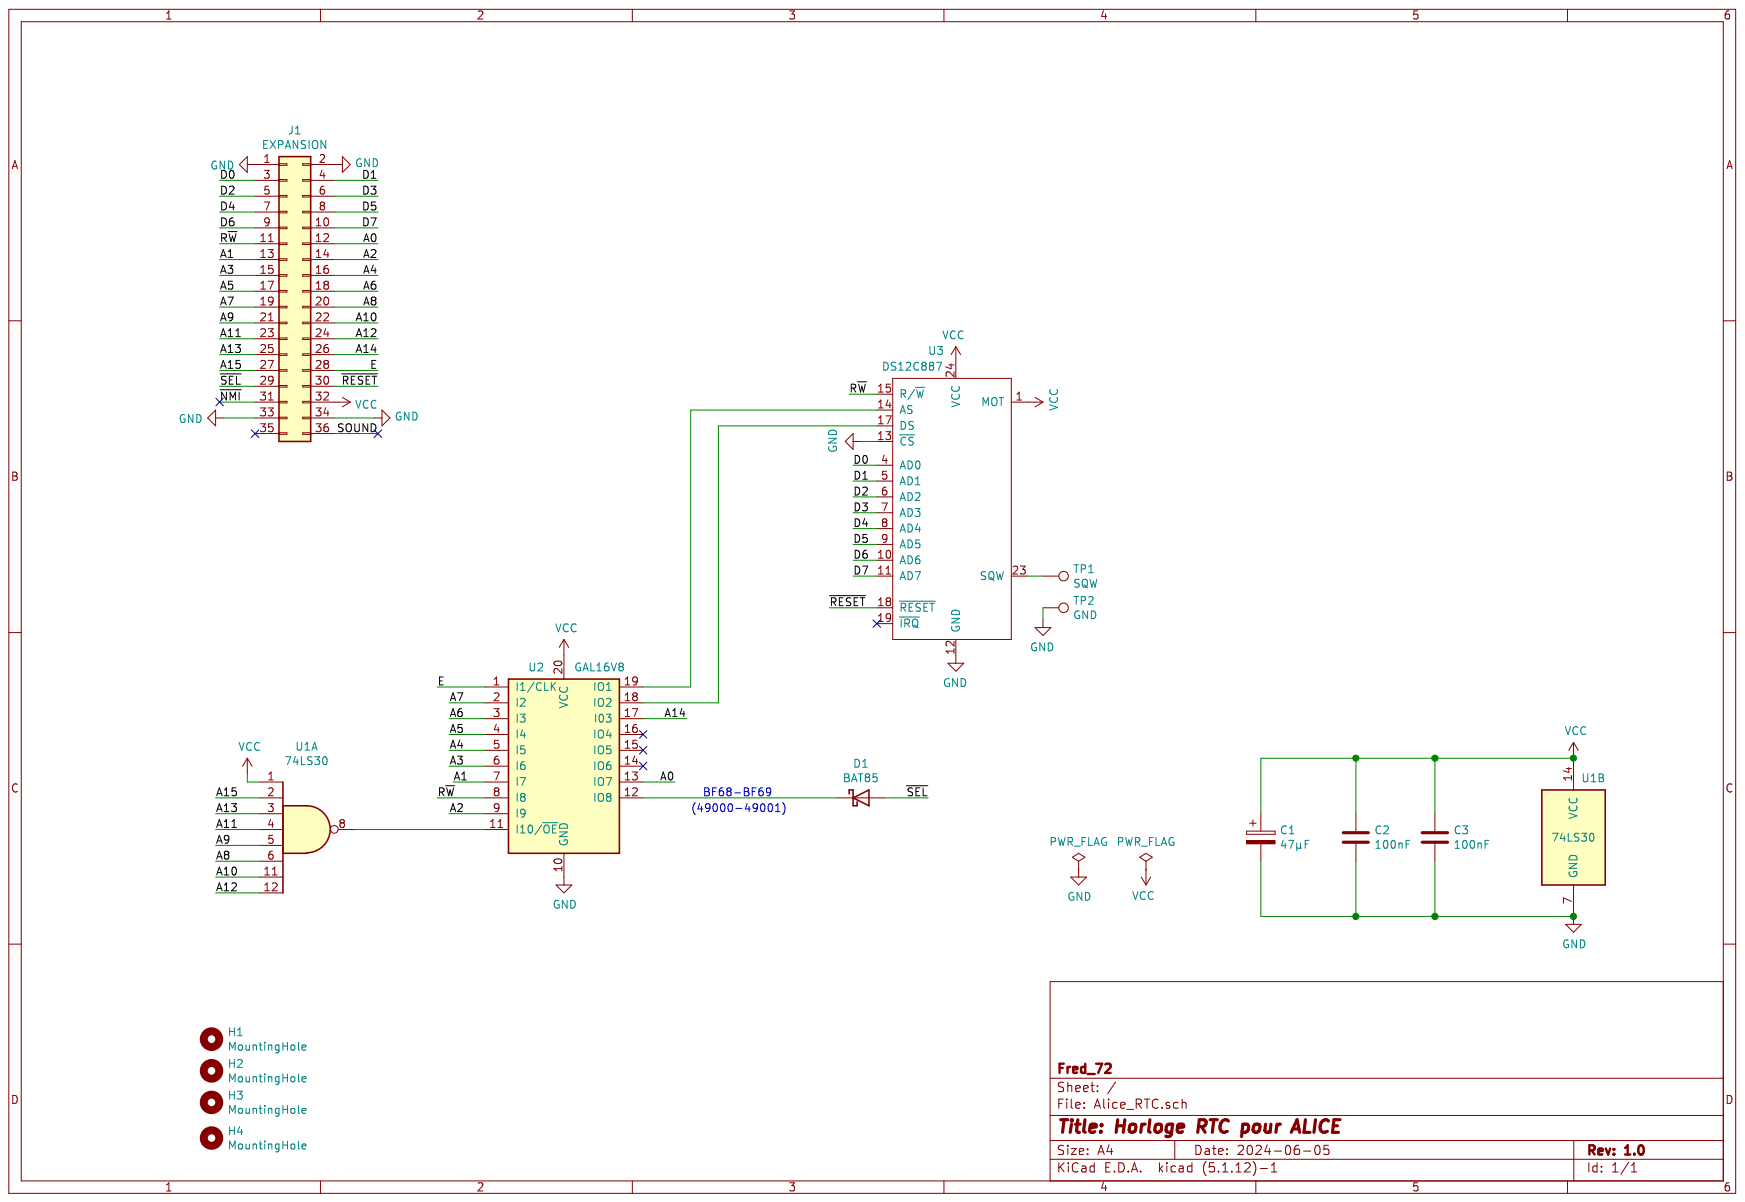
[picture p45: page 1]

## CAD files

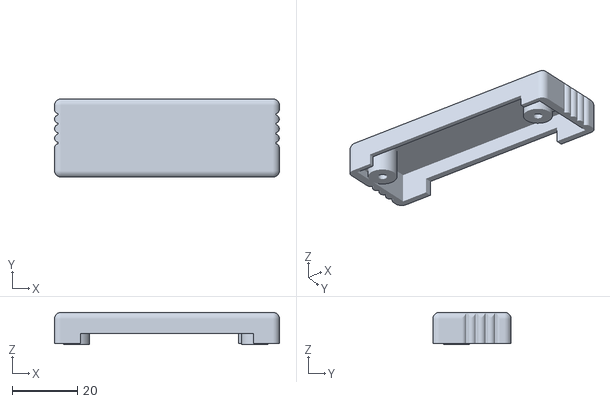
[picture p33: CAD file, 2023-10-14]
3D/Adaptateur_sup.stl
69.0 x 24.0 x 9.90

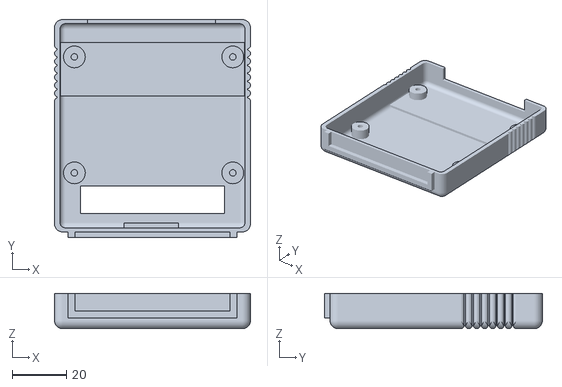
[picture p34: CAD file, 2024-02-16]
Extensions/24 ES_numériques/3D/boitier_A.stl
72.0 x 80.0 x 13.0

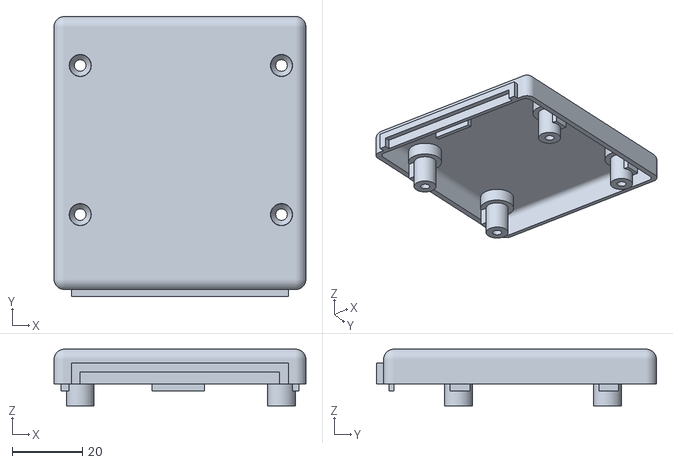
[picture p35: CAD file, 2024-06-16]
Extensions/Horloge RTC/3D/boitier_RTC_Back.stl
72.0 x 80.0 x 16.2

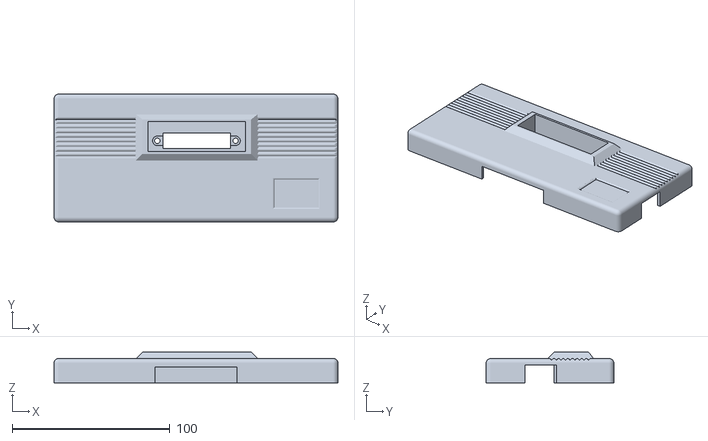
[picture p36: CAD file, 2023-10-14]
3D/Boîtier_sup.stl
180.0 x 81.0 x 19.4

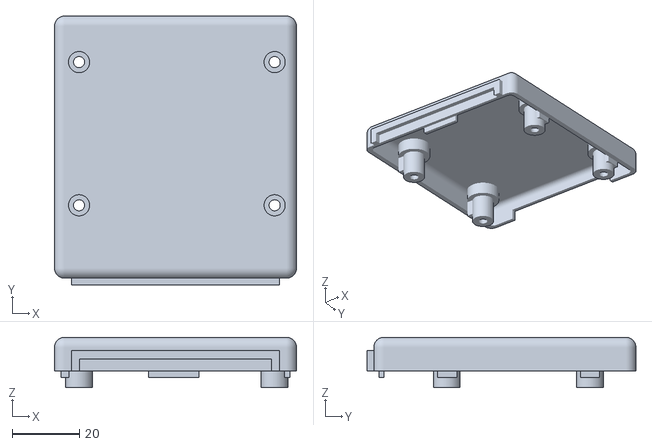
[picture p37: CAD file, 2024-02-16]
Extensions/24 ES_numériques/3D/boitier_B.stl
72.0 x 80.0 x 15.0

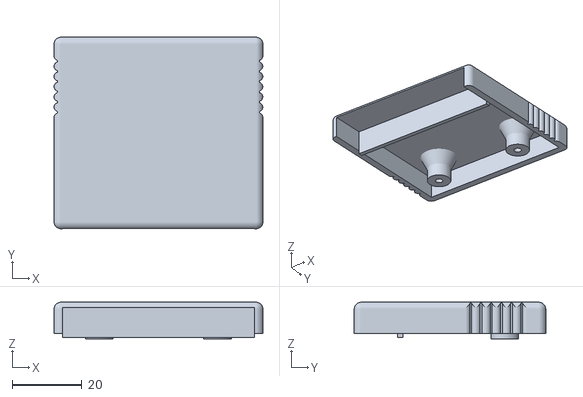
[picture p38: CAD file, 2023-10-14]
3D/Cartouche_sup.stl
60.0 x 55.0 x 10.5

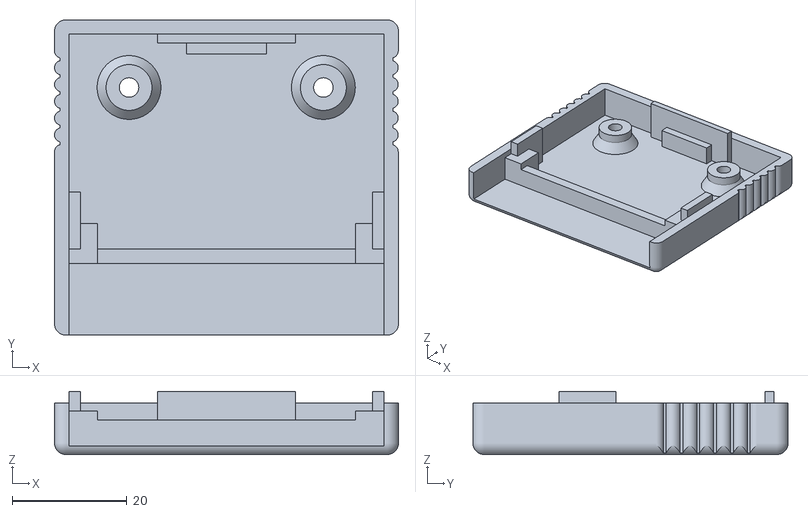
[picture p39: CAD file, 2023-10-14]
3D/Cartouche_inf.stl
60.0 x 55.0 x 11.0

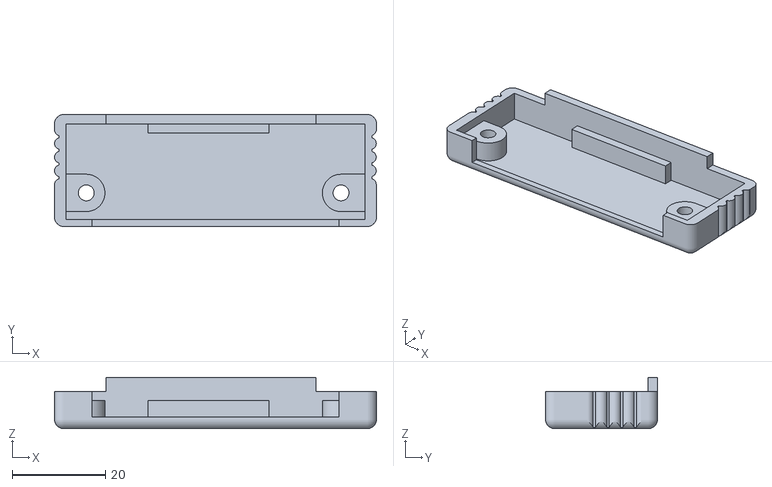
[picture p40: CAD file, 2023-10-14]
3D/Adaptateur_inf.stl
69.0 x 24.0 x 11.0

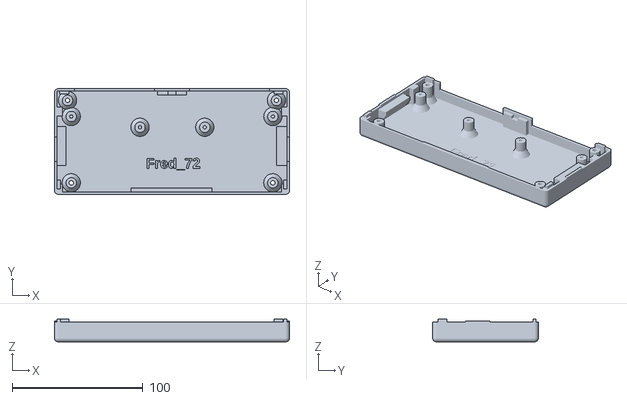
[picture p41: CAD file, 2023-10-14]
3D/Boîtier_inf.stl
180.0 x 81.0 x 17.5

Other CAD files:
Extensions/8 Entrees analogiques/3D/boitier_EA_front.stl
Extensions/Synthèse vocale/3D/Boitier_MEA_Back.stl
Extensions/8 Entrees analogiques/3D/boitier_EA_back.stl
Extensions/Horloge RTC/3D/boitier_RTC_Front.stl
Extensions/Synthèse vocale/3D/Boitier_MEA_Front.stl
